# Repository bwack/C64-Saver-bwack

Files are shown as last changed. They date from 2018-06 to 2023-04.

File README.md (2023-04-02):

C64 Saver v1 and v2
- Overvoltage protection for the C64 and its power brick.

Designed by BWACK 2018
CERN OPEN HARDWARE LICENSE v1.2
http://www.ohwr.org/

The KiCad and other design files are available on GitHub:
https://github.com/bwack/

All text above must be included in any redistribution

# Warning: latest version of the savers are not tested.

# Bwack's C64 saver designs.

The C64 Saver 2 is an open-source project intended to make overvoltage protection available and easy to make for anyone interested in using the old Commodore power brick together with the C64. The power brick is 30-40 years old, and it is known for failure with overvoltage. This is caused sometimes because of broken solder joints on the regulator or the regulator itself failing.

## What has changed in v2 ?
- The design is modular.
- Spike protection. Handles hotswapping and switch bouncing better.
- It is much much easier and faster to make. Most people can make it!

## The base board (C64 Saver 2 SMD or Throughhole)
The base board is all you need for overvoltage protection. Through hole parts except for the mosfet, but it is large and easy to solder, no special tools needed other than your solder iron. The board shape fits the Hammond 1551g project case.
* Note: You need to bridge pin 4 and 5 in J2 and pin 4 and 5 in J4 if you are not using the base board in combination with the addon board or the relay board. The reason for this is that, with the addon board, we need to route the current through a sensing circuit. When the addon board is not used, we need to route it directly to the mosfet and terminals.

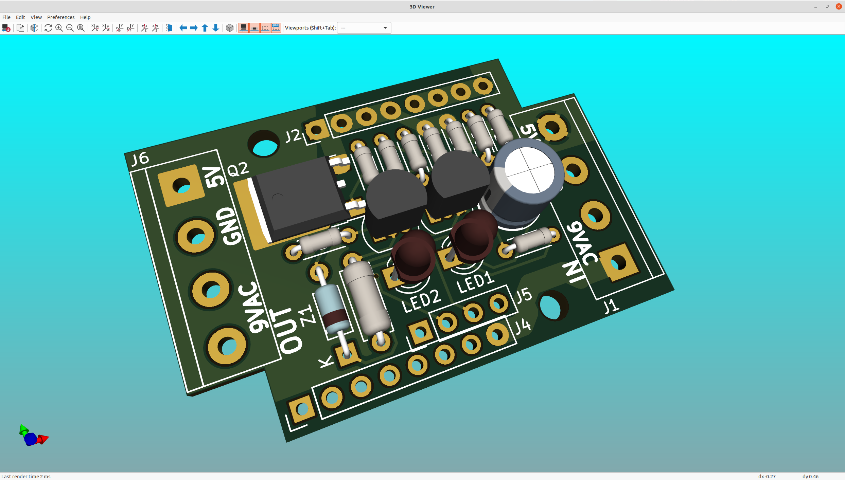
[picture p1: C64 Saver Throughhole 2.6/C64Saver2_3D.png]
C64 Saver 2 3D
 
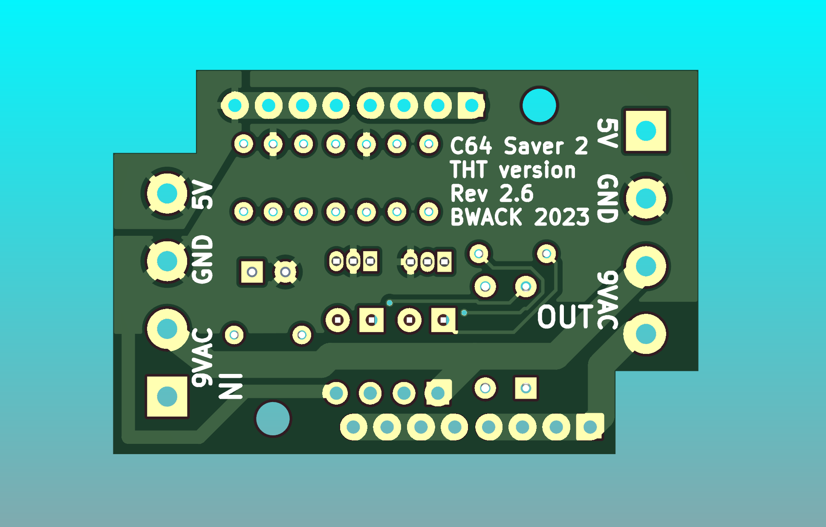
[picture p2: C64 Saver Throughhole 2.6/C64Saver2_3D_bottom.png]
C64 Saver 2 3D_bottom
 
 
There is also a SMD version for those who like to reflow soldering.

## The addon board
The C64 saver addon board is a hat for the base board, and adds software control, instrumentation on both ac and dc side, and an optional 128x32 OLED display. The aim for this project is to make a tool for C64 repairers. The 9VAC and 5VDC are fully isolated. Software control and instrumentation is useful if you are repairing C64s. You can set the output to shut down in case of an overcurrent condition. If an overvoltage happens you can configure the saver to auto reset or keep the power from comming back on again. There are several reasons why you might want this. C64 PSUs that need service, the capacitors are dry and the 5VDC has an AC component on it. The saver would normally just go on and off at 100Hz. The software control can detect this. The other problem is if the computer has a faulty chip that cause massive current draw on the 5V. The fuse might not blow because it is not enough, then you can configure the saver cut if you desire. I'm not gonna lie. This is my pet project, and the cost has not been a topic on my mind.

The C64 Saver Addon Board 1.4:

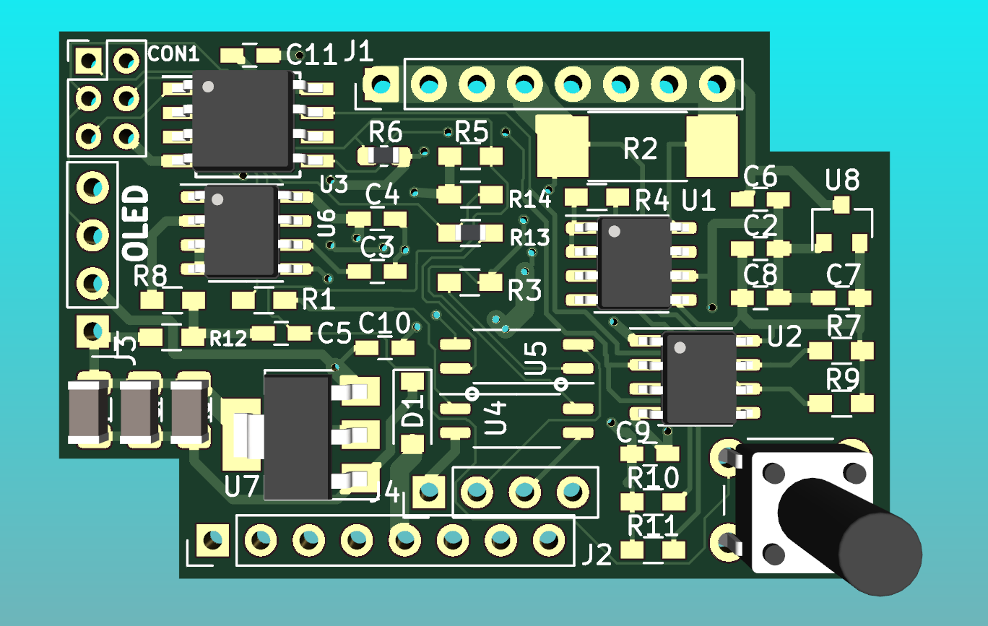
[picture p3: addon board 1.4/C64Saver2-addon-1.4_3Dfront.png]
C64 saver addon_board


Youtube video of me testing the addon board installed on the C64 Saver 2.

YouTube: Testing_the_addon_board (http://www.youtube.com/watch?v=oYrapS5jUx8)

The relay and hold board is archived in the oldfiles folder.

## C64 Saver OCP

OCP, not robocop, but overcurrent protection. Is a new circuit that I'm working on. It has three LEDs and a button. The overvoltage protection circuit is the same as before. The overcurrent will light the yellow led and keep it lit and keep the output OFF after an overcurrent event.

## The old design
I have decided to release my older C64 Saver v1. The board that fits inside a connector. Time and skill is super high on this product so be warned ! (SMD 0603, solder blob connections, tight spaces and short circuit hazards).

## Gerbers
If you are looking for gerbers, click the releases tab. There you will find a zip file of gerber for each release.

# BOM
All bill of materials (BOM) are moved into the respective project folders. I have added digikey etc order no. in the parts in the schematics such that they will show up in the interactive boms.

Here are the interactive BOMs:

[ibom for C64 Saver Throughole 2.6](https://htmlpreview.github.io/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)

[ibom for C64 Saver SMD 2.6](https://htmlpreview.github.io/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)

[ibom for C64 Addon Board 1.4](https://htmlpreview.github.io/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)

[ibom for C64 Saver OCP 0.1](https://htmlpreview.github.io/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)

# Changelog:

- C64 Saver 2.6 (THT+SMD) and Addon Board 1.4 (2023-04-02)
  - Replaced 7n2002 with BC547/BC847 to fix the tolerance issues.
  - Throughhole and SMD: same version numbers, same circuits, same reference numbers.
  - Red LED is switched by TL431 and Green by BC547/BC847.
  - Added LEDs to the Throughhole version. It was a challenge.
  - Fix: The Addon Board 1.3 had incorrect pinout for the 5V reg.
  - I never tested the Addon Board 1.3, but thanks to Retroisten who sent.
  me images and advicing me about he pinout, I'm very happy about it. He also
  showed me that it does work, with the regulator hacked in.  In this version 1.4
  it is working.

- C64 Saver 2.5 (SMD) (2020-09-13)
  - Added fault LED and power LED
  - 0805 SMD resistors
  - SOT23-5 TL431 and NMOS

- RelayHold 0.2 (2019-08-25)
  - Initial release
  - All through-hole parts.

- Addon Board 1.3 (2019-05-24)
  - Changed optocoupler footprint to more common SOIC-4_4.55x2.6mm_P1.27mm
  - Larger 5V regulator on 9vac side for less heat
  - replaced 100uF tantalum with 3x 47uF 1206 MLCC
  - kicad 5.1.0 project

- Addon Board 1.2 (2018-11-11)
  - Swapped HOLD_ with SENSE_VAC on the MCU. SENSE_VAC needs ADC.
  - Correct the mixed up SDA and SCL.
  - 5V supply to the 5V section is moved to VIN+ (before the shunt).
    To not pull power through the sensing resistor.
  - 4k7 I2C pullups.https://htmlpreview.github.io/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

- C64 Saver 2.4 (2018-09-23)
  - Support lower Vth on Q1. Resistor divider R7 and R8.
  - Remove C2 to make room for resistor divider.
  - Changed R5 to 3k3 to reduce BOM size.
  - New layout and routing.

- Addon Board 1.1 (2018-09-23)
  - ATtiny85 is a 8S2 package and two mm wider than SOIC8.
  - Read overvoltage signal on reset pin using ADC. Added voltage divider.
  - Replace MCP1700 with MCP1703. Supporting higher Vin_max

- C64 Saver 2.3 (2018-08-18)
  - Q1 2N7002 pin 1 and 2 rotated
  - Q2 Reversed drain and source
  - Increased pullup on Q1 drain.
  - Repurposed R5 as pullup for Q1 drain.
  - tested bodged v2.2 prototype, wohttps://htmlpreview.github.io/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!

- C64 Saver 2.2 (2018-08-16)
  - R1 was rotated.

- C64 Saver 2.1 & Addon 1.0 (2018-07-23)
  - 5x 9VAC pins. 9VAC1 current (4x) + 9VAC2.
  - Moved GND pin.
  - Changed board size to fit Hammond1551g
  - C64 Saver board:
    - Smaller throughole resistors
    - Moved C1 closer to input circuits.
  - Addon board:
    - VAC sense circuit with voltage divider.
    - 5V regulator on VCC pin. RAW pin disconnected.
    - Pullups on I2C busses.
    - SSOP-4 optocoupler packages
    - Another regulator on the 5V side to protect the iso1541 and ina219.

- C64 Saver 2.0beta & Addon 1.0beta (2018-07-02)
  - New design.
  - Protected sensitive parts.
  - baseboard: throughhole parts.
  - C64 saver 2 addon board.
  - problem: has conflicting pinouts.

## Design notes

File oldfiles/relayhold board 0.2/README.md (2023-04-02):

# The C64 Saver 2 relay hold board

The addon board is for many hard to make. I was thinking, what about making a board that doesn't need to be programmed, that can cut 9VAC, and optionally keep the outputs disabled even if the fault goes away. This circuit is it. It was more of an experimental circuit. I've therefor archived it here.

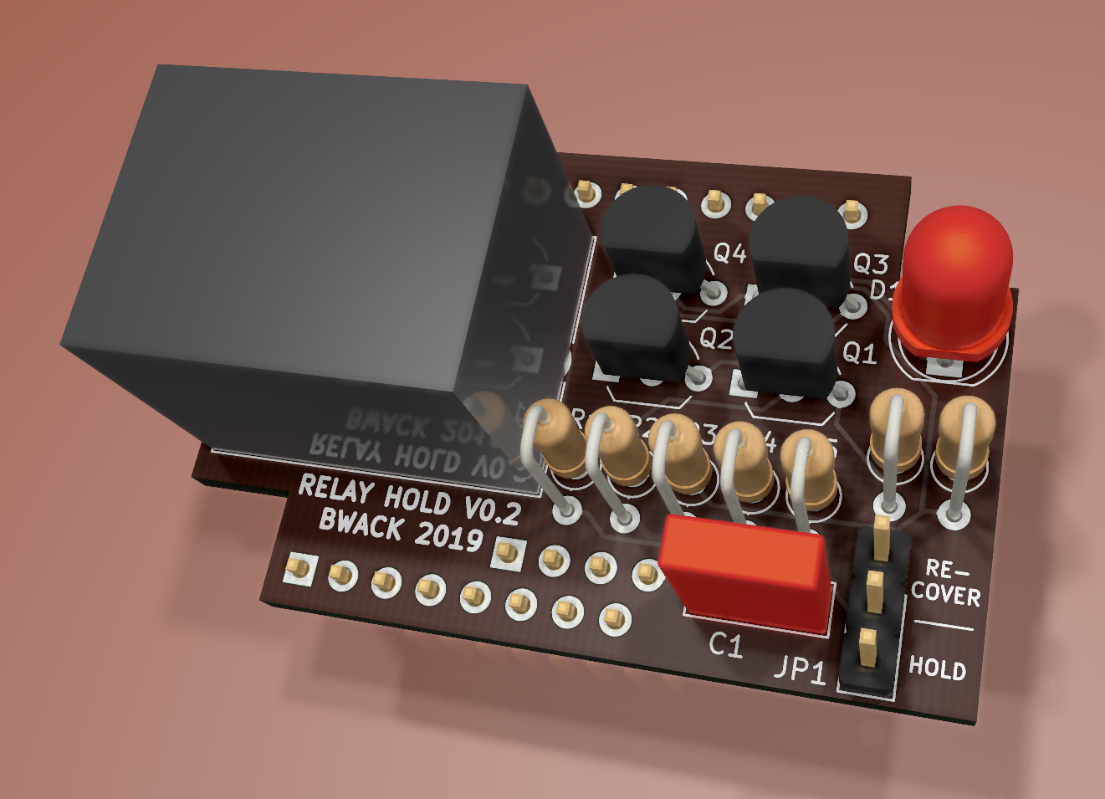
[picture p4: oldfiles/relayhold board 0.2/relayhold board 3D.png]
C64 saver relay hold 0.2


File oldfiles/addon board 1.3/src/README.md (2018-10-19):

# Firmware for the addon board

Build source code with avr-gcc.
This section is under construction.

## Programming
Program the addon board using USBasp or other AVR programming ISP device.
Arduino as ISP does also work. The ISP header has 2mm pitch, and the pinout is standard 2x3 way ISP pinout. You program the board with the main.hex file. It is found under the releases tab.

## Developing
To build the project you need to download the C64-saver-bwack repository from github.
From there you will get the sources for the addon board.
Download the WinAVR (windows), or avr-gcc (linux, mac). The avrdude version might not be
compatible with your USBasp. Download arduino also, and copy avrdude from it and into your WinAVR bin folder.

In the src folder you can clean, build and program.
- make clean
- make
- make install

## contributing to the Github repository
Fork the project and make your changes. Make sure you "make clean" before push to the repo. We only want source code in the repo. Have fun!

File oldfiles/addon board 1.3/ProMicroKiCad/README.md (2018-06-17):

Pro Micro library for KiCAD
=======================================

This repo includes Pro Micro library.

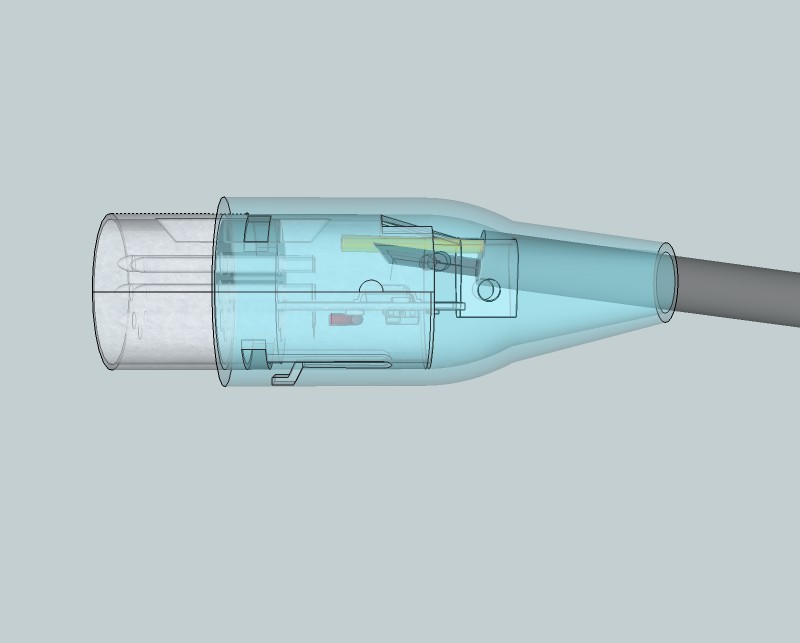
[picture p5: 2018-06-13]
oldfiles/C64 Saver 1/1.1-1.3/sketchup/c64saver_v1.2_Xray3D.jpg

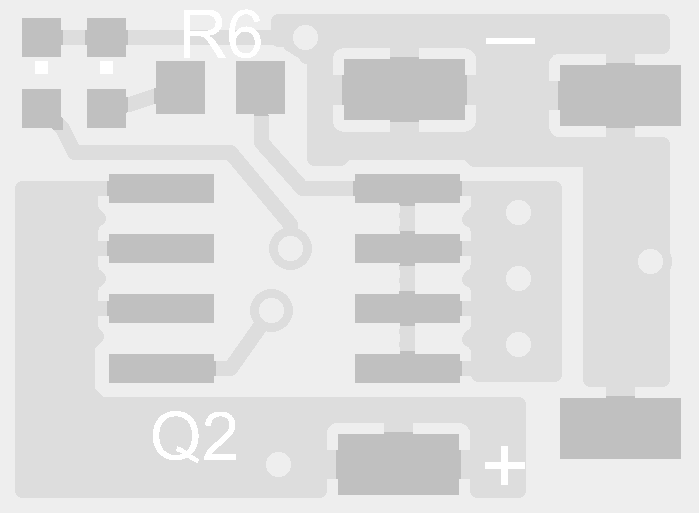
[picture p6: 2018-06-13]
oldfiles/C64 Saver 1/1.1-1.3/eagleUp-export/eagleUp_c64saver_1.3_board_bottom.png

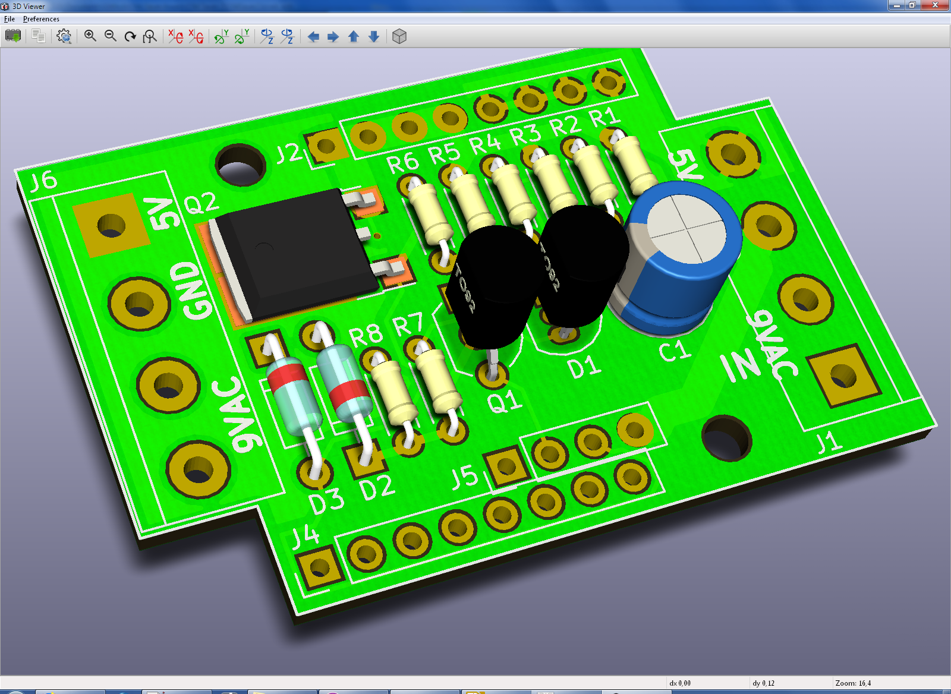
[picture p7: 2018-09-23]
oldfiles/C64 Saver Throughhole 2.4/C64Saver2_3D.png

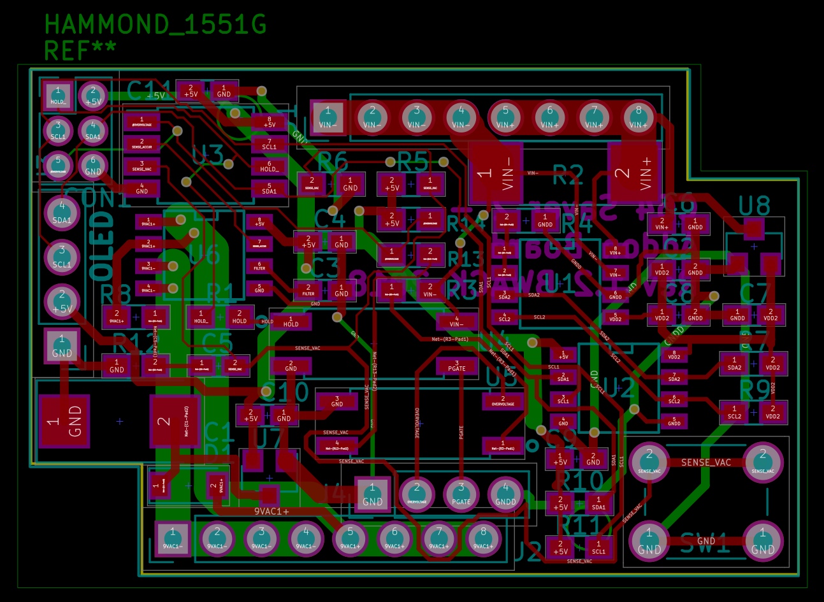
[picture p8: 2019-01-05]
oldfiles/addon board 1.3/C64Saver2-addon.kicad_pcb_1_2.jpg

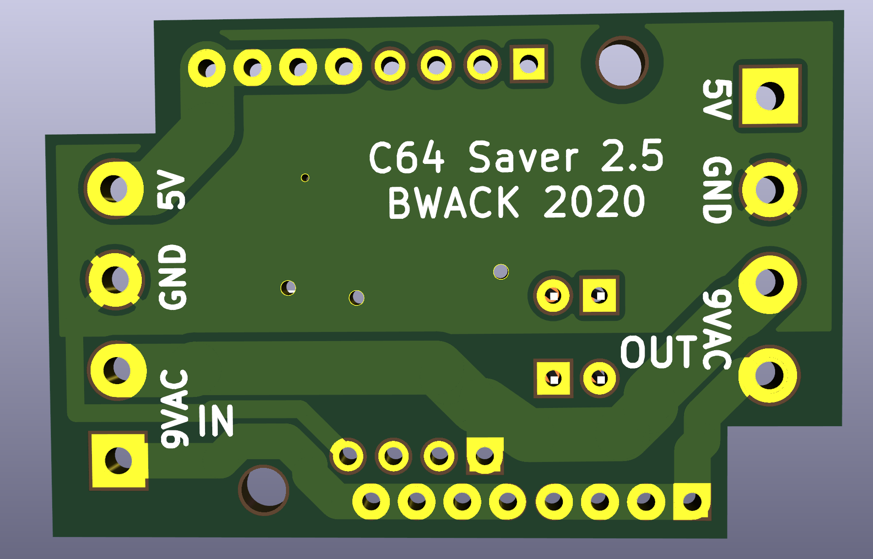
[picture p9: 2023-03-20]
oldfiles/C64 Saver SMD 2.5/C64Saver2_3D_bottom.png

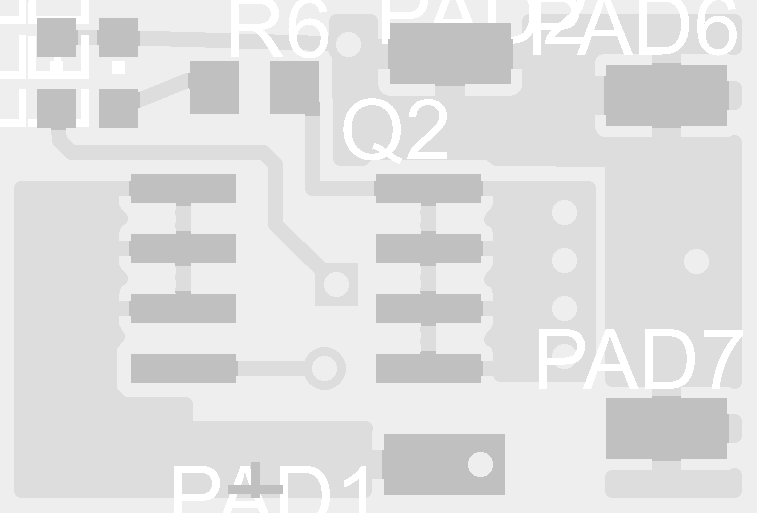
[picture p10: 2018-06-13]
oldfiles/C64 Saver 1/1.1-1.3/eagleUp-export/eagleUp_c64saver_1.2_board_bottom.png

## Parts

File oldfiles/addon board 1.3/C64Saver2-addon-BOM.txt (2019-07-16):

BOM for the C64 Saver 2 addon board v1.3
======================================== 

To be updated !

pcs  ref                 value     description                  elfa#       RS#
---------------------------------------------------------------------------------
1    C1
6    C2,C4,C5,   100nF     SMD Capacitor 0603                   301-11-165
     C8,C9,C11
4    C3,C6,C7,   1u        SMD Capacitor 0603                   300-87-136
     C10
1    D1          SL1G      SMD SOD-123 - Diotec SL1G            170-02-190
2    J1,J2       1x8       Conn Male Straight P2.54mm           300-93-649
1    J3          1x4       Conn Female Straight P2.54mm + OLED  300-93-664
1    J4          1x4       Conn Male Straight P2.54mm           300-93-645
4    R7,R8,R9,   4k7
     R10,R11
6    R1,R3       560R      Resistor SMD 0603                    300-37-977
1    R2          0R1       Shunt Resistor SMD 2512              160-30-965
2    R4,R13      10K       Resistor SMD 0603                    300-47-287
2    R5,R6       470k      Resistor SMD 0603                    300-37-953
1    R12         470R      Resistor SMD 0603                    300-37-950
1    R14         1K        Resistor SMD 0603                    160-15-663
1    SW1         SW_Push   SW_PUSH 6mm h13mm                    300-90-650
1    U1          INA219    SMD SOIC-8                                       817-6580
1    U2          ISO1541D  Optoisolated I2C tranciever SOIC-8   300-22-572  825-3075
1    U3          ATTINY85  MCU Atmel ATTINY85-SU,               173-21-927
                           SOIJ-8_5.3x5.3mm_Pitch1.27mm
2    U4,U5       ACPL-217-50DE
1    U6          ACS712    Hal-effect ADC I2C SMD SOIC-8                    680-7131
1    U8          MCP1703T  LDO 5V reg 16Vin_max                             775-7450
                           MCP1703T-5002E/CB SOT-23A-3

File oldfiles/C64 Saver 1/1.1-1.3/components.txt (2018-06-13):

The fet: IRF9333PBF (on sale)

Kontrollkabel uskjermet 4 x0.56 mm² uskjermet, UL-LIYY 4XAWG20, 2464/1061
10-416-96 19.90 pr meter

1   1k           R-EU_R0603         R7                                      
2   3k3          R-EU_R0603         R2, R3                                  
2   3k9          R-EU_R0603         R1, R4                                  
1   100k         R-EU_R0603         R5                                      
1   BSS84        BSS84              Q1                                      
1   IRF9332PBF   P-MOSFET-SO8       Q2                                      
1   RED_SIDEView LEDCHIPLED_1206    LED1                                    
1   TL431        TL431CLPSOT23      VR1

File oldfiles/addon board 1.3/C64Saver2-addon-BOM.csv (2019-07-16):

Item | Qty | Reference(s) | Value | LibPart | Footprint | Datasheet
1 | 3 | C1, C12, C13 | 47uF | Device:C_Small | Capacitor_SMD:C_1206_3216Metric | ~
2 | 5 | C2, C5, C8, C9, C11 | 100n | Device:C | Capacitors_SMD:C_0603_HandSoldering
3 | 4 | C3, C6, C7, C10 | 1u | Device:C | Capacitors_SMD:C_0603_HandSoldering
4 | 1 | C4 | 100nF | Device:C | Capacitors_SMD:C_0603_HandSoldering
5 | 1 | CON1 | AVR-ISP-6 | C64Saver2-addon-rescue:AVR-ISP-6 | Pin_Headers:Pin_Header_Straight_2x03_Pitch2.00mm
6 | 1 | D1 | Dotec SL1G | Device:D | Diodes_SMD:D_SOD-123
7 | 2 | J1, J2 | Conn_01x08_Female | C64Saver2-addon-rescue:Conn_01x08_Female | Pin_Headers:Pin_Header_Straight_1x08_Pitch2.54mm
8 | 1 | J3 | OLED_128x32_Conn_01x04_Male | C64Saver2-addon-rescue:Conn_01x04_Male | Pin_Headers:Pin_Header_Straight_1x04_Pitch2.54mm
9 | 1 | J4 | Conn_01x04_Female | C64Saver2-addon-rescue:Conn_01x04_Female | Pin_Headers:Pin_Header_Straight_1x04_Pitch2.54mm
10 | 2 | R1, R3 | 560 | Device:R_Small | Resistors_SMD:R_0603_HandSoldering
11 | 1 | R2 | 0R1 | Device:R | Resistors_SMD:R_2512_HandSoldering
12 | 1 | R4 | 10K | Device:R_Small | Resistors_SMD:R_0603_HandSoldering
13 | 2 | R5, R6 | 470k | Device:R_Small | Resistors_SMD:R_0603_HandSoldering
14 | 5 | R7, R8, R9, R10, R11 | 4k7 | Device:R_Small | Resistors_SMD:R_0603_HandSoldering
15 | 1 | R12 | 470 | Device:R_Small | Resistors_SMD:R_0603_HandSoldering
16 | 1 | R13 | 10k | Device:R_Small | Resistors_SMD:R_0603_HandSoldering
17 | 1 | R14 | 1k | Device:R_Small | Resistors_SMD:R_0603_HandSoldering
18 | 1 | SW1 | SW_Push | C64Saver2-addon-rescue:SW_Push | Buttons_Switches_THT:SW_PUSH_6mm_h13mm
19 | 1 | U1 | INA219xIDR-SOIC | ina219:INA219xIDR-SOIC | SMD_Packages:SOIC-8-N
20 | 1 | U2 | ISO1541D | iso1541d:ISO1541D | SMD_Packages:SOIC-8-N
21 | 1 | U3 | ATTINY85-20SU | C64Saver2-addon-rescue:ATTINY85-20SU | Housings_SOIC:SOIJ-8_5.3x5.3mm_Pitch1.27mm
22 | 2 | U4, U5 | ACPL-217-50DE | C64Saver2-addon-rescue:TLP291 | Package_SO:SOIC-4_4.55x2.6mm_P1.27mm
23 | 1 | U6 | ACS712 | acs712:ACS712 | SMD_Packages:SOIC-8-N
24 | 1 | U7 | MCP1703 | C64Saver2-addon-rescue:MCP1700-5002E_SOT23 | Package_TO_SOT_SMD:SOT-223-3_TabPin2
25 | 1 | U8 | MCP1703 | C64Saver2-addon-rescue:MCP1700-5002E_SOT23 | TO_SOT_Packages_SMD:SOT-23

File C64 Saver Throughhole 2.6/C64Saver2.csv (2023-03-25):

Source: | /home/hans/bwack-git/C64-Saver-bwack/C64 Saver Throughhole 2.6/C64Saver2.kicad_sch
Date: | Sun 26 Mar 2023 00:36:21 CET
Tool: | Eeschema 7.0.1-3b83917a11~172~ubuntu20.04.1
Generator: | /usr/share/kicad-nightly/plugins/bom_csv_grouped_by_value.py
Component Count: | 22
Collated Components:
Item | Qty | Reference(s) | Value | LibPart | Footprint | Mouser | kessler
1 | 1 | C1 | 47uF | C64Saver2-rescue:CP | Capacitors_THT:CP_Radial_D6.3mm_P2.50mm |  | 572309;0
2 | 2 | J1, J6 | Conn_01x04 | C64Saver2-rescue:Conn_01x04 | Connectors_Terminal_Blocks:TerminalBlock_bornier-4_P5.08mm | not used
3 | 2 | J2, J4 | Conn_01x08 | C64Saver2-rescue:Conn_01x08 | Pin_Headers:Pin_Header_Straight_1x08_Pitch2.54mm
4 | 1 | J5 | Conn_01x04 | C64Saver2-rescue:Conn_01x04 | Pin_Headers:Pin_Header_Straight_1x04_Pitch2.54mm
5 | 1 | LED1 | 3mm RED | Device:LED_Small | LED_THT:LED_D3.0mm | WP710A10LSECK/J3 | 513513;0
6 | 1 | LED2 | 3mm GREEN | Device:LED_Small | LED_THT:LED_D3.0mm | WP710A10LZGCK | 513512;0
7 | 1 | Q1 | BC547 | Transistor_BJT:BC547 | Package_TO_SOT_THT:TO-92_Inline |  | 500326;0
8 | 1 | Q2 | IRFR5305 | C64Saver2-rescue:Q_PMOS_GDS | TO_SOT_Packages_SMD:ATPAK-2 |  | 503060;0
9 | 1 | R1 | 3k9 1% | C64Saver2-rescue:R | Resistor_THT:R_Axial_DIN0204_L3.6mm_D1.6mm_P5.08mm_Horizontal |  | 550563;0
10 | 1 | R2 | 3k3 1% | C64Saver2-rescue:R | Resistor_THT:R_Axial_DIN0204_L3.6mm_D1.6mm_P5.08mm_Horizontal | RN55D3301FB14 | 550561;0
11 | 2 | R3, R5 | 3k3 | C64Saver2-rescue:R | Resistor_THT:R_Axial_DIN0204_L3.6mm_D1.6mm_P5.08mm_Horizontal | RN55D3301FB14 | 550561;0
12 | 1 | R4 | 330k | C64Saver2-rescue:R | Resistor_THT:R_Axial_DIN0204_L3.6mm_D1.6mm_P5.08mm_Horizontal |  | 550609;0
13 | 1 | R6 | 3k9 | C64Saver2-rescue:R | Resistor_THT:R_Axial_DIN0204_L3.6mm_D1.6mm_P5.08mm_Horizontal |  | 550563;0
14 | 1 | R7 | 33k | C64Saver2-rescue:R | Resistor_THT:R_Axial_DIN0207_L6.3mm_D2.5mm_P7.62mm_Horizontal |  | 550585;0
15 | 1 | R8 | 10k | C64Saver2-rescue:R | Resistor_THT:R_Axial_DIN0204_L3.6mm_D1.6mm_P5.08mm_Horizontal |  | 550573;0
16 | 2 | R9, R10 | 1k | C64Saver2-rescue:R | Resistor_THT:R_Axial_DIN0204_L3.6mm_D1.6mm_P5.08mm_Horizontal |  | 550549;0
17 | 1 | U1 | TL431LP | Reference_Voltage:TL431LP | Package_TO_SOT_THT:TO-92_Inline |  | 528636;0
18 | 1 | Z1 | 6V8 | C64Saver2-rescue:D_Zener_Small | Diode_THT:D_DO-35_SOD27_P7.62mm_Horizontal |  | 511511;0

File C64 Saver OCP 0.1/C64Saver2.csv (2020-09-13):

Source: | /home/hans/bwack-git/C64-Saver-bwack/C64 Saver 2.5 SMD/C64Saver2.sch
Date: | sø. 13. sep. 2020 kl. 18.38 +0200
Tool: | Eeschema 5.1.4+dfsg1-1
Generator: | /usr/share/kicad/plugins/bom_csv_grouped_by_value.py
Component Count: | 26
Individual Components:
Item | Qty | Reference(s) | Value | LibPart | Footprint | Datasheet
 |  | C1 | 47uF | C64Saver2-rescue:CP | Capacitor_SMD:CP_Elec_6.3x5.4
 |  | D1 | BZY55B6V8 | Device:D_Zener_ALT | Diode_SMD:D_0805_2012Metric_Pad1.15x1.40mm_HandSolder | ~
 |  | D2 | BZY55B6V8 | Device:D_Zener_ALT | Diode_SMD:D_0805_2012Metric_Pad1.15x1.40mm_HandSolder | ~
 |  | J1 | Conn_01x04 | C64Saver2-rescue:Conn_01x04 | Connectors_Terminal_Blocks:TerminalBlock_bornier-4_P5.08mm
 |  | J2 | Conn_01x08 | C64Saver2-rescue:Conn_01x08 | Pin_Headers:Pin_Header_Straight_1x08_Pitch2.54mm
 |  | J4 | Conn_01x08 | C64Saver2-rescue:Conn_01x08 | Pin_Headers:Pin_Header_Straight_1x08_Pitch2.54mm
 |  | J5 | Conn_01x04 | C64Saver2-rescue:Conn_01x04 | Pin_Headers:Pin_Header_Straight_1x04_Pitch2.54mm
 |  | J6 | Conn_01x04 | C64Saver2-rescue:Conn_01x04 | Connectors_Terminal_Blocks:TerminalBlock_bornier-4_P5.08mm
 |  | LED1 | LED_RED_3mm | Device:LED_ALT | LED_THT:LED_D3.0mm | ~
 |  | LED2 | LED_GREEN_3mm | Device:LED_ALT | LED_THT:LED_D3.0mm | ~
 |  | MK1 | Mounting_Hole | C64Saver2-rescue:Mounting_Hole | Mounting_Holes:MountingHole_2.5mm
 |  | MK2 | Mounting_Hole | C64Saver2-rescue:Mounting_Hole | Mounting_Holes:MountingHole_2.5mm
 |  | Q1 | 2N7002 | Transistor_FET:2N7002 | Package_TO_SOT_SMD:SOT-23 | https://www.fairchildsemi.com/datasheets/2N/2N7002.pdf
 |  | Q2 | IRFR5305 | C64Saver2-rescue:Q_PMOS_GDS | TO_SOT_Packages_SMD:ATPAK-2
 |  | R1 | 3k9 | C64Saver2-rescue:R | Resistor_SMD:R_0805_2012Metric_Pad1.15x1.40mm_HandSolder
 |  | R2 | 3k3 | C64Saver2-rescue:R | Resistor_SMD:R_0805_2012Metric_Pad1.15x1.40mm_HandSolder
 |  | R3 | 3k3 | C64Saver2-rescue:R | Resistor_SMD:R_0805_2012Metric_Pad1.15x1.40mm_HandSolder
 |  | R4 | 330k | C64Saver2-rescue:R | Resistor_SMD:R_0805_2012Metric_Pad1.15x1.40mm_HandSolder
 |  | R5 | 3k3 | C64Saver2-rescue:R | Resistor_SMD:R_0805_2012Metric_Pad1.15x1.40mm_HandSolder
 |  | R6 | 3k9 | C64Saver2-rescue:R | Resistor_SMD:R_0805_2012Metric_Pad1.15x1.40mm_HandSolder
 |  | R7 | 33k | C64Saver2-rescue:R | Resistor_SMD:R_0805_2012Metric_Pad1.15x1.40mm_HandSolder
 |  | R8 | 82k | C64Saver2-rescue:R | Resistor_SMD:R_0805_2012Metric_Pad1.15x1.40mm_HandSolder
 |  | R9 | 3k3 | C64Saver2-rescue:R | Resistor_SMD:R_0805_2012Metric_Pad1.15x1.40mm_HandSolder
 |  | R10 | 3k3 | C64Saver2-rescue:R | Resistor_SMD:R_0805_2012Metric_Pad1.15x1.40mm_HandSolder
 |  | R11 | 3k3 | C64Saver2-rescue:R | Resistor_SMD:R_0805_2012Metric_Pad1.15x1.40mm_HandSolder
 |  | U1 | TL431DBZ | Reference_Voltage:TL431DBZ | Package_TO_SOT_SMD:SOT-23 | http://www.ti.com/lit/ds/symlink/tl431.pdf
Collated Components:
Item | Qty | Reference(s) | Value | LibPart | Footprint | Datasheet
1 | 1 | C1 | 47uF | C64Saver2-rescue:CP | Capacitor_SMD:CP_Elec_6.3x5.4
2 | 2 | D1, D2 | BZY55B6V8 | Device:D_Zener_ALT | Diode_SMD:D_0805_2012Metric_Pad1.15x1.40mm_HandSolder | ~
3 | 2 | J1, J6 | Conn_01x04 | C64Saver2-rescue:Conn_01x04 | Connectors_Terminal_Blocks:TerminalBlock_bornier-4_P5.08mm
4 | 2 | J2, J4 | Conn_01x08 | C64Saver2-rescue:Conn_01x08 | Pin_Headers:Pin_Header_Straight_1x08_Pitch2.54mm
5 | 1 | J5 | Conn_01x04 | C64Saver2-rescue:Conn_01x04 | Pin_Headers:Pin_Header_Straight_1x04_Pitch2.54mm
6 | 1 | LED1 | LED_RED_3mm | Device:LED_ALT | LED_THT:LED_D3.0mm | ~
7 | 1 | LED2 | LED_GREEN_3mm | Device:LED_ALT | LED_THT:LED_D3.0mm | ~
8 | 2 | MK1, MK2 | Mounting_Hole | C64Saver2-rescue:Mounting_Hole | Mounting_Holes:MountingHole_2.5mm
9 | 1 | Q1 | 2N7002 | Transistor_FET:2N7002 | Package_TO_SOT_SMD:SOT-23 | https://www.fairchildsemi.com/datasheets/2N/2N7002.pdf
10 | 1 | Q2 | IRFR5305 | C64Saver2-rescue:Q_PMOS_GDS | TO_SOT_Packages_SMD:ATPAK-2
11 | 2 | R1, R6 | 3k9 | C64Saver2-rescue:R | Resistor_SMD:R_0805_2012Metric_Pad1.15x1.40mm_HandSolder
12 | 6 | R2, R3, R5, R9, R10, R11 | 3k3 | C64Saver2-rescue:R | Resistor_SMD:R_0805_2012Metric_Pad1.15x1.40mm_HandSolder
13 | 1 | R4 | 330k | C64Saver2-rescue:R | Resistor_SMD:R_0805_2012Metric_Pad1.15x1.40mm_HandSolder
14 | 1 | R7 | 33k | C64Saver2-rescue:R | Resistor_SMD:R_0805_2012Metric_Pad1.15x1.40mm_HandSolder
15 | 1 | R8 | 82k | C64Saver2-rescue:R | Resistor_SMD:R_0805_2012Metric_Pad1.15x1.40mm_HandSolder
16 | 1 | U1 | TL431DBZ | Reference_Voltage:TL431DBZ | Package_TO_SOT_SMD:SOT-23 | http://www.ti.com/lit/ds/symlink/tl431.pdf

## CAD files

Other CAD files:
oldfiles/C64 Saver 1/1.1-1.3/sketchup/pcbUp12.skp

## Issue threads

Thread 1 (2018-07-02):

voltage from 9VAC too high for the arduino pro micro's regulator (C64 Saver 2 addon)

bwack, 2018-07-02:
Unfortunately the board needs a regulator after the rectification of 9VAC. After rectification, and no load, the DC voltage is around 15V. The RAW pin of the pro micro is 12V max.

With a 9 or 10V regulator, the power dissipation of the regulators are split equally.

bwack, 2018-07-22:
using 5V regulators

Closed 2018-07-22.

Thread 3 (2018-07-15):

C64 Saver parts

juntek, 2018-07-15:
Since the IRF9332PBF transistor seems not to be manufactured anymore and is difficult to buy, which transistor would you recommend as a replacement for the IRF9332PBF?

bwack, 2018-07-18:
PMOS SOIC8
VGS max 20V or more
Vds max -30V less is also ok. Hsa to withstand -12V, but also spikes. so -30V is good.
Rds(on)@10V <50mOhm. Could be higher but then more voltage drop.

There is a lot of pincompatible ones.

bwack, 2018-07-18:
Try SI4497DY-T1-GE3. Seems awesome. 4mOhm Rds(on) @ 4.5V Vgs. The other specs are similar to the IRF9332.

VintageProject, 2018-07-27:
I wanted to add to the parts discussion.
I found that the original parts aren't easily to be found in Germany, or not at all.

So I tried to find suitable replacements.

**TL431:**
Not too critical.
Available replacement in the same case: TI TL431AILP

Mouser: https://www.mouser.de/ProductDetail/Texas-Instruments/TL431AILP?qs=sGAEpiMZZMtYFXwiBRPs0%2f7Wjg7mAO1C

**2N7002:**
Part number not found.
Available alternative: ON 2N7000

Mouser: https://www.mouser.de/ProductDetail/ON-Semiconductor/2N7000?qs=sGAEpiMZZMvAvBNgSS9LqnnYLgu9ZZAG

**IRF9332PBF:**
Phased out.
As bwack already stated, the alternative is the Vishay SI4497DY-T1-GE3.
Potential issue: The case is SO8, and only one of three source pins will be connected. Given that the original part only had one source pin, I don't expect an issue on this side.

Mouser: https://www.mouser.de/ProductDetail/Vishay-Siliconix/SI4497DY-T1-GE3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

Those are the parts that I found.

FYI: I think Mouser, despite having a German branch, always ships from the US. Expect lead times around a week if you cough up the FedEx delivery fees. Not too bad, but something to consider.

Reichelt.de was a nope, as I did only find the TL431 in an SMT package.

Cheers,
Thilo

discoHR, 2018-07-27:
Mouser has free FedEx shipping for orders over €50 (at least for Croatia). I buy all my stuff there and always spend €50+ per order. FedEx is super fast too, once Mouser sends the package it's on my door within the next 24 hours. It's 3 days waiting time on average. They're using "USA -> France (customs) -> EU country" route. Just pick the option for Mouser to pay the VAT at checkout, they'll automatically bill you the French VAT rate (20%) and that's all, no more hidden costs.

bwack, 2018-07-27:
Note that juntek asked for a part used in saver 1.x.

bwack, 2018-07-27:
I'll have a go at the saver 2.0 tonight to find the resistor values. R1, R2 and R4 are the ones that sets the threshold and hysteresis. I'll use the same values from C64 Saver 1.3. The circuits are very similar, Allthough R6 might have an effect on the hysteresis too. v1.x did not have this resistor. It's there for protection.

PDF: https://github.com/bwack/C64-Saver-bwack/blob/master/C64%20Saver%202.1/C64Saver2.pdf

bwack, 2018-08-09:
Mosfet C64 Saver 2: IRFR5305PBF

Closed 2018-11-30.

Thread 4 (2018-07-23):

Firmware for the addon board

bwack, 2018-07-23:
Programming the ATTiny85

We will use the Ardino IDE or avr-gcc toolchain.
For OLED display and ATTiny we will base our code on this project:
1. http://cyaninfinite.com/tutorials/interfacing-a-i2c-0-96-oled-display-with-attiny85/ or
2. https://www.instructables.com/id/ATTiny85-connects-to-I2C-OLED-display-Great-Things/

Number 2. seems the most interesting.

The MCU will be connecting with these devices over I2C
- INA219 current and voltage measurement (5V)
- ACS712 current sensor (halleffect, AC current)
- OLED 128x32 SSD1306

The 9VAC is fed in on a ADC pin, and is shared with the button. If the ADC reads around 0, then the button is pressed.

discoHR, 2018-09-03:
In your latest YouTube video you mentioned menu navigation. A single button is not enough for that. Can we have a pushable rotary encoder instead of the button? Are there any pins left on AtTiny?

discoHR, 2018-09-03:
Actually we could use a single button (long press to enter selection mode, single press in selection mode to change option and long press again to select it) but that would be awkward, especially for selecting cutoff voltage.

bwack, 2018-09-03:
I am very happy that you like to help on this. Very much appreciated !

discoHR, 2018-09-03:
No problem. Please send me the boards so I can start. Let me know (on Facebook or in mail) if there are any additional components I'll need. I'm going to order some unrelated stuff from Mouser in the next couple of days so I could order these components as well.

bwack, 2018-09-03:
Sounds great. Can you start with a breadboard setup ? I can send you display, ina219 breakout board and an attiny85 soldered on dip8 adapter. Do you have a usbasp or similar ?

discoHR, 2018-09-03:
I have only TL866A. I guess I could do it on a breadboard but I'd rather do it on a proper board, even if it means waiting longer.

bwack, 2018-09-03:
OK.

I noticed yesterday that I could not progam the attiny with ICSP. The setting for using ICSP was disabled/grayed out. Was able to do it with atmega328p, but not attiny85.

discoHR, 2018-09-03:
U2 seems to be interfering with ICSP. See linked thread for details.
https://www.eevblog.com/forum/projects/issue-programming-attiny-using-icsp/

hansdals, 2018-09-05:
That issue is different. The guy on the eevblog forum had a driver on the sck line, while we have a I2C isolator which is both high impedance and driving. The line should be high impedance normally. Lets see if it works.

hansdals, 2018-09-06:
If you like can you see if you can add the TinyWireW library to the project? I't is a C++ wrapper for another TWI library (coded in C) I think comes with the avr-gcc installation. Or we could use that library directly. Or go C++..

bwack, 2018-09-06:
Another USI-I2C code and interesting read about I2C
https://www.instructables.com/id/ATTiny-USI-I2C-The-detailed-in-depth-and-infor/
https://github.com/CalcProgrammer1/Stepper-Motor-Controller/tree/master/UnipolarStepperDriver

discoHR, 2018-09-07:
Thanks. This is a great I2C guide. Which slave I2C addresses are we using and which values can I expect from them?

Regarding libraries and mixing C with C++, I'm not a fan of either. I2C seems to be simple enough, it's just another way of bitbanging. I'm sure I can write my own code for that. Same for driving the OLED, I've done it in VHDL so doing it again in C should be straightforward. Using libraries is ok for complex stuff.

bwack, 2018-09-07:
if you use the usi hardware module, I think you only need to bit bang the serial clock. a bit weird how that works and that it is not fully hardware controlled.

Closed 2018-11-30.

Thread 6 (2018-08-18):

Needs more pullup on Q1 drain

bwack, 2018-08-18:
Add a resistor between 5V and Q1 drain. 4k7 worked fine.
Remove R5 (redundant).

bwack, 2018-09-22:
Changed to 3k3.

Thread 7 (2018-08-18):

Q2 reversed

bwack, 2018-08-18:
C64 Saver v2.2

Body diode pointing the wrong way. Pinout is correct though between schematic and datasheet for irfr5305.

bwack, 2018-08-18:
Tested with irf4905 with the other changes. Worked. IRF4905 is a D2PAK, and it is way too big though. I'm just using it for testing.

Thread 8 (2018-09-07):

Errors on the addon board

bwack, 2018-09-07:
Debugging the addon board 1.0 pcba

bwack, 2018-09-07:
U7 MCP1700 not handling over-voltage condition. Get MCP1754ST-5002E/CB
https://www.elfadistrelec.no/no/ldo-spenningsregulator-sot-23a-microchip-mcp1754st-5002e-cb/p/17386686

bwack, 2018-09-08:
When voltage is brought down below the threshold, the display stops updating. Not sure why.

Closed 2018-09-08.

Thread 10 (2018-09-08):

A signal is interfering with the RESET pin

bwack, 2018-09-08:
When voltage is brought down below the threshold, the display stops updating.
#OVERVOLTAGE is connected to the #RESET input of the MCU. **We need the reset for the ISP to work**. Here is a workaround: voltagedivider + adc !
https://electronics.stackexchange.com/questions/195146/use-the-reset-pin-on-attiny85-as-input-with-voltage-divider

addon board 1.0

bwack, 2018-09-08:
I have inserted the voltage divider and the display is running in both overvoltage and normal conditions.
I can't test the adc value at this point because I have joined 5V and 9VAC together, making the MCP1700 hit the dropout voltage if I try going under the threshold voltage. It shows that the voltage drops further when the state changes though.. So I'm happy with that for now.

bwack, 2018-09-08:
I hooked SDA back up, and programming works, but the display shows garbage if the programming header and power supply is on at the same time.

bwack, 2018-09-08:
connected SCL back, works fine.

bwack, 2018-09-08:
connected SENSE_VAC back onto MISO. Still working fine. I conclude that the OVERVOLTAGE signal connected to the RESET input was the one that interefered with programming.

bwack, 2018-10-06:
issue is closed becuase it has been fixes in addon board 1.1, but for debugging 1.0 here is what I have done to the board:
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

Closed 2018-10-06.

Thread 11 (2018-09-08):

ATtiny wrong footprint

bwack, 2018-09-08:
It's not SO-8, but two mm wider or so.

bwack, 2018-09-08:
KiCad had several SOIC-8 variants, including the correct one. Replaced it.

Ripped up many nets and will have to do some major layout again.

Closed 2018-10-06.

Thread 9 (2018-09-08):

Replace MCP1700 with higher max input voltage

bwack, 2018-09-08:
U7 MCP1700 not handling over-voltage condition. Get MCP1754ST-5002E/CB
https://www.elfadistrelec.no/no/ldo-spenningsregulator-sot-23a-microchip-mcp1754st-5002e-cb/p/17386686

addon board 1.0

Closed 2018-10-06.

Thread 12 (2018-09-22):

Resistor sizes

bwack, 2018-09-22:
C64 Saver v2.1 and 2.2:
The pcb has footprints for resistors DIN0207 3.6x1.6mm (main part x dia).
I have the 3.7x1.6 mm throughole resistors, and smaller than that are hard to get. They fit if you bend the legs as close as you can to the resistor.
The Kicad library does not have any sizer larger. if you're bored you can change the footprint by widening the distance between the holes by say 0.3mm.

Closed 2020-04-09.

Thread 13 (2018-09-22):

Vth of Q1 2N7000 too low

bwack, 2018-09-22:
I noticed this while ordering new 2N7002 nmos transistors. They measure Vgs threshold 1.9V. The other batch I have are 2N7000 and measure 2.5V. The minimum value shown in the datasheets are below 1V (!).

The problem is the TL431. Its output is also its power supply. The output will therefor not go below 1.8-2V.

bwack, 2018-09-23:
Resistor divider 33k over 82k on the N-gate seems to work fine.

Closed 2018-09-23.

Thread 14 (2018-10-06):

3D model of C1 shown the wrong way

bwack, 2018-10-06:
addon board 1.1 in the readme

Closed 2018-10-09.

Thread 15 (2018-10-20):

Code locks up when using the ssd1306 and ina216 libraries together

bwack, 2018-10-20:
@discoHR From what I remember when debugging this I saw that after the sd1306 library had the i2c and the ina216 was taking over, the code got stuck in a wait for high or wait for low call.. The libraries works fine on their own. Find out why one module screws up for the other.

Btw this is why I have included the usi_i2c_master library. This library is from the nunchuk64 project. From what I saw, the sd1306 library is a bitbanging library while the other two use the TWI module.

bwack, 2018-10-20:
I think it got stuck here. sorry too long ago I don't remember.. I suspect the ssd1306 libray, or the way we use it. maybe it needs to be freed or something. At least the i2c_master expects a state that it never gets. Could be a state set in the TWI register. Not sure.

i2c_master infinite loop problem:
```
	while (!(PIN_USI & (1<<PIN_USI_SCL)));		//Wait for SCL to go high

	#ifdef I2C_FAST_MODE
		USI_I2C_WAIT_HIGH();
	#else
USI_I2C_WAIT_LOW();
```

discoHR, 2018-10-21:
It's not the code, it's INA. I removed both usi_i2c_master and tinusaur-ssd1306xle code, disabled all interrupts and wrote my own I2C bitbanging code including autodetecting INA's slave address. There is aboslutely no response from INA at any slave address, it's not sending ACK at all. Thought it was working earlier but I was mistaking SDA going up for an ACK (technically, it's a NAK and it was going up because of the pullup, INA had nothing to do with it).

There is a lot of garbage on I2C bus immediately after power-up. Could be it's messing up INA's I2C but I added procedure for resetting INA's I2C bus before trying to talk to INA, same problem. INA's bus is reset when SDA or SCL are pulled low for at least 28ms.

Replaced R4 with 0 ohm resistor, same problem.

Checked optoisolator, signals seem to pass to both ends. There is about 4.2V on one end and 5V on the other but that shouldn't matter.

Removed optoisolator and tried accessing INA directly, same problem.

Either INA you sent me is dead or it's I2C doesn't work without a load. There is only 2.45 mV on the shunt resistor while the red LED is on, if it matters.

Ordered 2x INA219 from an EU seller, it will be faster than ordering from China.

Some screenshots...

I2C bus garbage on boot:
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

Autodetection of INA's slave address, no ACK was ever received:
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

Same as above but zoomed in. ACK missing. Pullup resistor is doing NAK, INA must pull it low for ACK.
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

bwack, 2018-10-22:
It could be both the ina and the issue I descibed above. Just beware of that.

bwack, 2018-10-22:
maybe the voltage on the ina's VDD is too low because of the drop-out voltage in the 5V regulator driven at V_IN=5V.

bwack, 2018-10-22:
Great work btw. Tell you what. I will hook up the addon-board to my c64 DIY PSU with ina219 voltage meter. I can easily unscrew the cables going to the ina and connect the addonboard and see if I get read-out on the PSU display (if you know, I have a C64 DIY PSU with ina219 and arduino pro micro)

bwack, 2018-11-02:
Taken from my C64 DIY PSU with only INA219 on the I2C bus. Data rate is 100kHz. Using adafruits ina219 library. You can see how it at very first writes calibration bits, and it does that several times too. Second transfer is the configuration h00. No reset command (that would be most significant bit set to h00.

Start, h80 [ h40 | WR ], h05, h10, h00, Stop
Start, h80 [ h40 | WR ], h00, h3C, h1F, Stop
Start, h80 [ h40 | WR ], h02, Stop
Start, h81 [ h40 | RD ], h27, hD2 NAK, Stop
Start, h80 [ h40 | WR ], h05, h10, h00, Stop
Start, h80 [ h40 | WR ], h04, Stop
Start, h81 [ h40 | RD ], h02, h9C NAK, Stop
Start, h80 [ h40 | WR ], h02, Stop
Start, h81 [ h40 | RD ], h27, hCA NAK, Stop
Start, h80 [ h40 | WR ], h05, h10, h00, Stop
Start, h80 [ h40 | WR ], h04, Stop
Start, h81 [ h40 | RD ], h02, h5D NAK, Stop
Start, h80 [ h40 | WR ], h02, Stop

bwack, 2018-11-03:
This is from with your code. I have replaced the pullups on my board now. oled disconnected.
```

Start, h80 [ h40 | WR ] NAK, h05 NAK, h10 NAK, h00 NAK, Stop
Error
Error
Start, h80 [ h40 | WR ] NAK, h00 NAK, h3C NAK, h1F NAK, Stop
Error
Error
Start, h80 [ h40 | WR ] NAK, h01 NAK, Stop
Error
Error
Start, h81 [ h40 | RD ] NAK, hFF, hFF NAK, Stop
Error
Error
Start, h80 [ h40 | WR ] NAK, h02 NAK, Stop
Error
Error
Start, h81 [ h40 | RD ] NAK, hFF, hFF NAK, Stop
Error
```

discoHR, 2018-11-03:
I tried with TinyWireM for Arduino, same problem. It's highly unlikely that both codes are faulty. The problem is most likely on the addon board itself. I've replaced 3 INAs so far and none of them sent any ACKs ever no matter what code I use. Please fix the board.

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

bwack, 2018-11-03:
let me try this first.

bwack, 2018-11-03:
SDA and SCL are mixed up.

bwack, 2018-11-03:
Regarding the title. The two libraries go well together. Example shown in the hans-doodle branch.
https://github.com/bwack/C64-Saver-bwack/tree/hans-doodle/addon%20board/src

bwack, 2018-11-03:
I'm closing this issue. Open a new one if you encounter a new problem.

Closed 2018-11-03.

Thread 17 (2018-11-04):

The 5V section draws power through the shunt resistor

bwack, 2018-11-04:
Current draw from the addon board shows up in the shuntvoltage readings.
To fix this the voltage regulator input must be moved from VIN- to VIN+.

Closed 2018-12-29.

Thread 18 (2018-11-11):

SENSE_VAC feeds in on non ADC input

bwack, 2018-11-11:
Suggest swapping it with SENSE_VAC PB1 with HOLD_ PB4. After swapping, check that MISO still works by programming the device. MISO is used for programming. HOLD_ is pulled thowards ground through the optocoupler diode. Suggest moveing HOLD to cathod and attach anode to 5V. Then HOLD_ is pulled thowards 5V which is probably better for SPI.

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

Closed 2018-12-29.

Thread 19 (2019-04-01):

No cut-off for 9VAC power line

juntek, 2019-04-01:
Since C64 uses 9VAC to power the SID chip, it is advisable for the 9V AC power line to be cut-off in case of 5V overvoltage as well. Otherwise the SID chip remains powered, while the rest of the computer is not.

bwack, 2019-04-01:
This will require a lot more components to fix something that will only happen in a 5V rail overvoltage condition. The sid will survive having only 9VAC supply running.

Closed 2019-07-06.

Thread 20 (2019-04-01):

BOM does not match current version

juntek, 2019-04-01:
As in topic - BOM file is version 2.3 while current version of the saver is 2.4

bwack, 2019-04-01:
Thanks. I will have a look. First I need to reinstall Open Office.

Closed 2020-08-29.

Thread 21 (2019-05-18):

U4,U5 EL1012 Discontinued

wishus3, 2019-05-18:
As the title states, the part as referred to in the BoM for U4, U5 as  https://www.distrelec.biz/en/optocoupler-sop-4l-80-everlight-electronics-el1012-ta-vg/p/11049956 is discontinued, and not available in North America any longer.
The schematic has parts U4, U5 referred to as TLP291.  Any TLP291 available at Digikey is a 4-SOIC (0.179", 4.55mm Width) that is NOT the same footprint as that on the PCB for the addon board.
Can you suggest any alternatives that fit the parameters of the EL1012 that is readily available and are the same package and size?

bwack, 2019-05-18:
The package is SO-4_7.6x3.6mm_P2.54mm. The online part selectors aren't very helpful to distinguish between 2.54mm and 1.27mm pitch and 7.6 long body. It makes it hard to find.  I see what you mean regarding TLP291. I found a LTV-817S on digikey. Same pitch, same length, might be a bit fatter. I'll try some measurements in kicad..........

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

ouff, it might be abit too fat. Let me know if you find a better fit. Electrically all of these optoisolated phototransistors will work. Timing and absolute max voltage is not a problem (slow and 5v).

bwack, 2019-05-20:
I'm changing the package to Package_SO:SOIC-4_4.55x2.6mm_P1.27mm in the next version.

wishus3, 2019-05-23:
I scoured Digikey and found the following:
https://www.digikey.ca/product-detail/en/vishay-semiconductor-opto-division/TCLT1012/TCLT1012CT-ND/8556846

I used the parameters to arrive at the substitute:

    Part Status:   Active
    Supplier Device Package:   4-LSOP (2.54mm)
    Number of Channels:   1
    Current Transfer Ratio (Min):   63% @ 10mA
    Current Transfer Ratio (Max):   125% @ 10mA

I am thinking this might be an acceptable replacement.  Would this work?

bwack, 2019-05-23:
They are very close in specs. Yes use those! Thanks for searching for it.

Closed 2019-05-20.

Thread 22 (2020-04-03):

Removed capacistor

SFK64, 2020-04-03:
Hi bwack
The capacitor you removed to make room for resistors, what was the function of that capacitor?
Regards
sfk

bwack, 2020-04-04:
This one ?
```
C64 Saver 2.4 (2018-09-23)

*   Support lower Vth on Q1. Resistor divider R7 and R8.
*    Remove C1 to make room for resistor divider.
```

bwack, 2020-04-04:
This is the PDF of v2.3
https://github.com/bwack/C64-Saver-bwack/blob/f3cd1549b32b5a40bd19ed1b33fe1eb53d38a0f0/C64%20Saver%202/C64Saver2.pdf

I think I ment to say removed C2 not C1.
I think it was there to stabilize the gate of the NMOS transistor, but a transistor there together with a resistor divider would slow down the reaction time.

SFK64, 2020-04-27:
Yep must be C2 :)
Ok thank you very much for the answer.

bwack, 2020-04-27:
Thanks for letting me know :)

Closed 2020-04-27.

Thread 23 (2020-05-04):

Gerber for addon board not latest version

wishus3, 2020-05-04:
"If you are looking for Gerbers, click the releases tab. There you will find a zip file of Gerber for each release."
Clicking on Releases only nets AddonBoard1_2_gerber.zip.
Has v1.3 not been released as Gerber yet?

bwack, 2020-05-04:
Thanks for feedback. V1.3 where only locally here on my file and never sent to github. Here they are now:
https://github.com/bwack/C64-Saver-bwack/releases/tag/addon1.3

bwack, 2023-03-19:
Hi wishus3. Did you try building this ?

Closed 2020-05-09.

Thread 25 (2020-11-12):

Optimizing gate voltage for Q1

franky1969, 2020-11-12:
I have built the Saver 2.4 Throughole but the output voltage was  not disconnected at overvoltage.
I meassured the output voltage of U1 (TL431) at overvoltage with 1,8V. The gate voltage of Q1 (2N7000) was after the divider 33k/82k at about 1.3V.
According to the Datasheet of the 2N7000 the Gate-Threshold Voltage of  is between 0.8 an 3V
I did not find the the max output voltage of U1 (TL431) in the datasheet. I think this is about 2V.
I think the values of the divider resistors should be changed. I changed the 82k to a 33k resistor this works with my parts.
Maybe further investigation is necessary.

bwack, 2020-11-14:
Thanks a lot for letting me know! I think I'll change the 2n7000 to 2n7002 due to the wide spread Vgs threshold.

franky1969, 2020-11-14:
According from the Datasheet from National Semi the 2N7000 is a pin version and the 2N7002 the SMD version.
The threshold Voltages are nearly the same:
2N7000 : 0.8V - 3V
207002 : 1V - 2.5V
The min. Voltage maybe the reason why there are less problems witch the SMD Version.

bwack, 2020-11-14:
You are right. The problem is also with the smd version.
I think if I can't find another nmos, I can go with an npn bipolar transistor. The resistors are there anyway, so it would be a job to ensure Vth, I_b, hFE and I_KA of the tl431 (which is plenty anyway).

bwack, 2020-11-14:
V2.5 for reference:
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

franky1969, 2020-11-14:
The Voltage divider i have chosen has an factor of 0.5 with R7/R8. So we can get 1V this is at least on the min. threshold of the MOSFET but in worst case we need 6V (threshold max. 3V) to switch the MOSFET.
So the divider is no save solution for the MOSFET but witch an bipolar transistor it should work.

I think, i have another possible solution for the SMD Version. In the Wikipedia artikel about the TL431 i found this:

"On-state VCA drops to around 2 V, which is compatible with Transistor–transistor logic {TTL) and CMOS logic gates with 5 V power supply.[40] Low-voltage CMOS (e.g. 3.3 V or 1.8 V logic) requires level conversion with a resistive voltage divider,[40] or replacing the TL431 with a low-voltage alternative like the **TLV431**.[41]"

bwack, 2020-11-24:
Very interesting. I looked it up. One reason for choosing TL431 is the high V_KA absolute max ~40V ish, while tlv is 10V. It would need some clamping i guess. I think maybe a bipolar is fine.

macacob, 2022-05-02:
I recognize this is an old post but I am experiencing the same issue. I tested up to 7V and output voltage was not disconnected.  I'm going to try replacing the 82k resistor with a 33k as suggested by frankly1969.  I have rechecked my work and everything seems correct (correct components, good solder joints etc).  Any other suggestions?

Thanks very much for your work on this by the way. Really a great project that should help keep more C64s alive for years to come.

bwack, 2023-03-19:
Has anyone looked at this problem? In short, the challenge is that the "output" of U1 does not go to 0 V, it goes to around 2V and varies with device to device. Then there is the threshold level of 2n7002, which have worked for me, but because of tolerances it may not work for another board. Suggestions welcome. I might have a closer look myself.
The pandemics and chip shortages amongst other events killed this project for me. I see some people building it over at forum64, and this might kickstart some interest to continue (or not).

bwack, 2023-03-19:
I've been simulating a tl431 with cathode voltages from 1V to 2V. With a bipolar npn transistor, the threshold is a lot more stable in the bipolar transistor than the nmos transistors. Also, not much change is needed to the layout (if any? I presume some pin re-arrangement). The R7 and R8 can be set to 330k and 100k.

franky1969, 2023-03-19:
Hi bwack,
do you still have the 2V problem with die bipolar solution? Maybe this is the red LED in the V2.5 Version. If there is no load connected to output, you get about 2V from the LED current trough R9/R10.

bwack, 2023-03-19:
Hi again. This problem is with the threshold of 2n222 and variation in tl431. Regarding the led problem we can have a look at that in another issue :)

bwack, 2023-03-19:
maybe i misunderstood. im playing with lt spice now. I'd like to take out the leds until i figure out the problem with tl431 and 2n2222.

franky1969, 2023-03-19:
Sorry, i miss understood your post about the output of 2V from U1. Forget my posting about the LED it has nothing to do with this topic.

bwack, 2023-03-19:
No problem. I'm simulating with a npn transistor now and it can work. A bc547 seemed to work fine..

bwack, 2023-03-20:
This is what I've come up for the new throughhole version.

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

Two leds, powered by the active components (D1, Q1). Removed zener at Q1. Rotated the two TO92 packages to block less of the ground fill. Believe it or not I managed to get all components on the pcb and route them. not pretty but functional i hope.

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

franky1969, 2023-03-20:
Looks very nice. I have put this in my ltspice, which i found from two years ago. The BC547 is switching at about 2.5V. So this should work fine.

bwack, 2023-05-20:
I'm testing now and it seems to work, however I cannot test for parameter spread thouhg. I noticed that the V_DS was high. I'll make another issue about it.

Closed 2023-07-18.

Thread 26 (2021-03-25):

2.4 Throughhole C2

mikedarzen, 2021-03-25:
Thank you for creating this project.  I'm in the middle of the build of V2.4 Throughhole, and I think C2 in the BOM might be an error.   I don't see where this fits into the actual circuit/circuit board.  Is C2 needed/preferred somewhere?

mikedarzen, 2021-03-25:
Also THANK YOU for making this.   I tested my power supply a week ago and it was right around 5V.  I haven't used it since.  I tested this with a regulated power supply and it performed just as expected.  I plugged in my c64 power supply and it showed no pass through voltage on the 5V rail.
I tested my c64 power supply directly and it is now showing 12V on the 5V pins!  I'm so glad I decided to build this before I did any further testing.

MindFlareRetro, 2021-03-25:
> Thank you for creating this project. I'm in the middle of the build of V2.4 Throughhole, and I think C2 in the BOM might be an error. I don't see where this fits into the actual circuit/circuit board. Is C2 needed/preferred somewhere?

Hi Mike. If it helps, I have been using this BOM with great success, http://bit.ly/mfr-c64saver-24-bom. I also did a video series of my experience if you are intersted, https://bit.ly/mfr-series-c64saver.

Regards,
Mark / MindFlareRetro

mikedarzen, 2021-03-25:
That's awesome, thanks Mark!  I'm looking forward to watching your series.  I always enjoy watching what people are doing with their c64s.

bwack, 2021-03-25:
Glad you like it. The C2 was removed in V2.4. I have forgotten to edit it out of the BOM.

mikedarzen, 2021-03-25:
Thank you!

Closed 2021-03-25.

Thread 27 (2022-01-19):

Images not showing

magazaki, 2022-01-19:
Hi,great project!

Just wanted to let you know that the images for "The C64 Saver 2 (base board)" in the Wiki are not showing, -the links are broken.
brg
Magnus

bwack, 2022-02-08:
Thanks x2 ! :)

Closed 2022-02-08.

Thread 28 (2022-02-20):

PCB dimensions

tony359, 2022-02-20:
Hello there,
Apologies if this is a silly question or not the right place where to ask but I am a bit lost.

I wanted to have some C64saver v2.4 through hole PCBs manufactured but the various manufacturers are asking me the PCB size.  Could you please point me to the right direction where to find that information?

Thanks a lot!

tony359, 2022-02-21:
Apologies, my mistake in downloading the gerber files. No issues here.

Closed 2022-02-21.

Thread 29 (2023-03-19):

U7 wrong pin configuration addon board 1.3

bwack, 2023-03-19:
U7 5V regulator got very hot and was therefor changed (see changelog) four years ago. Someone requested and got gerbers from me a year later. I had stopped working on it. I never got feedback about this until last thursday.
Pull requests welcome (just kidding). I will update when this 1.3 has been tested and all bugs have been ruled out.

Closed 2023-04-02.

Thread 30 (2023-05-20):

High voltage drop over the power MOSFET

bwack, 2023-05-20:
I measure V_DS=200mV at V_GS= -5V and I=1.2A.
We would like the voltage drop over the C64 Saver to be as low as possible, in case someone is using PSU with voltage on the low side of the VDD tolerance (which is 5V +-0.25 V ?)..

In Saver 1.3 I did a lot of testing for voltage drop over the whole circuit and was quite happy with it with using IRF9332. It promised Rds(on)=28.1 mOhms at V_GS=-4.5V. The C64 draws about 0.8A. For 1A draw, we would hve 30mV drop or less. Unfortunately this has a different package than what I'm using now.

Then when I made the Saver 2 I selected a part that would give similar results. So why this high voltage drop now ?
Has the part changed ? Are there variations to the IRF5305 ?
Nobody has complained about this. I guess it works well for those who use it, but the thing is, I built myself a PSU after starting this project, and haven't been using it much myself, but when I have used it, It has been working fine. Also I haven't touch this project for three years.

This needs more investigation, and lets continue to figure out what happened, and find a replacement part for this mosfet.
I would like to see a P-Channel mosfet, V_DS max 30V, R_DS(on)<=30mOhm @ V_GS=-4.5V. Imax is not so important because it is usually very high for these low resistance devices.

EverlastEngineering, 2023-06-17:
Hey Bwack!

I just ordered a short run of the new 2.6 TH board with enough components to build 5 to test out the new design. Is there anything in particular I should look for?

I've made a batch of these from an order on the back in 2020 (so, version 2.4? I forget tbh) and I test each one with a small and large load. I consistently find  a sharp cut off from between 5.39 to 5.44, which drops to 100mV then 0 after a moment.

I've never seen a voltage drop from in to out less than 10mV with my builds.

I'm unsure if this applies, but I toyed around with adding LEDs myself, and found issues no matter how I routed the "red" led. I would have voltage bleeding, or affect the V drop. I don't clearly remember anymore but when these boards come in I'll be able to compare 2.4 to 2.6 and see what I see!

I might even be able to swap some components that are the same to ensure it's not a variation of the components themselves if I find anything.

EverlastEngineering, 2023-06-17:
I'll have to confirm this, but it appears I used NCE55P15K from http://www.ncepower.com/.

bwack, 2023-06-21:
Not sure of anything obvious to look out for. Hopefully the latest version 2.6 is stable now.
The only issue I've found now is what this github issue is about, the voltage drop over the saver when the C64 is on and running.
One thing is that the voltage drop produces heat. If the PSU normally just supplies 5.00V or less, the voltage seen by the C64 can be too low.

You can use the IRFR5305 if you have a psu that produces more than 5.00 V under load. I'm using a custom PSU that produces 5.01V under load. The voltage is 4.76V when I measure over bypass caps near the chips. it works, it's not great.

I will order and try these mosfets:
https://no.mouser.com/datasheet/2/196/Infineon_IPD042P03L3_G_DS_v02_02_en-3164400.pdf
https://www.vishay.com/docs/67014/sqd50p03.pdf
https://no.mouser.com/datasheet/2/408/TJ40S04M3L_datasheet_en_20200624-1858407.pdf

LEDs:
I have also seen this issue with the bleeding in V2.5.  In V2.5 I was trying to save a bipolar transistor, but as you saw, it is impossible to turn the led fully off, the load (c64) can provide a path to gnd. That is something I've fixed in V2.6. I haven't tested the V2.6. I have tested the OCP V0.1 board, which has the same saver and LED circuits, and the leds worked fine there. No bleading there.

EverlastEngineering, 2023-06-30:
Boards are in and one was built tonight, it came together nicely.

I don't know what I was thinking earlier, because on the V2.4 boards I've been making there is about 80mV at 1A: 5.14V goes to 5.06V.

Unfortunately with the 2.6 design I'm seeing 160mV at 1A: 5.14V dropped to 4.98V 😬 The drop increases as the source V falls too:

`Volts       Drop`
`5.43V       0.13V`
`5.14V       0.16V`
`5.00V       0.24V`

Tomorrow night I'll drop on one of the mosfets from the 2.4V builds and see if that is any different.

EverlastEngineering, 2023-06-30:
Scratch pad maths says that V drop is about 160mW. Am I reading the datasheet for the IRFR5305 correctly, that the power disippation is 110...Watts?

EverlastEngineering, 2023-06-30:
Alright, enough spamming from me but after reviewing the datasheets, the 5305 specs the RDS(on) at VGS = -10V, ID = -16A.. and that's it. So I guess it shouldn't be a surprise. I think I got lucky with the NCE55P15K. I hope I see the same result from it on the 2.6 as the 2.4, then we'll wait to see what those three you order are like. I'll likely poke around LSCS and see what else is available. Maybe I'll look for something with a much lower current capability. It may yield something with a more favorable RDS(on) in the lower current and voltage range we're working in.

EverlastEngineering, 2023-07-01:
Looking through datasheets, not a bad way to spent a friday night. :)

Question: forgive my lack of knowledge around this, but why the specification for VDS max of 30V? If 20V was tolerable I see a number of SOT-23 that have specs at 4.5V and low current. SOT-23 is a mild PITA to solder for newcomers but no worse than their bigger cousins. For me the tend to disappear when tweezers slip. 🤣

I've noticed that with a lot of the big package MOSFETs do not have data plotted below 2A or even 5A, should they even _have_ a RDS(on) graph.

Those that do, often spec their RDS(on) resistance at least 10A, so could we expect the others without a graph to have similar specs at lower current? In other words, I draw the conclusion that many that have the high current capability to be unsuitable for lower current applications.

I'm off to build another 2.6 board, and I'll use a NCE55P15K from my last batch and then do a proper test tonight on the scope with time to voltage cut and look for any other anomolies.

EverlastEngineering, 2023-07-18:
I used the old mosfet from my last batch in a V2.6 board tonight, and I see the same 0.08V drop I did as in the v2.4 design.  I do notice a higher cutoff at 5.45V. That is the highest I've ever seen, the previous maximum was 5.44V and they're nominally 5.42V.

This test was conducted at a 1A load, btw. I think I'll just order another batch of NCE55P15K.

Did any of the fets you order come in?

bwack, 2023-07-18:
Hi. I've been on vacation. I will order components tonight. Also I will order a new revision of the OCP version.

Regarding the 30V spec, is because of high voltage spikes when power is switched on and off.
Thanks for checking.

Wait with ordering components. The NCE55P15K is not great, because I think you mention above as well, the <75 ohm resistance is at Vgs = -10V, meaning it will get even worse at less Vgs=-5V.

EverlastEngineering, 2023-07-18:
Hope you had a great vacation!

No, the NCE55P15K is the one that I'd been using in the past, 0.065ohm at -10V/16A. It doesn't have a spec on it's datasheet at 5V / 1A but reveals ~ 0.08ohm.

The reason I asked about the 50v / 30v maxiumum is due to the greater number of mosfets with  specs in the lower V/I range that have a 30V maximum. Have you seen spikes higher than this? If so, wouldn't the C64 have seen those spikes and died? :o
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
jhiggason, 2023-10-18:
@EverlastEngineering It's totally OK, I could have waited too. =)  I've got enough parts to at least try the hack job with the right mosfet.  Would you be willing to write out/sketch what changes need to be made please?  Excited to give this all a go =)

EverlastEngineering, 2023-10-18:
@jhiggason I'll snap a picture of the LED bodge tonight for ya, it's easy!

EverlastEngineering, 2023-10-24:
@jhiggason Sorry for the delay my dude, life finds a way to get in the way. :)

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

There’s two cuts, one below R10 and another to the left of the big resistor. This strands the zener so I connect it to the 5v in the headers.

I put the mosfet a little crooked so I’d have room to attach a wire to the safe 5v and ran it to the led.

Works well and is stable no matter the value of r10.

EverlastEngineering, 2023-10-24:
Here’s a close up with the traces you need to cut circled.

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

jhiggason, 2023-10-24:
@EverlastEngineering thank you so much! This really means a lot to me.  Hopefully I'll be able to post about success shortly!

Jeff

PS do you feel like we can order the 2.7 board yet?  I'd be willing to give it a go if you think it's good.

EverlastEngineering, 2023-10-24:
Wait a couple days and my prototype boards will arrive and then we'll know for sure! :)

jdecupere, 2023-10-27:
HI there
I am waiting for the boards to test the IRF9310, but meanwhile breadboarded the rest (so, all is included except the IRF9310) just to do some checks.
Just thought I'd share the quick check on startup behaviour here with some screenshots.
I used @EverlastEngineering suggested resistor split and 330 ohm +3.3k. This seems to give a trigger point around 5.28V in my breadboard.
Seems to work nicely and quickly :). In the final config, there will be a big cap from the C64 on the safe 5V as well as all kinds of load....so there would be no risk at all of getting even transient overvoltages it seems.

Blue CH2= 5V "unsafe"
Yellow CH1 = gate of the MOS power FET

V_in to 5.2V:
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

V_in to 5.35V:
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

EverlastEngineering, 2023-10-27:
^^ Awesome!

My boards arrived just now, I'll be building one tonight with a leftover mosfet that has the higher V drop to test out the rest of the changes.

In regards to scoping the results, I found something really interesting likely due to the cap on board buffering the voltage. When I first tested the 2.4 design I saw a spike, sometimes _considerable_ in the `5V_Safe` but I had no load at all while testing; that seems to be critical. With any appreciable load, right up to 1.2A, there was no spike at all. I'll see if I can get get a quick video of it.

@bwack why don't you open `Discussions` on this repo so we can carry on the convo's that aren't strictly related over there?

bwack, 2023-10-27:
Done, added discussions.

bwack, 2023-10-28:
No worries. You can discuss here if you like.
I have populated my c64 saver OCP v0.2 board. If I can get it up and running I will post some results.

bwack, 2023-10-28:
Having fun testing now. Just compared the IRF5305 to TJ40S04M3L. Pulling about an amp (0.99A). Seeing V_DS go from 218mV to 11mV !! Respectively! Wow!

EverlastEngineering, 2023-10-28:
We should make a wiki about mosfets that are known good and what spec to
look for when searching for alternatives. It’s a great way to learn about
data sheets.
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

bwack, 2023-10-28:
I invited you as collaborator. If you like to edit the wiki.
I'll put the alternatives i find into the boms.

Another measurement, same conditions as above (0.99A, VIN=5.01, V_GS=4.93):
SQD50P03: V_DS = 8 mV

bwack, 2023-10-29:
IPD042P03L3GATMA1: V_DS=4mV !

EverlastEngineering, 2023-11-05:
I've added a wiki with these values, so I'll close this issue now!

https://github.com/bwack/C64-Saver-bwack/wiki

Closed 2023-11-05.

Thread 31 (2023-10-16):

BOM?

jhiggason, 2023-10-16:
Hello!  First of all thank you for providing this.  It's a really great piece of equipment and I'm excited to try it out on my "new to me" c64 =)

I'm a very experienced electronic hobbyist- but building a board with Gerber files and parts is really new to me.  Do you have an actual part list somewhere?  Because I see something called a kessler number which doesn't seem to match up with any of my vendors for parts.  Let's say for C1.  It shows it is a 47UF cap that is CP_Radial_D6.3mm_P2.50mm....am I just going to mouser and trying to find caps that are round and the right size for the uF?   There are so many millions of parts that the options are a bit confusing for me.

Any help would be great appreciated. Thank you =)

jhiggason, 2023-10-16:
Ok folks- for others that might be someday joining in- I'm learning some specific things about components with gpt4's help.  For instance:  C1 would be:

47uF: This is the capacitance value of the capacitor.

CP_Radial_D6.3mm_P2.50mm: This suggests a few things:

Radial: This is a type of capacitor where the leads come out from the same side (as opposed to axial capacitors where the leads come out from opposite ends). Radial capacitors are commonly used in printed circuit board applications.

D6.3mm: This indicates the diameter of the capacitor is 6.3mm.

P2.50mm: This indicates the lead (pin) spacing is 2.50mm apart.

Then I could into mouser with this new information and start setting filters.  It doesn't say this explicitly but a decent cap would probably be at least 1.5 to 2 times the voltage requirements. Since we are at 5v, a 10v cap or 16v cap would work great.  25v is still fine and might be cheaper than some others.  (You can shift click mouser filters and select all 10v, 16v, and 25v caps)

The only other important filters are hours between failure (typically 1000 to 5000, the later being more expensive)  ESR and Ripple current measurements.  I'm not sure how important these are for this exact application but gpt4 thought a lower ESR and high ripple current is safer and would typically cost more.  Also temperature ratings as well.  Pick whatever.

jhiggason, 2023-10-16:
Here is a cap for C1 I found at mouser: https://www.mouser.com/ProductDetail/710-860240473003

jhiggason, 2023-10-17:
Ok I found on the SMA BOM it has an alt for the ATPAK-2 - so it must not be required.  Attached here is my BOM- I didn't include the 4pin and 8pin headers as I already have those.  If someone would be kind enough to cross reference my parts I would be eternally grateful.  Otherwise I'll probably just order and give it a go.

This is for Mouser.com

[Mouser_Cart_2023.xls](https://github.com/bwack/C64-Saver-bwack/files/12938158/Mouser_Cart_2023.xls)

jdecupere, 2023-10-17:
You should be fine. Atpak2 is the same footprint, just lower in height, I think.

EverlastEngineering, 2023-10-18:
Heyo!! Hopefully this catches you before you order. We've found the IRFR5305 isn't suitable, if you want the details you should check out the other open issue here.

Also, I found the cap to be a big too tall to fit in the case which is the standard hammond case size so I'll be looking for a slightly shortly one on my next order.

Finally, I found a couple small issues with the 2.6 design and have spent the night redesigning it a bit. So, perhaps hang on just a bit until this gets sorted? I'm about to place an order in the next day or two for pcbs and parts and then I'll know more.

Here's the redesign from tonight's marathon lol:

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

jhiggason, 2023-10-18:
@EverlastEngineering Oh noo!  I just ordered all the parts and the board, figured I'd give it a try.  I ordered enough for 5 boards...   Do you think I can use these parts on the new version or somehow make the version I have work?  I can also just order the new part and put in another order for the new version of the board if you think that would be better?

You are a rockstar btw!  Thanks again for all this.  I plan on writing some documentation for the through hole build I'm doing.  Are you guys in the US?

jdecupere, 2023-10-18:
I am no GitHub expert, but maybe it is better to continue discussing in the other issue (30) as what we discuss relates to the findings there.
meanwhile answering your last questions: it will work, but has some shortcomings (see issue 30): due to the ON resistance of the transistor you may have issues with power supplies that are on the lower side of the 5V spec…and the C64 Saver will get hot. @EverlastEngineering is also doing some other improvements.
(I am in Belgium btw)

jhiggason, 2023-10-18:
Yeah I think we can can close this issue and if I have any questions relating to issue 30 i'll ask there.  I'm new here- don't mind me ;)

Closed 2023-10-18.

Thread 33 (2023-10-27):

R10 in C64 Saver SMD 2.5

jueank, 2023-10-27:
Hi,
I'm referring to the 2.5 SMD version of the saver. Why is R10 (3k3) directly connected to 5V_SAFE, while on the PCB it's routed to positive pin of LED2 but merged with the 5V_SAVE plane? Negative pin of LED2 is connected through R11 (3k3) to GND. Is this an issue? If not, can you please explain?

jdecupere, 2023-10-27:
Hi,
As I was looking at the design anyway, I did a quick check - for the reasoning behind the design choice @bwack will need to answer.
I am not sure I understand the first part of your question. There certainly is no issue. The PCB connections are the same as the schematic. R10 connects to 5V_safe, as well as the LED2 anode...on the PCB one is drawn as a wire, the other through the fill plane...but in the end those are merged as 1 Cu layer (you can check the gerber file if you want to see how it looks), so it does not matter how the PCB trace is drawn.
Schematic-wise, having a resistor between 5v_safe and GND seems to be done to provide a path for the current to go to in case the input voltage is above the safe trigger point:
- If V_in > trigger, Q2 will be OFF, and the current will flow through LED1, R9 and R10 to GND -> LED1 should light up to indicate the "fault" situation. 5V_safe will be at some intermediate voltage - a little lower than V_in/2 (without additional load) but with high impedance so in case you have the C64 connected, any current draw will lower the voltage even more --> hence all is safe
- if V_in <trigger, Q2 will be ON and hence LED1 and R9 will not see a voltage across them and the LED is OFF; V_in is passed to 5V_safe and there will be a small 3mA current through R10 as "waste" and another path through LED2 and R11 to show that the 5V_safe is "live"

I think the later designs are more elegant, but this should not have an issue per se

BR,
Joost

jueank, 2023-10-27:
Thanks for the explanation. I know, the trace frm R10 to LED2 is merged with the 5V plane. I was just confused by the way it was done. Not sure if bwack has to add something to what you wrote!

BR :)

hansdals, 2023-10-27:
Not sure without digging up 2.5 from 2020. It could have been I had limited routing space. Also the led circuit was a late fix, snd wasn't done very well in 2.5 unlike 2.6.

bwack, 2023-10-27:
Not sure without digging up 2.5 from 2020. It could have been I had limited routing space. Also the led circuit was a late fix, and wasn't done very well in 2.5 unlike 2.6.

bwack, 2023-10-27:
Just to be clear, are you saying that the schematics and layout are different?

jueank, 2023-10-27:
No, there is no difference. It is just that the direct trace from R10 to LED2 - although merged with 5V plane - is explicitely routed, indicating a relationship of LED2 to R10. That COULD have been a mistake. I just wanted to be sure and asked therefore here.

bwack, 2023-10-27:
Oh as in the way the schematic is read it can look like there is a relationship, not intentionally. R10 was put there to provide a path for LED1 to GND even if the load is disconnected.

jueank, 2023-10-28:
Thanks for all so far. Since there is no fault, I think the issue can be closed. @bwack can I ask you something to the schematic then in a private discussion? I'll write it in a minute...

Closed 2023-10-28.

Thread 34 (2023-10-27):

Through hole Zener Diode Sizing

jhiggason, 2023-10-27:
Hey fellas.  Just getting around to putting this thing together.  The BOM for through hole zenners isn't very clear so I went to SMD bom and found the part number that was provided there.  Then I bought a zener based on that.  I only hesitate because this one is much smaller in size than the markings on the board.  Both are showing .5watts 6.8v 2% so hoping I'm OK.

What do you think?

The part I bought: https://www.mouser.com/ProductDetail/Vishay-Semiconductors/BZX55B6V8-TR?qs=WLTup5mM6hj4D2ZUwZwaKA%3D%3D

The part I referenced from the SMD bom:  https://www.mouser.com/ProductDetail/Taiwan-Semiconductor/BZY55B6V8-RBG?qs=mAH9sUMRCtuk9q3vqhCMbg%3D%3D

Thank you!!

EverlastEngineering, 2023-11-05:
Mmwm.... the part you bought is 1/2 watt while the one referenced in the kessler column of the bom is a _3w_.

I got the three watt one, but dannnnng he a big boy. 🤣 I'm thinking that it might a mistake, the V2.4 of the board spec'd two smaller ones and if the SMD also specs a small, I'm sure I'll be fine.

jhiggason, 2023-11-05:
So I have looked in detail at what the heck a Kessler number is...it doesn't seem to have a meaning in the US.   What website did you use to find a part based on that?  I'm thinking it might be an overseas vendor?

Thanks for your help on this.  I'll try out the .5w

jhiggason, 2023-11-05:
I found a reference to Kessler in your new wiki post. Others can go there to found out more.  Thanks!  https://github.com/bwack/C64-Saver-bwack/wiki

jhiggason, 2023-11-06:
@EverlastEngineering So thank you for providing that the kessler number was a german company + the link.  That has helped immensely.  For some reason, even knowing that it was a german company, I could find no record of it on google and even chatgpt was stumped.  It was driving me a bit bonkers.

So I guess a few things- the kessler number for zener diode is actually a 1.3watt device.  DO41 https://www.kessler-electronic.de/de/Bauelemente/Halbleiter-diskret/ZPY-6-8V

This is showing something different than even the bom which is showing a DO35 zenner.  I couldn't find 1.3 watt zeners that ship quickly so I went with a 1watt version of the same form factor (DO41).  Hoping that lines up better with what was planned.

@bwack How important is the 1.3watt zener for the safety of the circuit?  Will my 1watt be fine?

jhiggason, 2023-11-06:
Ok a bit more information- there appears to be 2 part numbers for the SMD version zener. 300mw 6.8v SMD https://www.digikey.com/en/products/detail/nexperia-usa-inc/BZX384-B6V8-115/1162926

Here is the other it references:  500mw 6.8v 2% BZY55B6V8  https://www.digikey.com/en/products/detail/taiwan-semiconductor-corporation/BZY55B6V8/18720320

So I'm not exactly certain.  You guys have any thoughts on this?

jdecupere, 2023-11-07:
Hi Jeff,
(note: this issue is closed, so maybe better to discuss in the discussions section)
As the zener is just meant to handle spikes (pos and neg) and will never have to pass large current, I don't think the Wattage rating matters too much. You want to have 6.8V breakdown to avoid issues in normal operation and other than that just the effect of (somewhat) reducing influence of the potential spikes - as bwack mentioned this can happen during hot swapping the connector.
I have even ordered a 0.5W one myself - boards still have not arrived, so cannot comment on actual measurements yet.
(mine is this one: https://www.reichelt.com/be/en/zener-diode-0-5-w-6-8-v-zf-6-8-p23142.html?r=1)

jhiggason, 2023-11-07:
@jdecupere Thank you for responding. =)  I'm definitely not an electrical engineer...so just making sure I'm not going to damage my C64 baby =P   I wasn't even sure how to test that the zenner was high enough wattage so figured it was wise to ask.  I will put together a wiki article on everything I've learn for other newbies like me once I'm done here. Thanks again.

jdecupere, 2023-11-08:
@jhiggason no problem..ask away! :)
almost 30 years experience in semiconductor (analog) design and electronics in general on my side...which does not mean I know everything, but glad to (try to) help anytime

bwack, 2023-11-08:
Maybe there are some zeners that are more suited for high voltage transients? Like tvs? I'm not too familiar with them. But yes th 3W i think is not important

jhiggason, 2023-11-13:
Thanks- I'll open a new request if I have any questions  Going to test with the 1watt.

Closed 2023-11-13.

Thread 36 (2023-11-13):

Soldered board (2.6 throughhole) with new mosfet not working =/

jhiggason, 2023-11-13:
Hey Fellas- I got my board together and tried a test for the first time last night.  I'm not getting any indication of power on the board.
I made the two cuts, installed a IPD068P, changed the zener location, and hooked up the LED but nothing.  I had the hardest time getting the two small transistors soldered(Q1, U1)  I'm wondering if I possibly heat damaged them?

Any troubleshooting steps I can follow?

I had the input hooked my bench power supply at 5V- I had a 10Watt, 5 ohm resistor on the output for a load.  Is the a proper method to test it?  If no- how would I better test the unit?

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

jhiggason, 2023-11-13:
@EverlastEngineering Did that new pcb design workout?  I might just go that route if yes...

jdecupere, 2023-11-14:
@jhiggason : this is an easy one: you forgot to solder the by-pass on the two pin header connectors that bwack has foreseen for the add-on boards to measure current. Since you do not have that add-on board, you need rot short it yourself. So on the 2 8-pin rows (left and right in your picture), short the middle two (so pins 4 and 5 if you will) - just a small wire, soldered in those 2 will do.
Don't worry about the heat damage....looks ok on the picture

jdecupere, 2023-11-14:
I was about to point you to it 😀 and then saw your edit.
I actually just remembered from the YT video that brought me to this design from MindFlareRetro

jhiggason, 2023-11-15:
Ok I have power!   But now I'm getting weird behavior-  Is there supposed to be a power led?  If yes- only 1 led appears to be working.

Applying 5V of power- with my 5ohm resistor I'm seeing about .80amps being drawn from my psu.  Output voltage is only showing 4.8V.  If I increase my input voltage to about 5.2- I see 5V output.   Is this because of my resistor?

When I increase input voltage- I see output voltage raise along side of it until I hit 5.6V - then the red LED comes on but nothing else seems to happen.  Isn't this the point where the circuit is supposed to cut power to the output?  Or is the purpose of the circuit to reduce power to the safe 5V?  Either way it doesn't seem to be working. Getting closer!

Thanks again for the help fellas.

jdecupere, 2023-11-15:
If I remember correctly from the other discussion on the BOM, you use the IRFR5305, correct? This is what @EverlastEngineering found out already: it has a high ON resistance with the -5V Vgs...around 0.2 ohm. This correlates to what you see as delta between input and output with your 5ohm load: drawing (a little less than) 1A gives you 0.2V drop.

One LED on when in a safe input range is normal. Should be the green one. When the voltage protection is active (so your input is above the threshold) then the red LED should be on....I think this seems to be working ok per your description.

The threshold of 5.6V seems correct as well with the BOM you used.
Are you sure nothing else happens? When you measure 5v_safe, it should now drop to 0v to close to it. Did you measure across your 5 ohm resistor?

jdecupere, 2023-11-15:
Ah...wait...you made the bodge @EverlastEngineering proposed...maybe that was not done correctly?

EverlastEngineering, 2023-11-16:
HI!! Sorry, I've been nutso busy.

Yes, the V2.7 boards seem to be working well! You can find the info in the PR that's open, but be warned, I ordered mine through EasyEDA in their own editor so it's not the _exact_ kicad file you see, I recreated it for this repo.

As far as the V drop goes, where are you measuring it from exactly? My power supply, set to, say, 5.2V will show as low as 5.0 at the input section of the board. But the real critical part is measuring the voltage drop from the 5V in to the 5V out. This is where the IRFR5305 failed badly but the ones in the wiki all seem good.  I can't tell in the pic which MOSFET you have installed.

Next, I will go back and look at your LEDs issue.

EverlastEngineering, 2023-11-16:
@jdecupere was correct, I have a jumper on the outside pins of j5, pic incoming shortly!

EverlastEngineering, 2023-11-16:
One more note: I found that the 3.3k plus the 330 ohm resistor combo is too low, 3.9 is too high so I’ve settled on the 3.3 plus a 510 which makes a cutoff right at 5.4V.

EverlastEngineering, 2023-11-16:
I just reread everything to get a clear picture. When you hit around 5.5 the red led should light and output V should go to 0.

Question that might be super silly: did you have it hooked up backwards. I’ve done it and that’s what the effect is. It doesn’t hurt anything but I was mega baffled for a bit lol.

jhiggason, 2023-11-16:
LOL- ok you all gave me a ton to go off of.  When I get home tonight let me see if I can figure out what i have.   I did install the newer recommended mosfet.  The IPD068P.

It's funny- I saw all those jumpers you had in the orginal pictures for the bodge- but honestly assumed you were using a different version of the board because it wasn't mentioned.  Probably should have just asked LOL.   I'm learning so much in the process though and that is exactly what this project was meant to do!  So thanks again for all the help here - you all are seriously rockstars.

Btw- I totally could have jacked up the bodge lol.  I did order the new set of 2.7 boards but it'll be a few weeks before they get here.

@EverlastEngineering  I don't think I had it backwards because when i had issues I kind of doublechecked everything but I'll hook it up today again and try to get some clearer photos for you all so we can be sure.

EverlastEngineering, 2023-11-19:
@jhiggason Which files did you use to order the 2.7? I _HOPE_ the gerber from the easyeda folder (as that's the one I ordered.) I did a cleanup tonight and was confused by a small unattached NET in the Kicad file.. it was a wire that was over the R3 connector in the schematic _but not connected_. I really had to fight to get it to "connect" and that of course meant there was a missing trace from R2 to R3.

The Kicad DRC _passed_ because those weren't connected in the schematic. Sheesh..

If you _did_ actually use the Kicad file and end up with boards with that defect, I can show you what to easily bodge, or you can use a single resistor without any bodge at all by running it across R2 and R3, skipping the mis-connected ones.

Sorry, mate, if that miss ended up costing you boards. :(

jhiggason, 2023-11-21:
I think I might have ordered the one in root of the folder.  So maybe the bad one?  It's not the end of the world..I had a coupon so it was like 3.50 shipped.  It's really no issue.

If I wanted to skip that resistor, I can just order a 3.83k ohm?

I haven't had a chance to look at my bodge board yet...I just got my SD2IEC setup and working and was able to play pacman for the first time last night.  Big win that has been a long time coming.  Now I just need to get this working and i'll be golden.

jhiggason, 2023-11-22:
Ok fellas- I spent a bunch of time yesterday really looking at the board and trying to figure out what I've done wrong.  I checked continuity at a ton of parts to see if maybe my solder joints were bad or to see if maybe my cuts weren't deep enough. Everything tested good.  The two cuts and all of the important parts all have continuity where they should, and no continuity where they shouldn't.    I tried to take some better photos of my board but they still are not great...I really need to get my macro photography setup going.

Here is what is happening.

Apply 5V to the board with a 5OHM resistor on the load.    As I increase voltage- from 5V it increases across the load until about 5.6v where the red light comes on but the voltage doesn't drop.  (green light works now btw after that jumper to ground)  Voltage will continue to increase on the output indefinitely.

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

What parts do you suppose I should be looking at?  I'm guessing mosfet and zener?  Both are different than what is in the bom but I thought would work based on part numbers and other specs.

Here is the zener kit I ended up with: https://www.amazon.com/dp/B07BTKVRG8?psc=1&ref=ppx_yo2ov_dt_b_product_details

I used the 6.8v 1watt zener.

Here is the mosfet I purchased: https://www.ebay.com/itm/132325095444

Really enjoying this project- thanks again fellas. =)
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
jhiggason, 2023-11-22:
Yes exactly!!  Measuring the voltage across the terminal screws vs on the breadboard with the resistor shows different voltages. When literally there is only a wire between them.  I'm thinking either a breadboard or a terminal problem..but just wanted to make sure I wasn't misunderstanding how voltage works haha.

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

Oooooo- I like your new design.  If you get to the point where you want other testers- let me know- I'd be happy to order and try it out for you.  Are you in the US?  I have a pack of those resistors- I can send you one through USPS.

jdecupere, 2023-11-22:
Ok. Clear picture. It is a bit higher than I would expect, but not impossible. The green wires and the breadboard traces will add some resistance...0.4 ohm it seems. Not impossible if the breadboard is not the highest quality....or there could be some contact resistance if the green wires are not pushed in the board all the way. In any case...this is not part of the problems you see ;-)
Thanks for the offer on the resistors, but I am in Belgium, so that would not be cost effective...I need to add it to my next order from my local supplier.

jhiggason, 2023-11-23:
Ok- voltage across the zener increases until about 5.4v and then drops to 32mv.

Output continues to increase as input is increased.

jdecupere, 2023-11-23:
Aha! I think I found it...we need @EverlastEngineering to check, since I think it is his bodge ;-)
Unless I miss something, the two PCB cuts he proposed disconnect R10 from "overvoltage" and the cathode of the zener  from VCC1. The jumper short (pin 2 to pin4) then connect R10 to GND instead -> this is OK.
To reconnect the zener, you move its cathode directly to VCC1 (as you did on the bottom of the PCB) - again fine.
Then, he says to connect the bodge wire from LED2's anode to 5V_safe, so it is powered from there, resulting in the green led being on when the voltage is safe (and in the process not pushing current into the "overvoltage" node. BUT, here is where either he missed an instruction or missed that this does not work: The anode of LED2 is still also connected to VCC1 through a trace that goes to LED1 and the de-coupling cap - i tried to indicate in green below what I mean.

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

So, @EverlastEngineering : can you check if there is another cut @jhiggason needed to make, or you missed this one?

Anyway: two options to move on  (choose one, not both):
1. remove the red bodge wire: this will remove the short and will keep the green LED on VCC1 - hence always ON (and not indicating safe 5V, but just that there is power on the input) - everything else will work
2. make another cut to remove the short and have the components where @EverlastEngineering intended them: cutting the trace between LED2 and LED1 that connects their pin2 (anodes) - see below

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

@EverlastEngineering can you confirm?

jhiggason, 2023-11-23:
This did it!  Removing the red bodge wire allows the circuit to open properly. Around 5.48V it cuts out and drops to 28mv.  It also fixed the voltage problem.  I'm now reading the same voltage at the load as the input voltage. =)

jhiggason, 2023-11-24:
Hey fellas- I was able to model and quickly print a case for it last night.  =) Does version 2.7 have the same form factor?  If yes- I can share my little project box.  Not the tightest but works great.  Thanks again for all the help.

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

jhiggason, 2023-11-24:
I uploaded the STL for the case here: https://www.thingiverse.com/thing:6332407  You can either link to my thingiverse project or feel free to download the STL and place it somewhere here as well.  Glad to contribute to a great project =)

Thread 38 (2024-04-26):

330K Resistor

brendan1495, 2024-04-26:
Hi, not really an issue but I am in the UK and really strugging to get hold of a 04W 330K resistor, I can get hold of 300K 0.4W will this be Ok. Sorry for the noob question.

Brendan

jhiggason, 2024-04-26:
Can you find higher wattage?  I'd have to look at the schemetic again to see what the 330k are doing...but the easiest would be looking for higher wattage resistors.

I'm sure the other guys here can give you better information ❤️

brendan1495, 2024-04-27:
Hi jhiggason, thanks for the quick reply,  I could get higher but how high can I go?

jdecupere, 2024-04-27:
Hi Brendan,
That resistor is not critical. It just provides some hysteresis to the switching point to avoid an unstable state when just triggering the safe mode. Whether that is 330k or 300k Ohm does not matter much. Just take something close that has the same size - wattage is also not important...if you think about it - even if you had the full VCC over it, it will still just be  in the order of 0.1mW range.
Joost

brendan1495, 2024-04-27:
> Hi Brendan, That resistor is not critical. It just provides some hysteresis to the switching point to avoid an unstable state when just triggering the safe mode. Whether that is 330k or 300k Ohm does not matter much. Just take something close that has the same size physically - wattage is also not important...if you think about it - even if you had the full VCC over it, it will still just be in the order of 0.1mW range. Joost

Thanks a lot, managed to get some 300k in 0.4W. 0.4W resisters seem to be really hard to get in the UK in small numbers. Obviously I could use digikey or mouser but postage is very expensive unless buying lots. Thanks for the reply, I can get to building them now.

Brendan

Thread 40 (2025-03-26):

LED positive and Negative Symbols Reversed on Through Hole  V2 6

BeskarMiner, 2025-03-26:
Board version 2.6 (through hole) has the square (+) and circle (-)  holes reversed for both LED1 and LED2. This appears to be the case both sides of the board. Had me stumped! Great project BWACK!  I'm only a novice, apologies if I've got it wrong.

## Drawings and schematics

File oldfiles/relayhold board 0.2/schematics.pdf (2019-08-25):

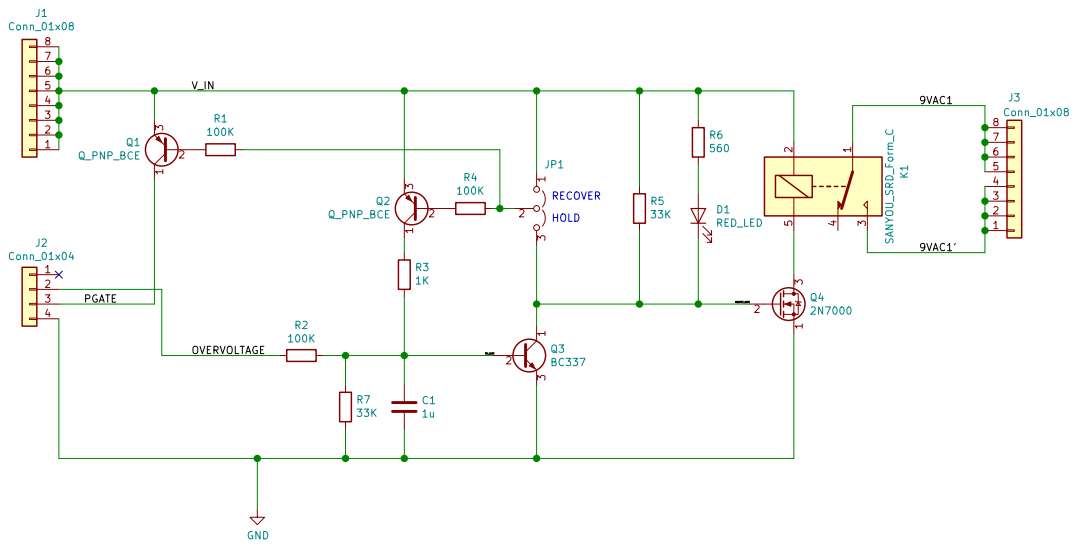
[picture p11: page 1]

adds 9VAC shutdown on powerfault and fault-hold mechanism
File: relayhold board.sch Sheet: / an addon board for the C64 Saver 2

Id: 1/1 Title: relay hold

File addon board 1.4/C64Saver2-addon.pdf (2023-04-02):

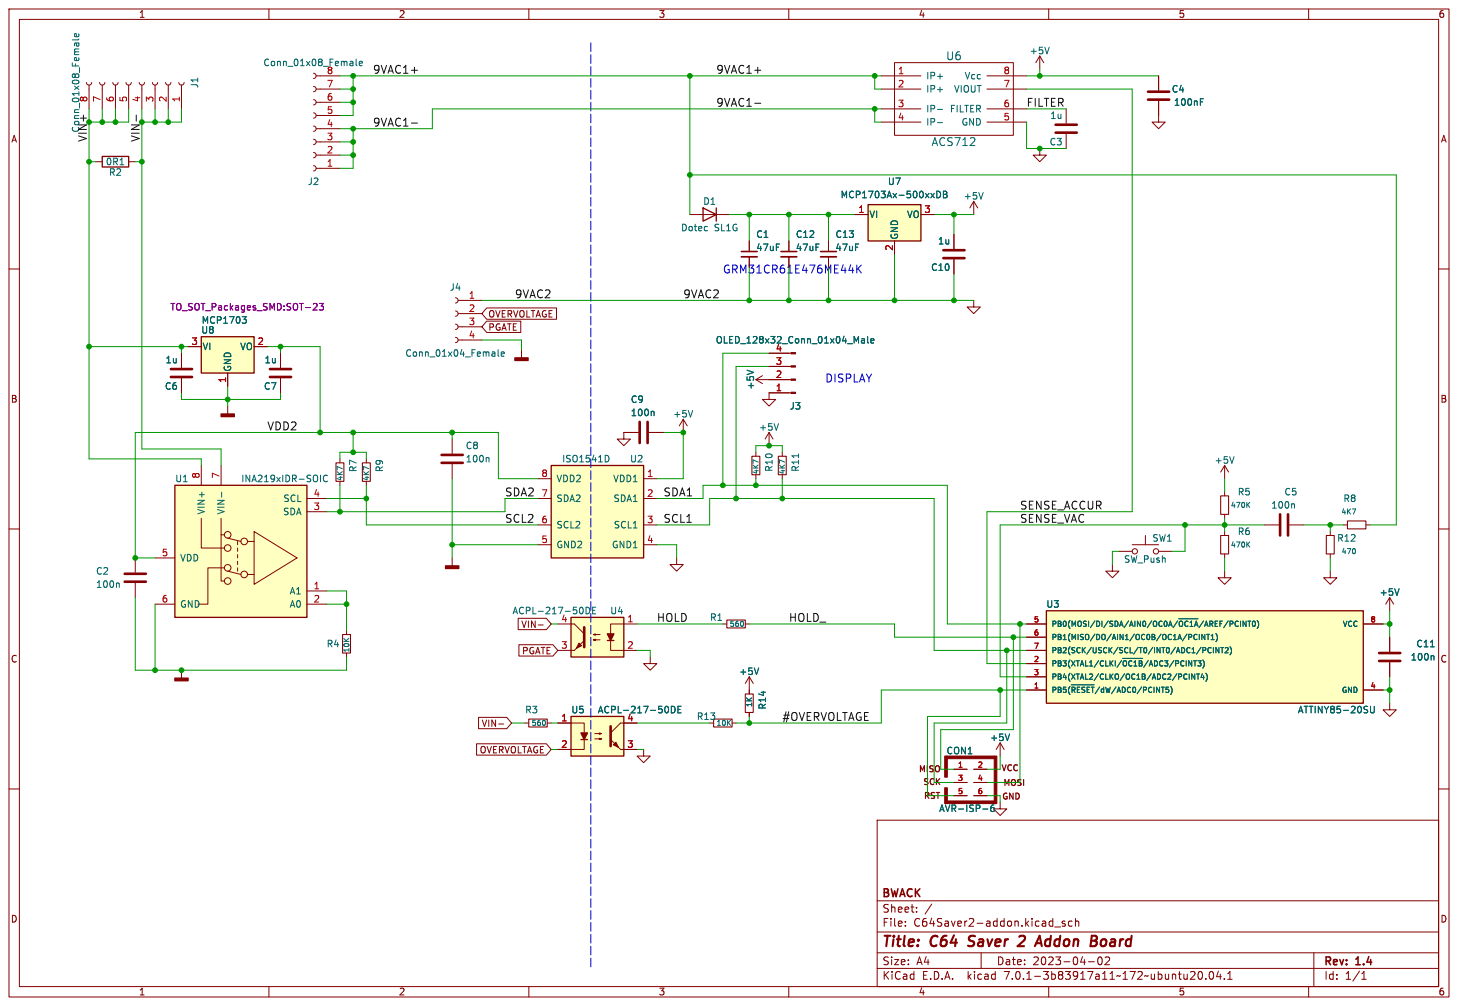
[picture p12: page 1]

File: C64Saver2-addon.kicad_sch Sheet: / BWACK

Id: 1/1 Title: C64 Saver 2 Addon Board

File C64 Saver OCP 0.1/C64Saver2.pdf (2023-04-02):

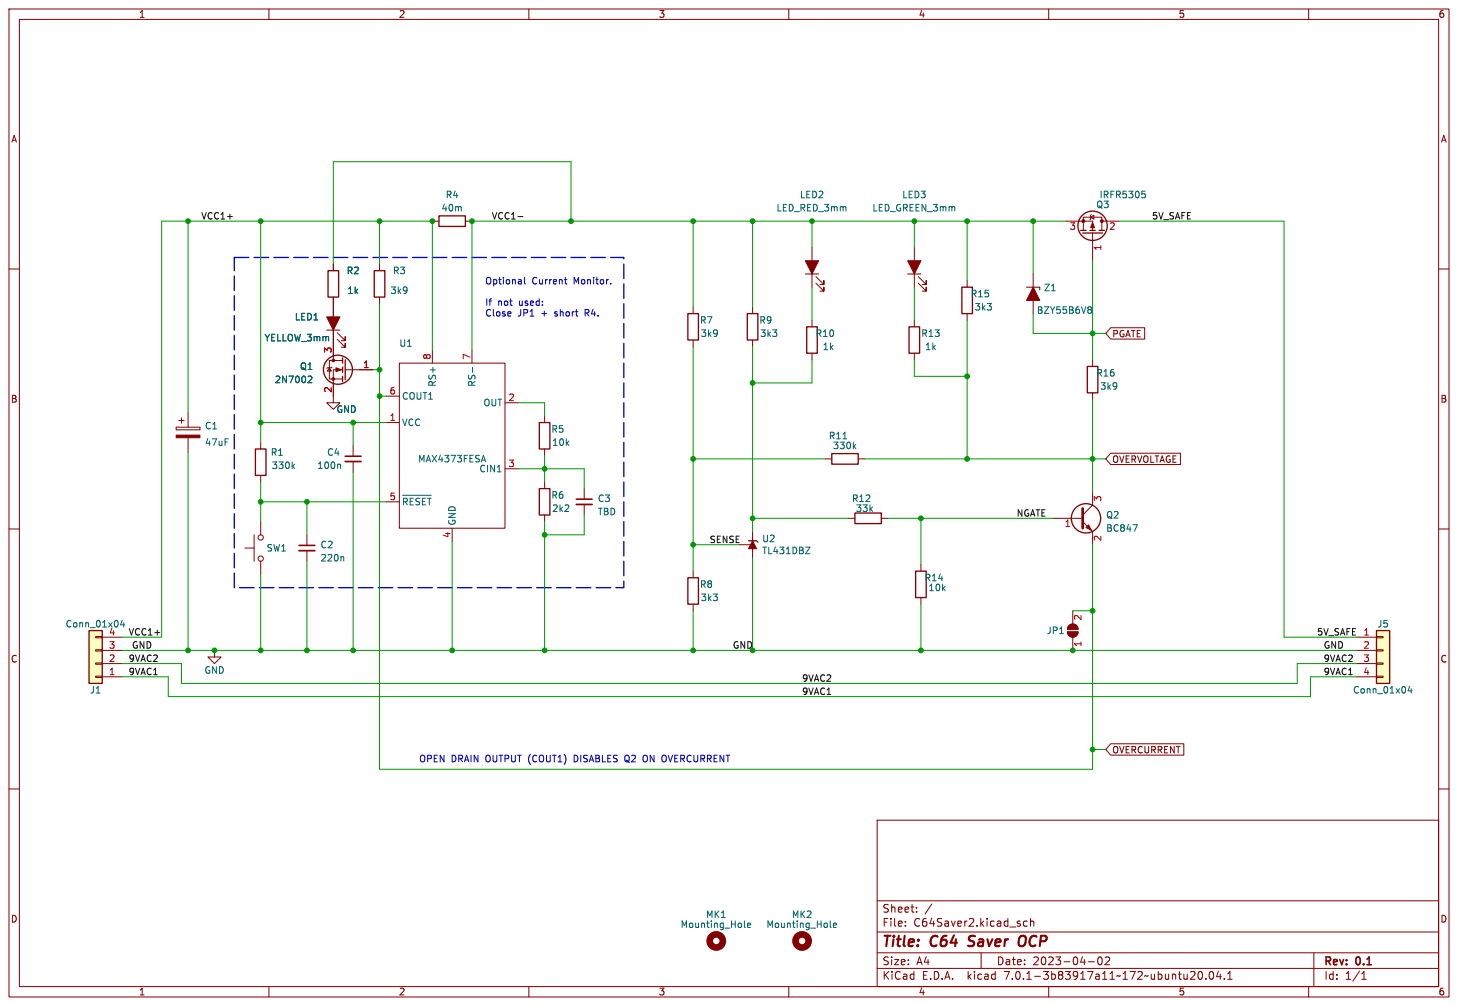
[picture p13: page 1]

VCC1- OPEN DRAIN OUTPUT (COUT1) DISABLES Q2 ON OVERCURRENT Optional Current Monitor.

If not used: Close JP1 + short R4. Q1

File: C64Saver2.kicad_sch Sheet: /
Id: 1/1 Title: C64 Saver OCP

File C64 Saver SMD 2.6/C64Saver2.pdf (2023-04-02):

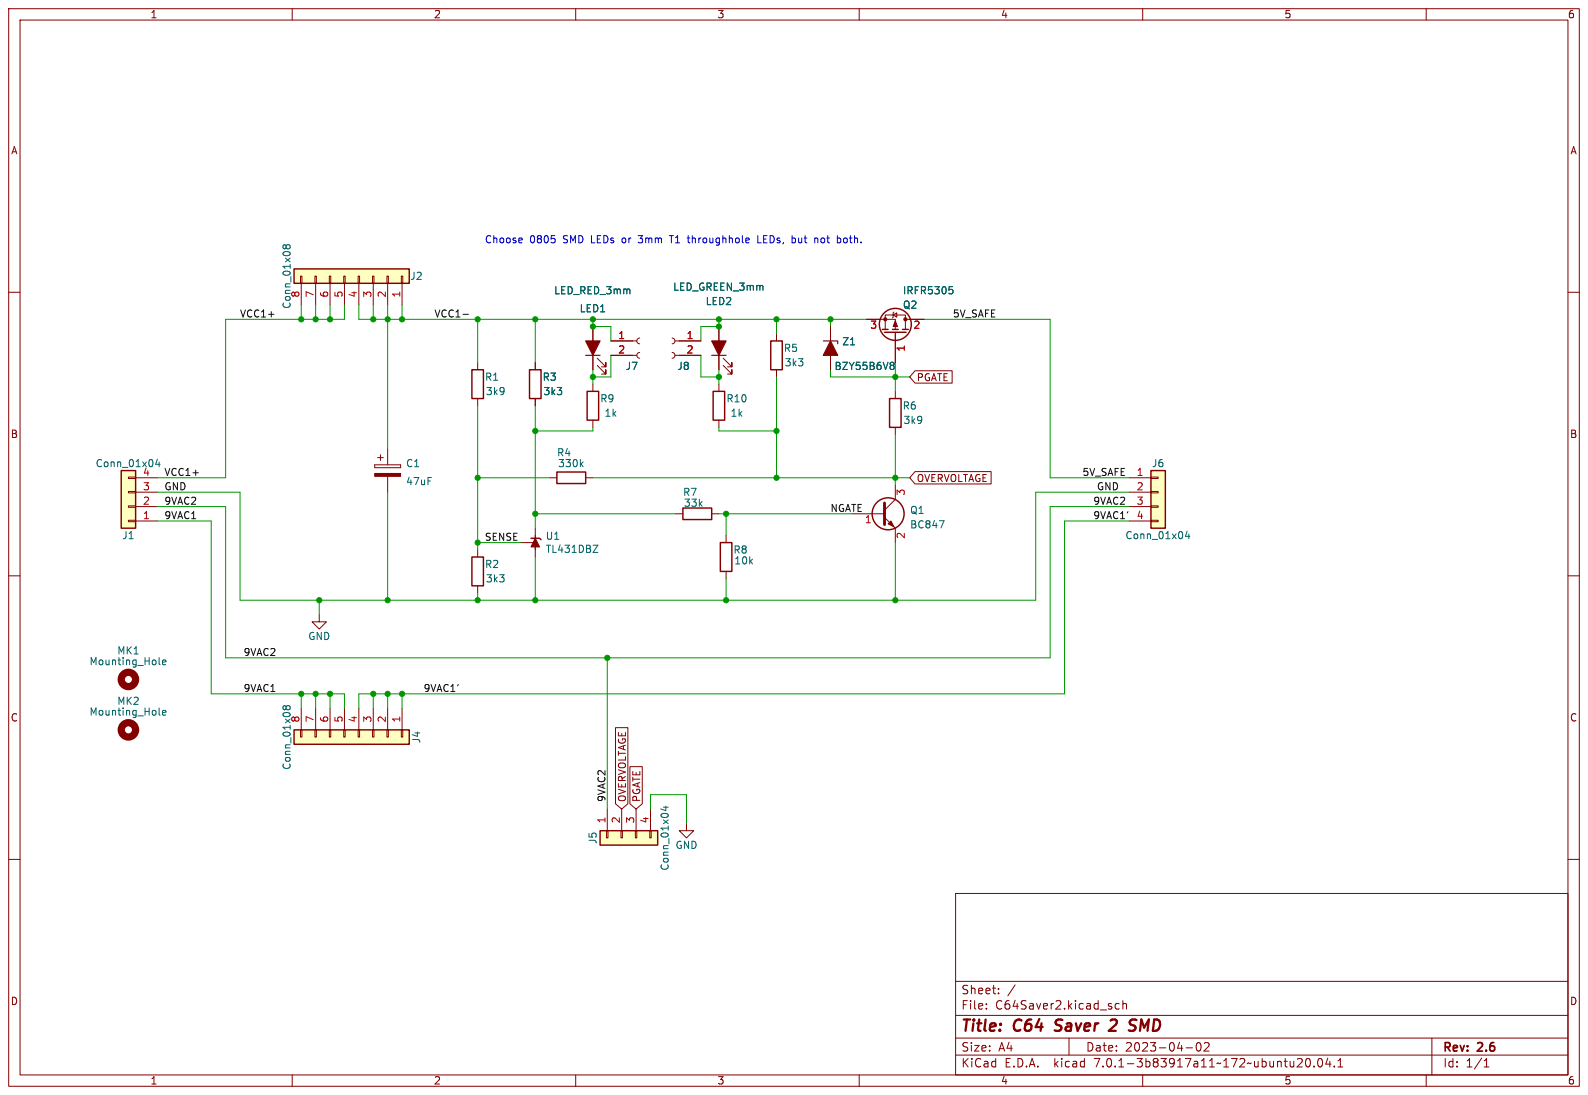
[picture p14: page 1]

File: C64Saver2.kicad_sch Sheet: /
Id: 1/1 Title: C64 Saver 2 SMD

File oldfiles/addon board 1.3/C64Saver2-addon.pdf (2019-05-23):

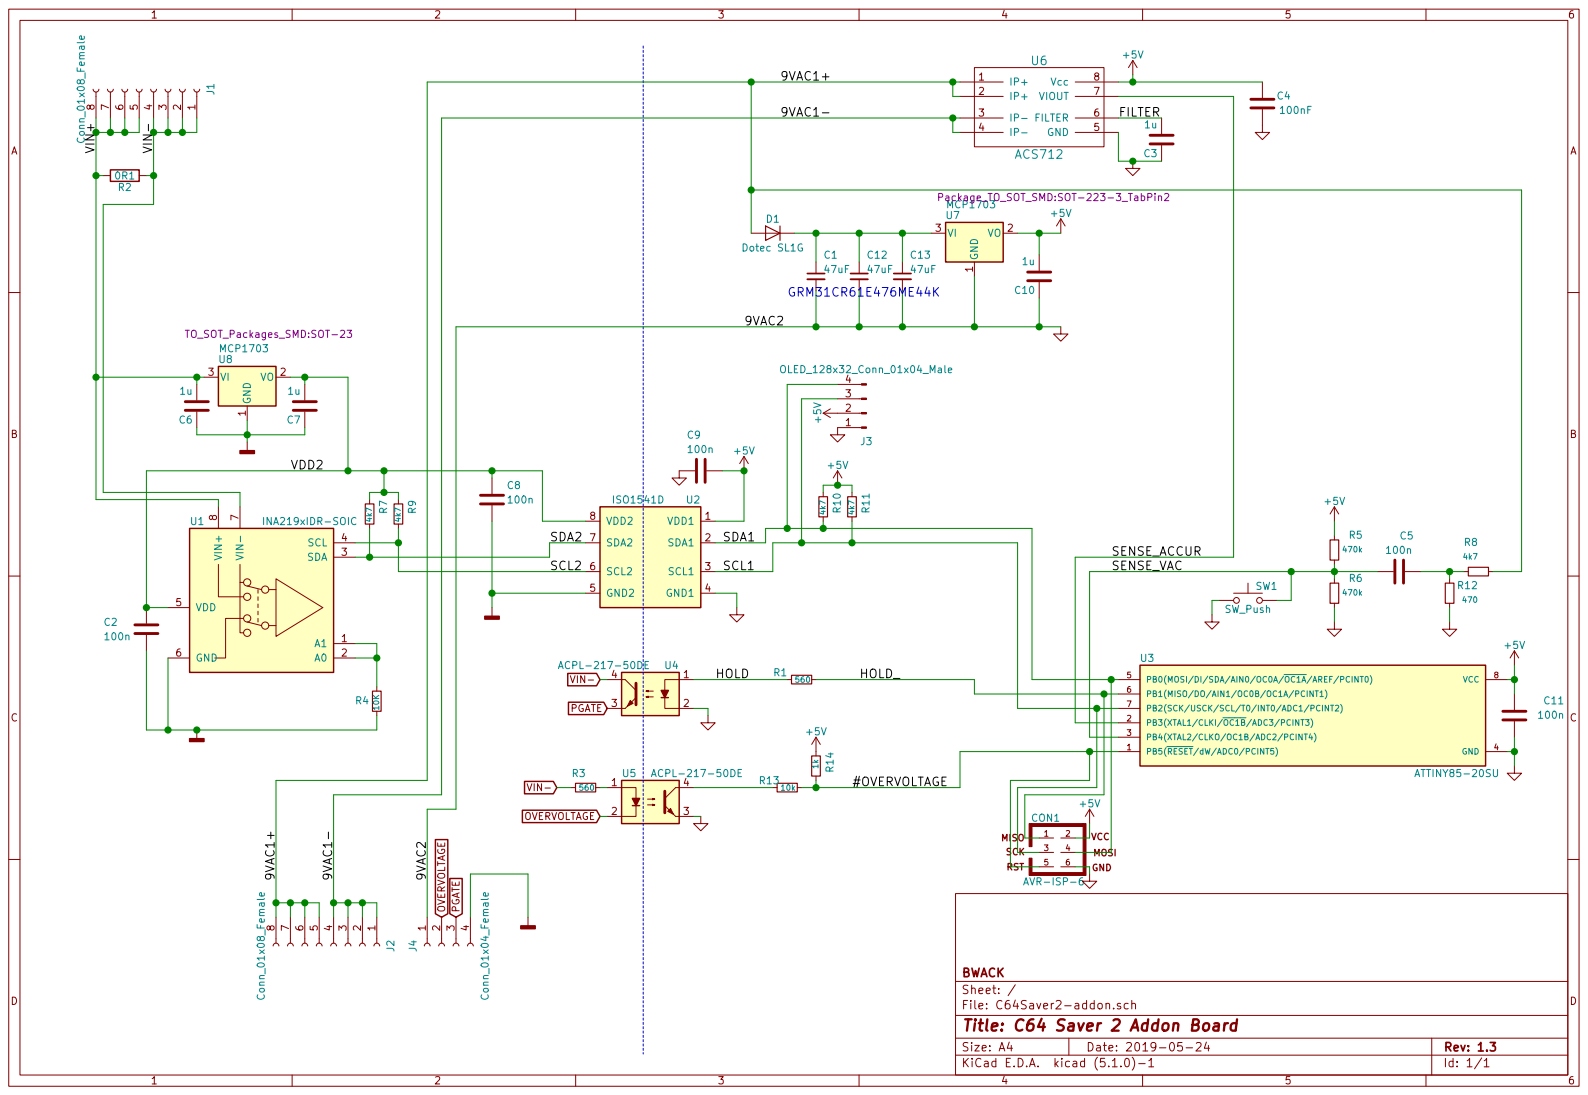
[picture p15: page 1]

Id: 1/1 Title: C64 Saver 2 Addon Board

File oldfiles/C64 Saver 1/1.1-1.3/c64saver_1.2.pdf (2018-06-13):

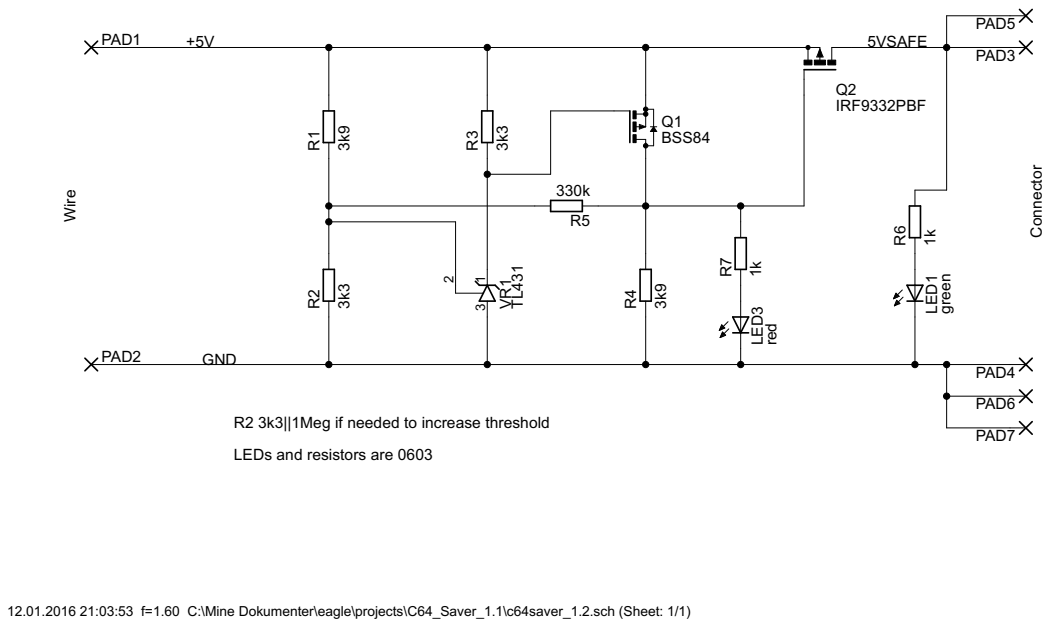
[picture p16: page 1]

R2 3k3||1Meg if needed to increase threshold

LEDs and resistors are 0603

12.01.2016 21:03:53 f=1.60 C:\Mine Dokumenter\eagle\projects\C64_Saver_1.1\c64saver_1.2.sch (Sheet: 1/1)

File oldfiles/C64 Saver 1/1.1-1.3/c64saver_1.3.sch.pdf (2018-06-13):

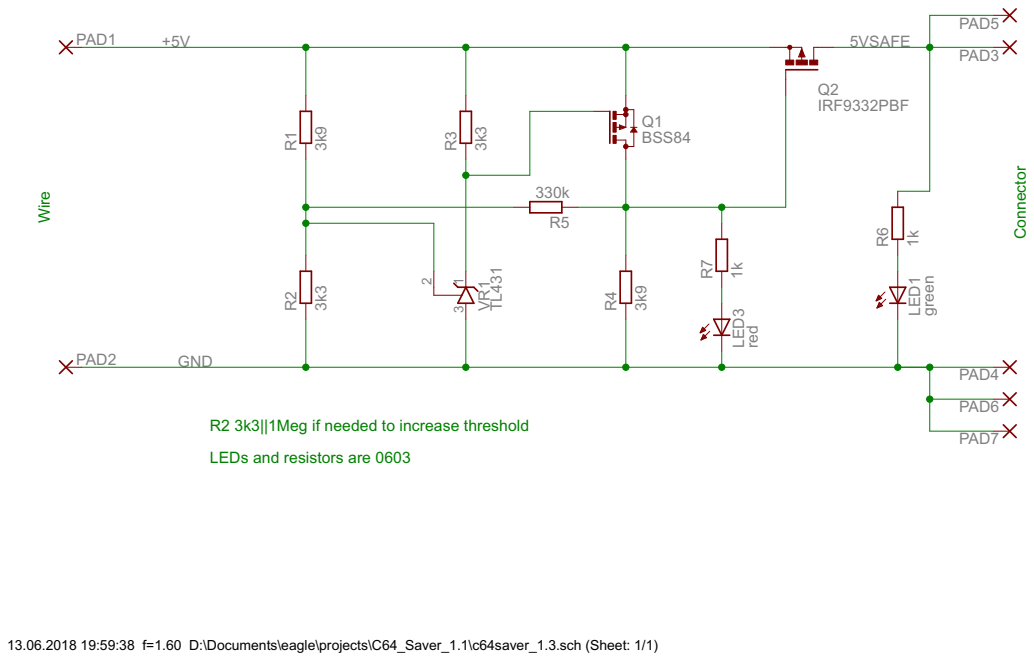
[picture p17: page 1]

R2 3k3||1Meg if needed to increase threshold

LEDs and resistors are 0603

13.06.2018 19:59:38 f=1.60 D:\Documents\eagle\projects\C64_Saver_1.1\c64saver_1.3.sch (Sheet: 1/1)

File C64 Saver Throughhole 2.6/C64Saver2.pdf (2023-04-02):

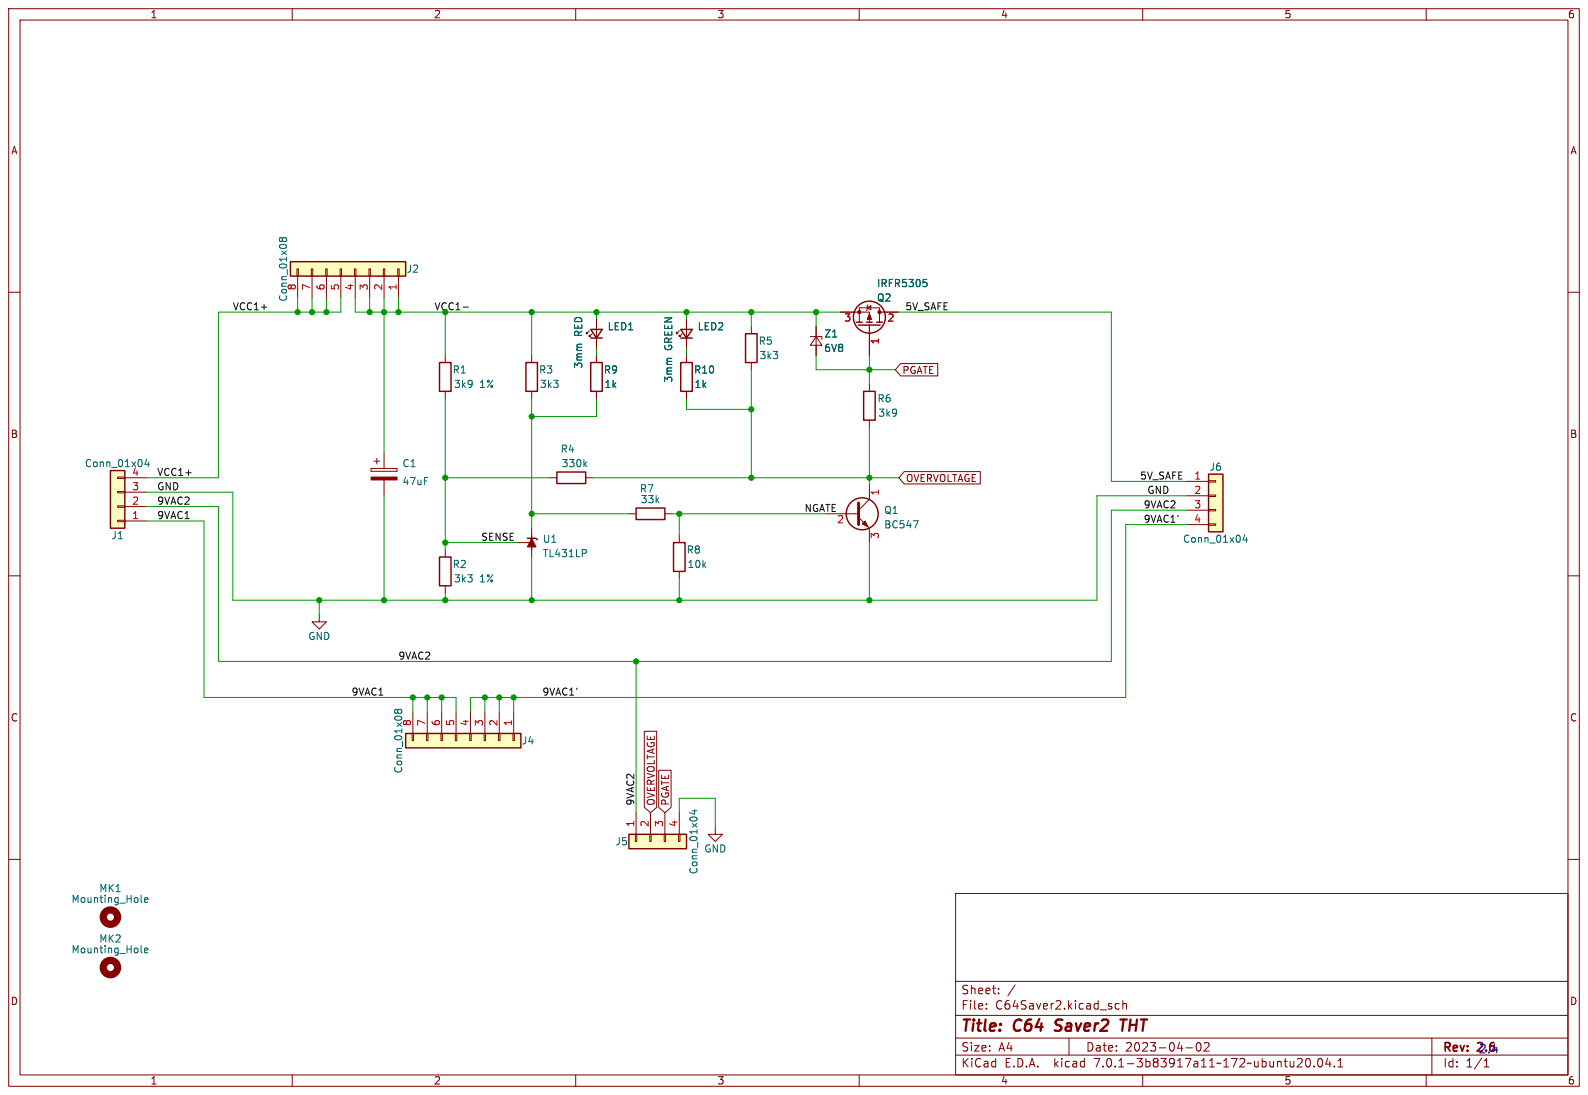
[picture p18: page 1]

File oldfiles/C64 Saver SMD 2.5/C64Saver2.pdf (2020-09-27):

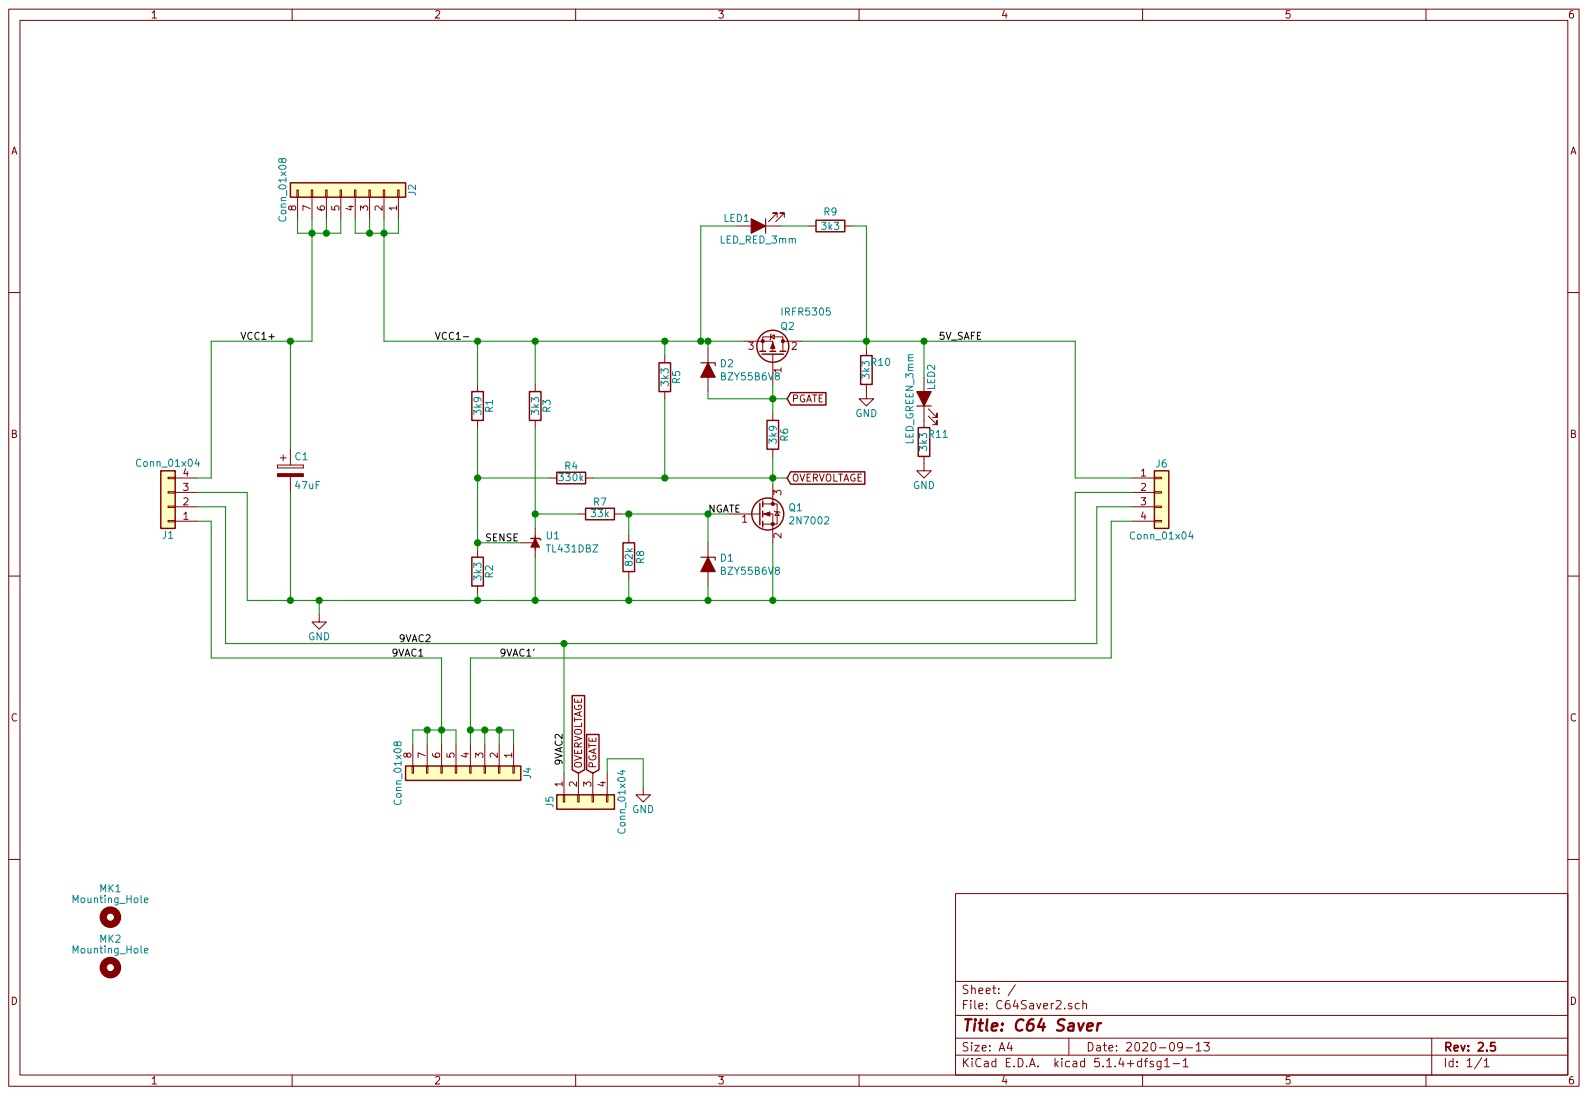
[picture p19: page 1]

Id: 1/1 Title: C64 Saver File: C64Saver2.sch Sheet: /

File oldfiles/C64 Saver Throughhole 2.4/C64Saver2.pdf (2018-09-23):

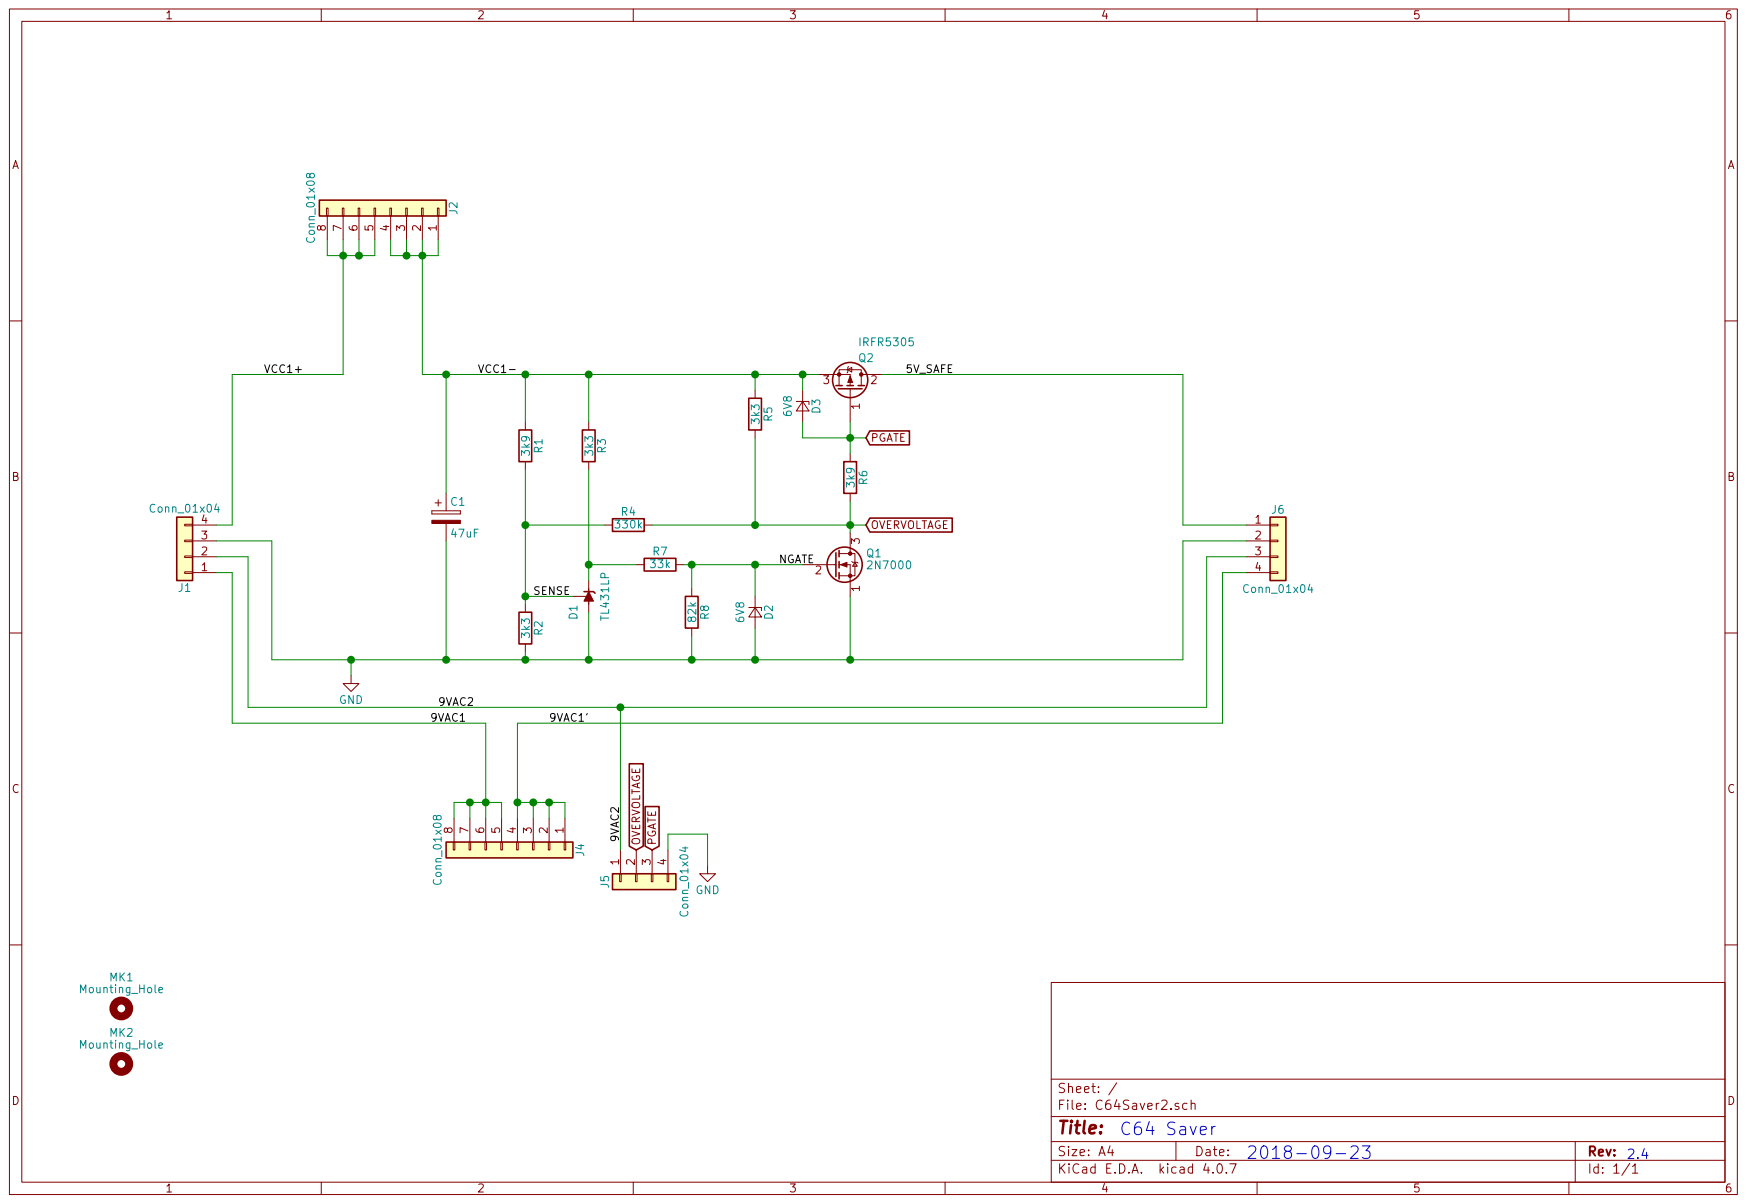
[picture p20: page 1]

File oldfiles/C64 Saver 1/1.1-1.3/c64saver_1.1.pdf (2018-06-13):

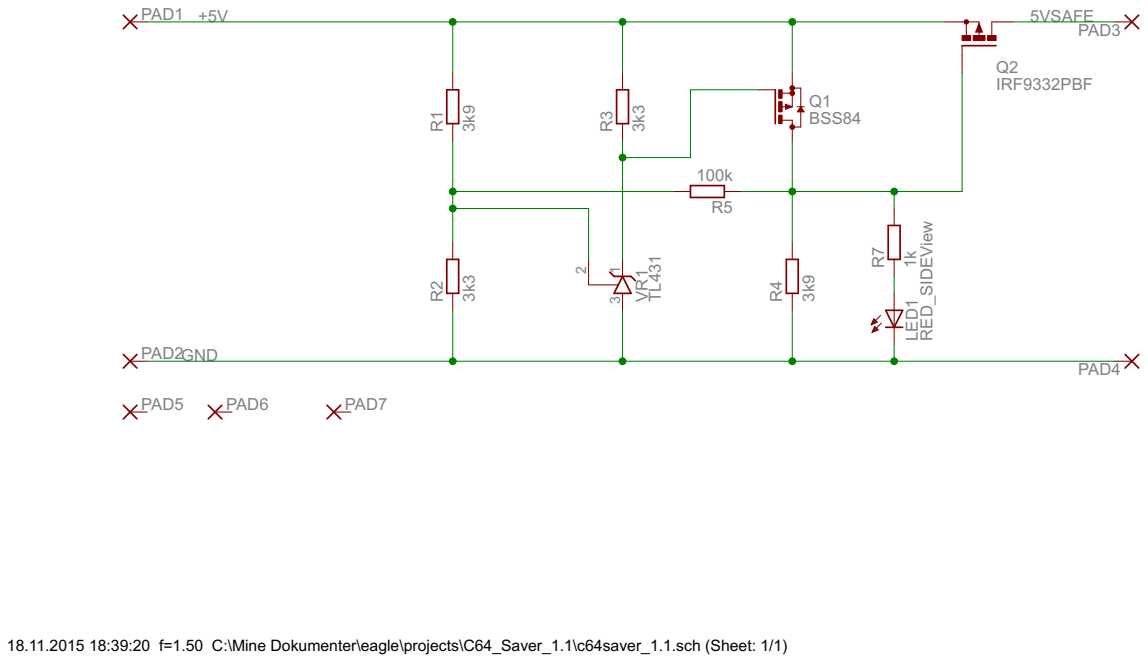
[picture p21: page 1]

18.11.2015 18:39:20 f=1.50 C:\Mine Dokumenter\eagle\projects\C64_Saver_1.1\c64saver_1.1.sch (Sheet: 1/1)

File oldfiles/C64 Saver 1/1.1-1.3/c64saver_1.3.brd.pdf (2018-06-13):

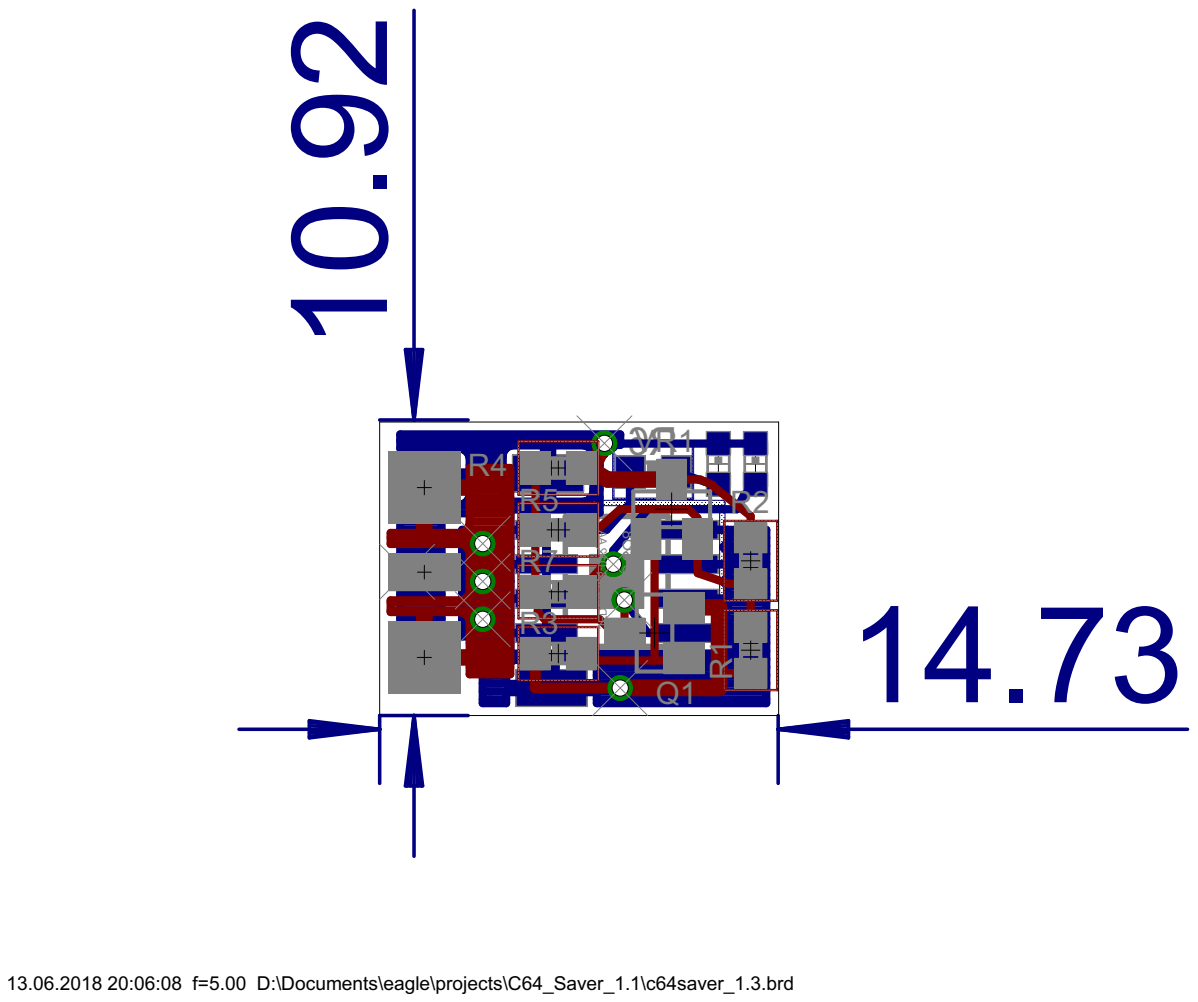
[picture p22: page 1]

13.06.2018 20:06:08 f=5.00 D:\Documents\eagle\projects\C64_Saver_1.1\c64saver_1.3.brd

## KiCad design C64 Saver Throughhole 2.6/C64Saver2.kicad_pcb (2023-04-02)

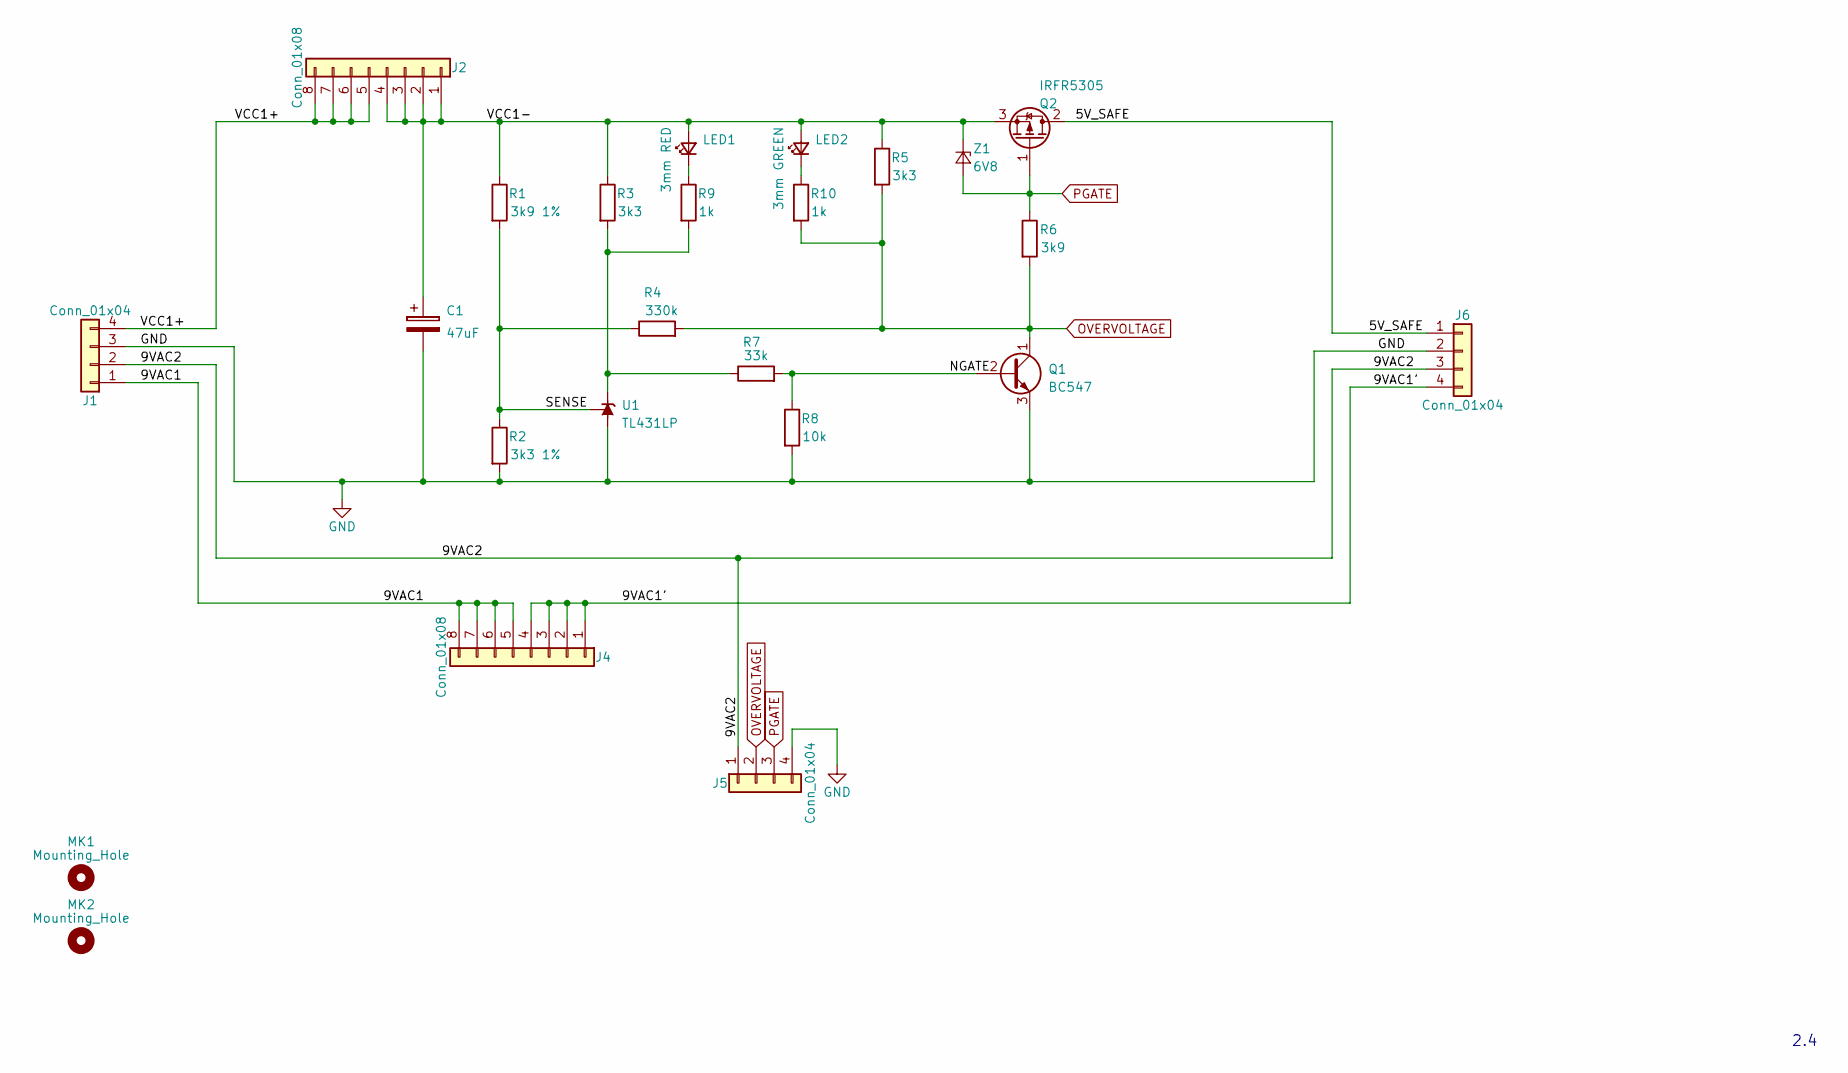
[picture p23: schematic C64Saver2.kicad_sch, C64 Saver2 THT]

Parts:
C1: 47uF; CP_Radial_D6.3mm_P2.50mm
J1, J6: Conn_01x04; TerminalBlock_bornier-4_P5.08mm; Mouser not used
J2, J4: Conn_01x08; Pin_Header_Straight_1x08_Pitch2.54mm
J5: Conn_01x04; Pin_Header_Straight_1x04_Pitch2.54mm
LED1: 3mm RED; LED_D3.0mm; Mouser WP710A10LSECK/J3
LED2: 3mm GREEN; LED_D3.0mm; Mouser WP710A10LZGCK
MK1, MK2: Mounting_Hole; MountingHole_2.5mm
Q1: BC547; TO-92_Inline
Q2: IRFR5305; ATPAK-2
R1: 3k9 1%; R_Axial_DIN0204_L3.6mm_D1.6mm_P5.08mm_Horizontal
R2: 3k3 1%; R_Axial_DIN0204_L3.6mm_D1.6mm_P5.08mm_Horizontal; Mouser RN55D3301FB14
R3, R5: 3k3; R_Axial_DIN0204_L3.6mm_D1.6mm_P5.08mm_Horizontal; Mouser RN55D3301FB14
R4: 330k; R_Axial_DIN0204_L3.6mm_D1.6mm_P5.08mm_Horizontal
R6: 3k9; R_Axial_DIN0204_L3.6mm_D1.6mm_P5.08mm_Horizontal
R7: 33k; R_Axial_DIN0207_L6.3mm_D2.5mm_P7.62mm_Horizontal
R8: 10k; R_Axial_DIN0204_L3.6mm_D1.6mm_P5.08mm_Horizontal
R9, R10: 1k; R_Axial_DIN0204_L3.6mm_D1.6mm_P5.08mm_Horizontal
U1: TL431LP; TO-92_Inline
Z1: 6V8; D_DO-35_SOD27_P7.62mm_Horizontal

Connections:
/5V_SAFE: J6.1, Q2.2 (D)
/9VAC1: J1.1, J4.5, J4.6, J4.7, J4.8
/9VAC1': J4.1, J4.2, J4.3, J4.4, J6.4
/9VAC2: J1.2, J5.1, J6.3
/NGATE: Q1.2 (B), R7.2, R8.1
/SENSE: R1.2, R2.1, R4.1, U1.1 (REF)
/VCC1+: J1.4, J2.5, J2.6, J2.7, J2.8
/VCC1-: C1.1, J2.1, J2.2, J2.3, J2.4, LED1.2 (A), LED2.2 (A), Q2.3 (S), R1.1, R3.1, R5.1, Z1.1 (K)
GND: C1.2, J1.3, J5.4, J6.2, Q1.3 (E), R2.2, R8.2, U1.2 (A)
unnamed: LED1.1 (K), R9.1
unnamed: LED2.1 (K), R10.1
unnamed: R3.2, R7.1, R9.2, U1.3 (K)
OVERVOLTAGE: J5.2, Q1.1 (C), R4.2, R5.2, R6.2, R10.2
PGATE: J5.3, Q2.1 (G), R6.1, Z1.2 (A)

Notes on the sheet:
2.4

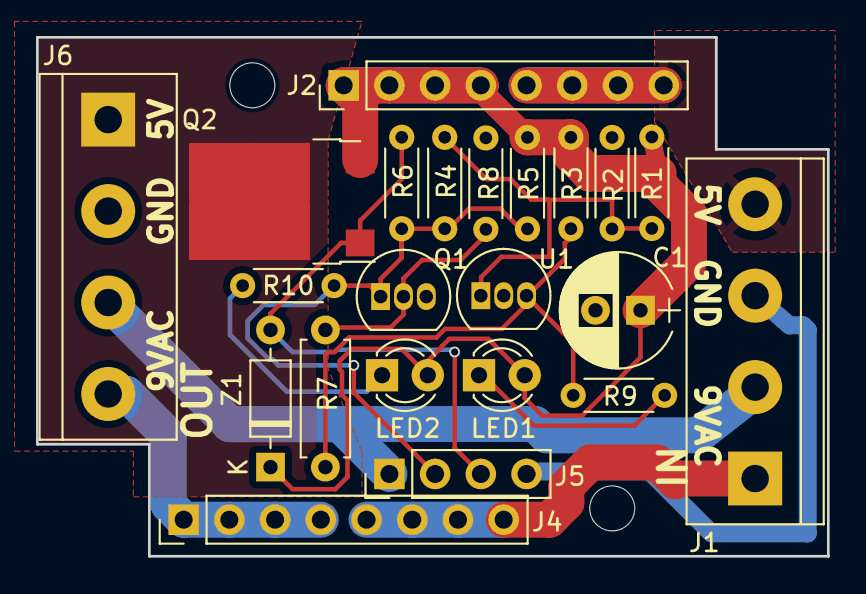
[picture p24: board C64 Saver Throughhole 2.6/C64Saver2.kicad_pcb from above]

Board: 2 copper layers, 43.9 x 28.8 mm, 24 parts (0 on the bottom side), 14 nets.

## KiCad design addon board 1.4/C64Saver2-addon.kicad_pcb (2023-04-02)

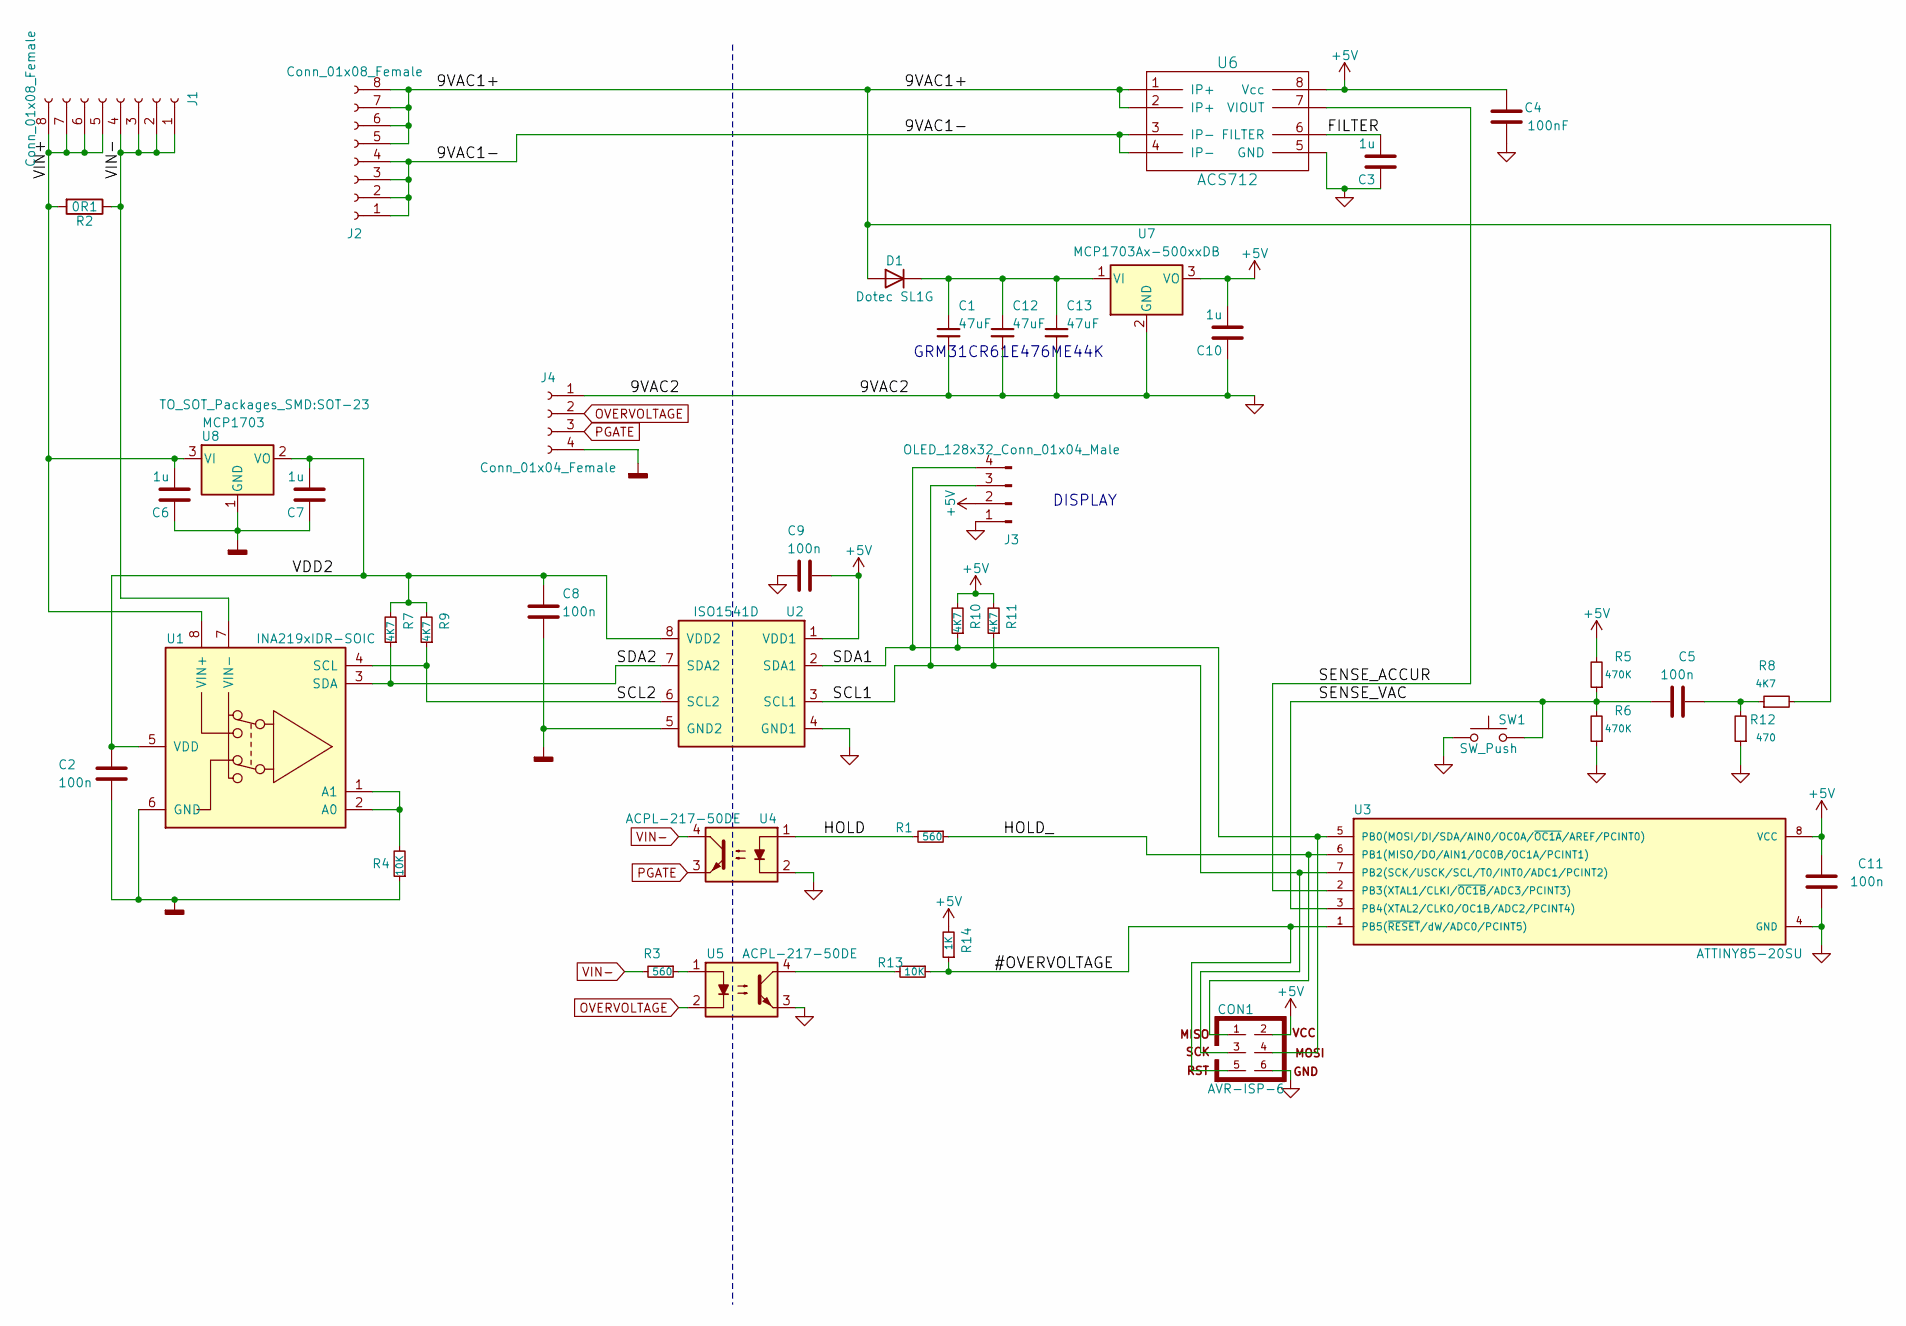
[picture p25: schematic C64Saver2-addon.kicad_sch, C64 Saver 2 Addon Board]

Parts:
C1, C12, C13: 47uF; C_1206_3216Metric
C2, C5, C8, C9, C11: 100n; C_0603_HandSoldering
C3, C6, C7, C10: 1u; C_0603_HandSoldering
C4: 100nF; C_0603_HandSoldering
CON1: AVR-ISP-6; Pin_Header_Straight_2x03_Pitch2.00mm
D1: Dotec SL1G; D_SOD-123
J1, J2: Conn_01x08_Female; Pin_Header_Straight_1x08_Pitch2.54mm
J3: OLED_128x32_Conn_01x04_Male; Pin_Header_Straight_1x04_Pitch2.54mm
J4: Conn_01x04_Female; Pin_Header_Straight_1x04_Pitch2.54mm
R1, R3: 560; R_0603_HandSoldering
R2: 0R1; R_2512_HandSoldering
R4, R13: 10K; R_0603_HandSoldering
R5: 470K; R_0603_HandSoldering
R6: 470K; R_0603_1608Metric_Pad1.05x0.95mm_HandSolder
R7, R8, R9, R10, R11: 4K7; R_0603_HandSoldering
R12: 470; R_0603_HandSoldering
R14: 1K; R_0603_HandSoldering
SW1: SW_Push; SW_PUSH_6mm_h13mm
U1: INA219xIDR-SOIC; SOIC-8_3.9x4.9mm_P1.27mm
U2: ISO1541D; SOIC-8_3.9x4.9mm_P1.27mm
U3: ATTINY85-20SU; SOIJ-8_5.3x5.3mm_P1.27mm
U4, U5: ACPL-217-50DE; SOIC-4_4.55x2.6mm_P1.27mm
U6: ACS712; SOIC-8_3.9x4.9mm_P1.27mm
U7: MCP1703Ax-500xxDB; SOT-223-3_TabPin2
U8: MCP1703; SOT-23

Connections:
+5V: C4.2, C9.1, C10.2, C11.2, CON1.2, J3.2, R5.2, R10.2, R11.2, R14.2, U2.1 (VDD1), U3.8 (VCC), U6.8 (Vcc), U7.3 (VO)
/9VAC1+: D1.2 (A), J2.5, J2.6, J2.7, J2.8, R8.2, U6.1 (IP+), U6.2 (IP+)
/9VAC1-: J2.1, J2.2, J2.3, J2.4, U6.3 (IP-), U6.4 (IP-)
/#OVERVOLTAGE: CON1.5, R13.1, R14.1, U3.1 (PB5(~RESET/dW/ADC0/PCINT5))
/FILTER: C3.2, U6.6 (FILTER)
/HOLD: R1.2, U4.1
/HOLD_: CON1.1, R1.1, U3.6 (PB1(MISO/DO/AIN1/OC0B/OC1A/PCINT1))
/SCL1: CON1.3, J3.3, R11.1, U2.3 (SCL1), U3.7 (PB2(SCK/USCK/SCL/T0/INT0/ADC1/PCINT2))
/SCL2: R9.1, U1.4 (SCL), U2.6 (SCL2)
/SDA1: CON1.4, J3.4, R10.1, U2.2 (SDA1), U3.5 (PB0(MOSI/DI/SDA/AIN0/OC0A/~OC1A/AREF/PC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)
/SDA2: R7.1, U1.3 (SDA), U2.7 (SDA2)
/SENSE_ACCUR: U3.2 (PB3(XTAL1/CLKI/~OC1B/ADC3/PCINT3)), U6.7 (VIOUT)
/SENSE_VAC: C5.2, R5.1, R6.2, SW1.2, U3.3 (PB4(XTAL2/CLKO/OC1B/ADC2/PCINT4))
/VDD2: C2.1, C7.2, C8.1, R7.2, R9.2, U1.5 (VDD), U2.8 (VDD2), U8.2 (VO)
/VIN+: C6.2, J1.5, J1.6, J1.7, J1.8, R2.2, U1.8 (VIN+), U8.3 (VI)
GND: C1.2, C3.1, C4.1, C9.2, C10.1, C11.1, C12.2, C13.2, CON1.6, J3.1, J4.1, R6.1, R12.1, SW1.1, U2.4 (GND1), U3.4 (GND), U4.2, U5.3, U6.5 (GND), U7.2 (GND)
GNDD: C2.2, C6.1, C7.1, C8.2, J4.4, R4.1, U1.6 (GND), U2.5 (GND2), U8.1 (GND)
unnamed: C5.1, R8.1, R12.2
unnamed: C1.1, C12.1, C13.1, D1.1 (K), U7.1 (VI)
unnamed: R3.1, U5.1
unnamed: R13.2, U5.4
unnamed: R4.2, U1.1 (A1), U1.2 (A0)
OVERVOLTAGE: J4.2, U5.2
PGATE: J4.3, U4.3
VIN-: J1.1, J1.2, J1.3, J1.4, R2.1, R3.2, U1.7 (VIN-), U4.4

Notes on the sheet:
DISPLAY
GRM31CR61E476ME44K

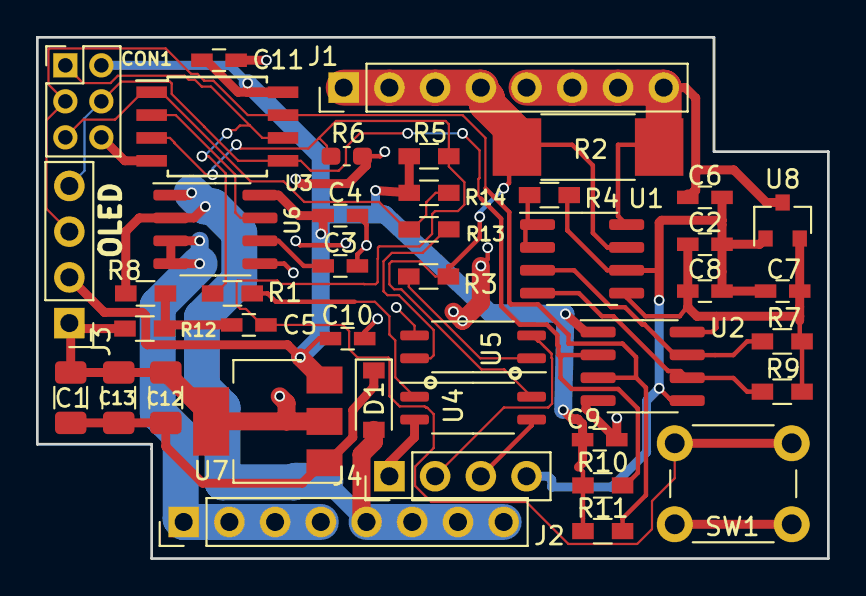
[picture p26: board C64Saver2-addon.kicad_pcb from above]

Board: 2 copper layers, 43.9 x 29.0 mm, 42 parts (0 on the bottom side), 25 nets.

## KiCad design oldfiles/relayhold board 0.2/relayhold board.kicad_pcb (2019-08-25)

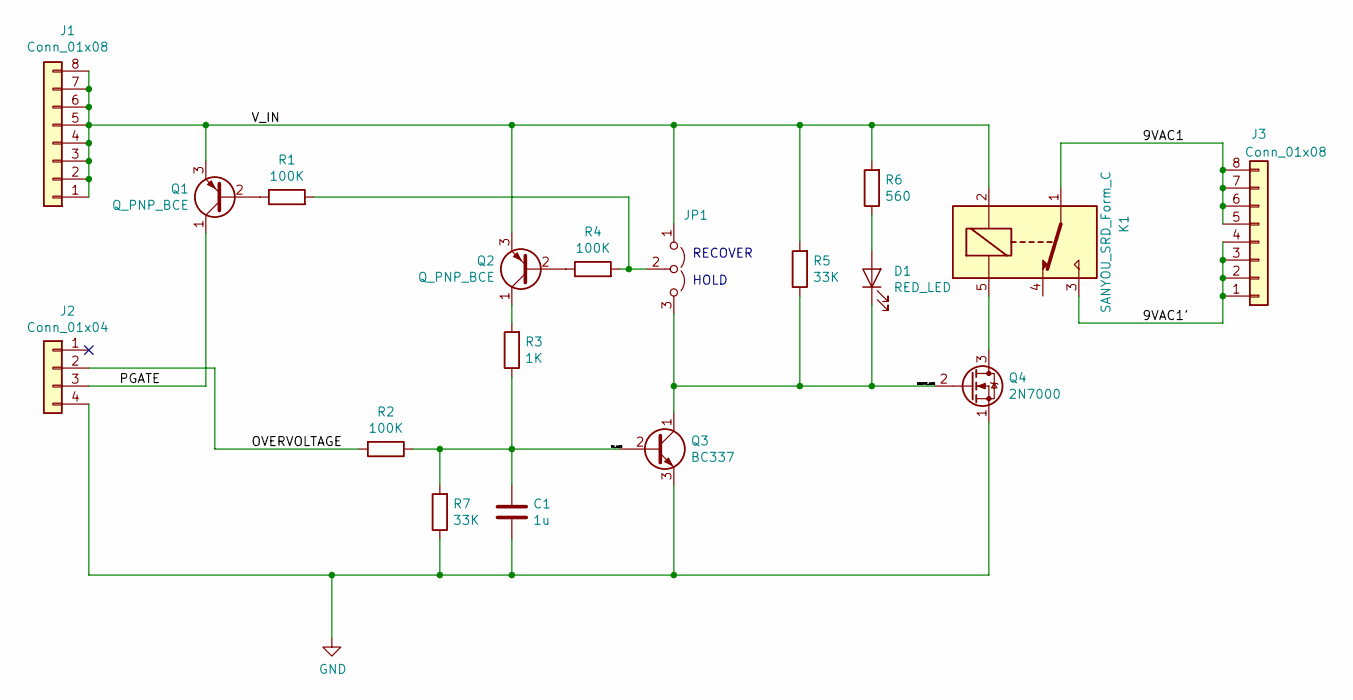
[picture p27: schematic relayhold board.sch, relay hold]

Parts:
C1: 1u; C_Rect_L7.0mm_W2.5mm_P5.00mm
D1: RED_LED; LED_D5.0mm
J1, J3: Conn_01x08; PinHeader_1x08_P2.54mm_Vertical
J2: Conn_01x04; PinHeader_1x04_P2.54mm_Vertical
JP1: Jumper_3_Open; PinHeader_1x03_P2.54mm_Vertical
K1: SANYOU_SRD_Form_C; Relay_SPDT_SANYOU_SRD_Series_Form_C
Q1, Q2: Q_PNP_BCE; TO-92_Inline_Wide
Q3: BC337; TO-92_Inline_Wide
Q4: 2N7000; TO-92_Inline_Wide
R1, R2, R4: 100K; R_Axial_DIN0207_L6.3mm_D2.5mm_P2.54mm_Vertical
R3: 1K; R_Axial_DIN0207_L6.3mm_D2.5mm_P2.54mm_Vertical
R5, R7: 33K; R_Axial_DIN0207_L6.3mm_D2.5mm_P2.54mm_Vertical
R6: 560; R_Axial_DIN0207_L6.3mm_D2.5mm_P2.54mm_Vertical

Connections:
/9VAC1: J3.5, J3.6, J3.7, J3.8, K1.1
/9VAC1': J3.1, J3.2, J3.3, J3.4, K1.3
/MOSFET_GATE: D1.1 (K), JP1.3 (B), Q3.1 (C), Q4.2 (G), R5.1
/OVERVOLTAGE: J2.2, R2.2
/OV_GATE: C1.1, Q3.2 (B), R2.1, R3.1, R7.2
/PGATE: J2.3, Q1.1 (C)
/V_IN: J1.1, J1.2, J1.3, J1.4, J1.5, J1.6, J1.7, J1.8, JP1.1 (A), K1.2, Q1.3 (E), Q2.3 (E), R5.2, R6.2
GND: C1.2, J2.4, Q3.3 (E), Q4.1 (S), R7.1
unnamed: D1.2 (A), R6.1
unnamed: JP1.2 (C), R1.2, R4.2
unnamed: K1.5, Q4.3 (D)
unnamed: Q1.2 (B), R1.1
unnamed: Q2.1 (C), R3.2
unnamed: Q2.2 (B), R4.1

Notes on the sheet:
HOLD
RECOVER

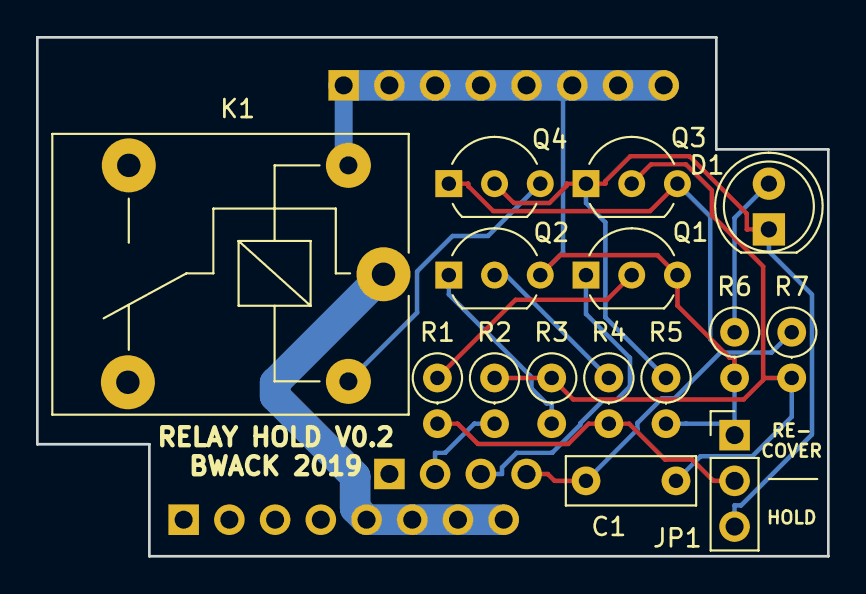
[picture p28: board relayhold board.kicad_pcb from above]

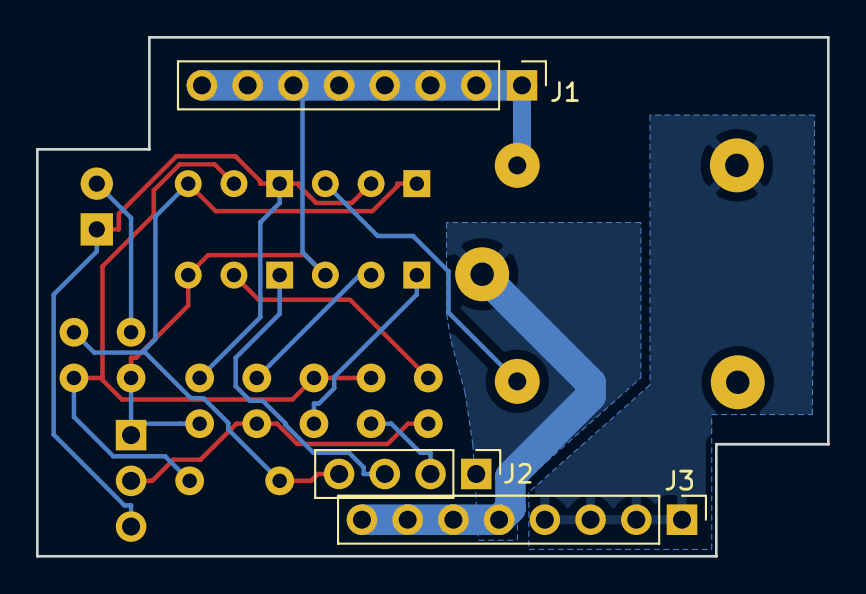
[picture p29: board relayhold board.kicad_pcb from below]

Board: 2 copper layers, 43.9 x 28.8 mm, 18 parts (3 on the bottom side), 14 nets.

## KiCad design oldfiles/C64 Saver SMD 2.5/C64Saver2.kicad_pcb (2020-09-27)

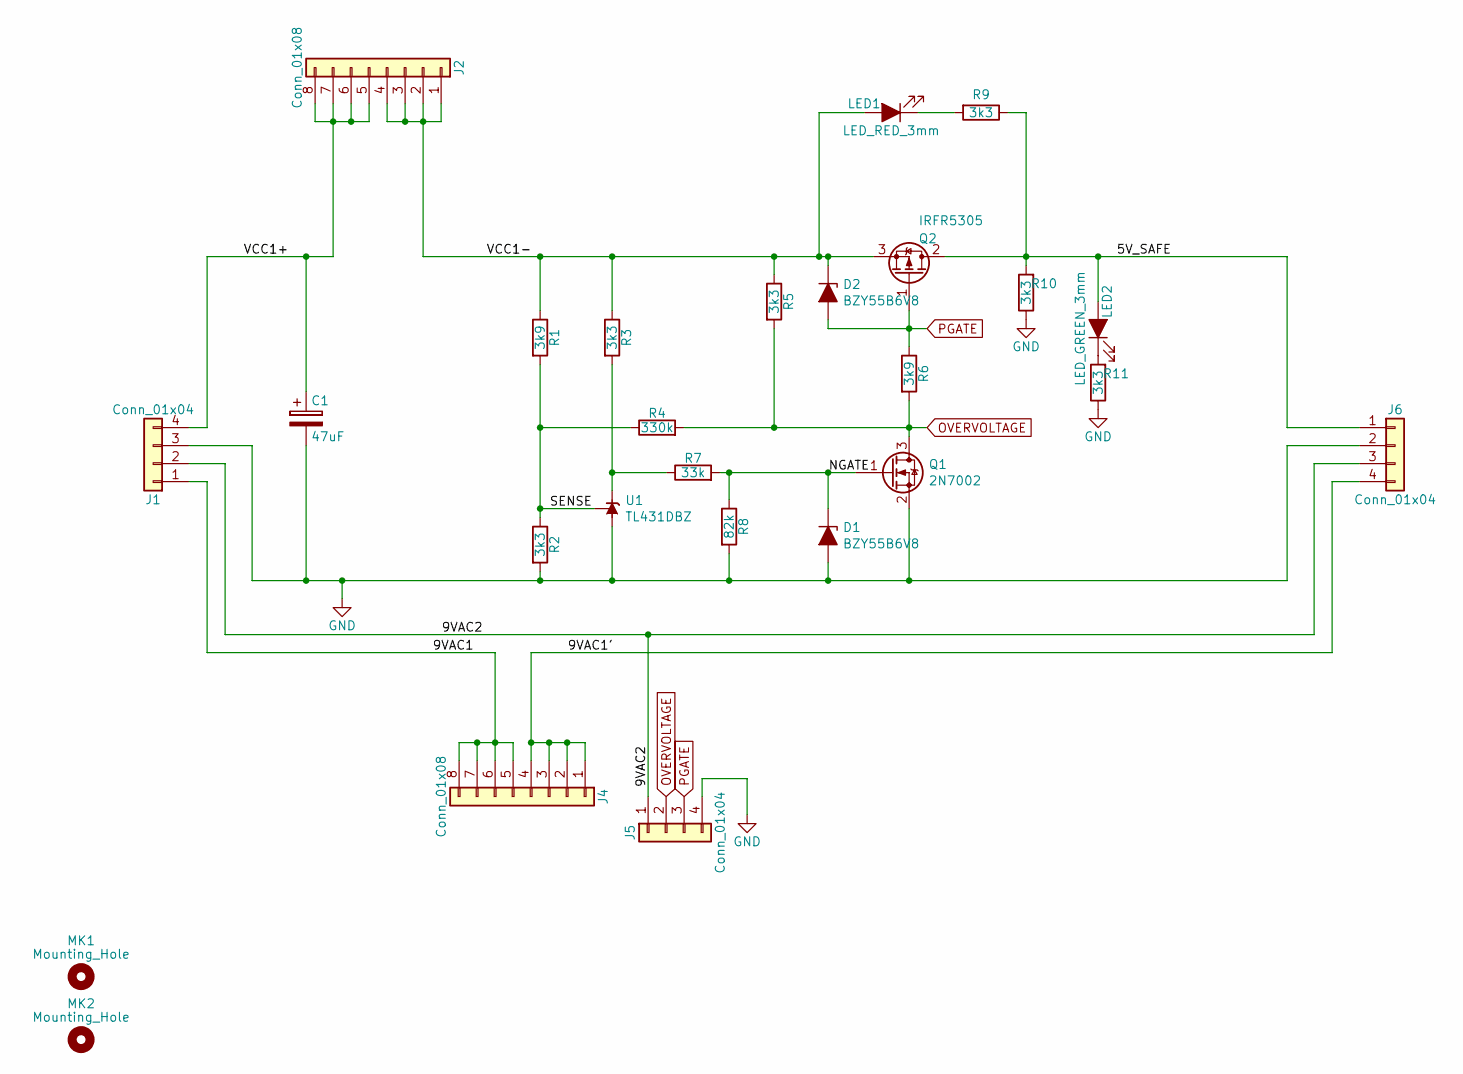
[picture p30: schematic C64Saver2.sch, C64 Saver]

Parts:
C1: 47uF; CP_Elec_6.3x5.4
D1, D2: BZY55B6V8; D_0805_2012Metric_Pad1.15x1.40mm_HandSolder
J1, J6: Conn_01x04; TerminalBlock_bornier-4_P5.08mm
J2, J4: Conn_01x08; Pin_Header_Straight_1x08_Pitch2.54mm
J5: Conn_01x04; Pin_Header_Straight_1x04_Pitch2.54mm
LED1: LED_RED_3mm; LED_D3.0mm
LED2: LED_GREEN_3mm; LED_D3.0mm
MK1, MK2: Mounting_Hole; MountingHole_2.5mm
Q1: 2N7002; SOT-23
Q2: IRFR5305; ATPAK-2
R1, R6: 3k9; R_0805_2012Metric_Pad1.15x1.40mm_HandSolder
R2, R3, R5, R9, R10, R11: 3k3; R_0805_2012Metric_Pad1.15x1.40mm_HandSolder
R4: 330k; R_0805_2012Metric_Pad1.15x1.40mm_HandSolder
R7: 33k; R_0805_2012Metric_Pad1.15x1.40mm_HandSolder
R8: 82k; R_0805_2012Metric_Pad1.15x1.40mm_HandSolder
U1: TL431DBZ; SOT-23

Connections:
/5V_SAFE: J6.1, LED2.2 (A), Q2.2 (D), R9.1, R10.2
/9VAC1: J1.1, J4.5, J4.6, J4.7, J4.8
/9VAC1': J4.1, J4.2, J4.3, J4.4, J6.4
/9VAC2: J1.2, J5.1, J6.3
/NGATE: D1.1 (K), Q1.1 (G), R7.2, R8.1
/SENSE: R1.2, R2.1, R4.1, U1.2 (REF)
/VCC1+: C1.1, J1.4, J2.5, J2.6, J2.7, J2.8
/VCC1-: D2.1 (K), J2.1, J2.2, J2.3, J2.4, LED1.2 (A), Q2.3 (S), R1.1, R3.1, R5.1
GND: C1.2, D1.2 (A), J1.3, J5.4, J6.2, Q1.2 (S), R2.2, R8.2, R10.1, R11.1, U1.3 (A)
unnamed: LED1.1 (K), R9.2
unnamed: LED2.1 (K), R11.2
unnamed: R3.2, R7.1, U1.1 (K)
OVERVOLTAGE: J5.2, Q1.3 (D), R4.2, R5.2, R6.2
PGATE: D2.2 (A), J5.3, Q2.1 (G), R6.1

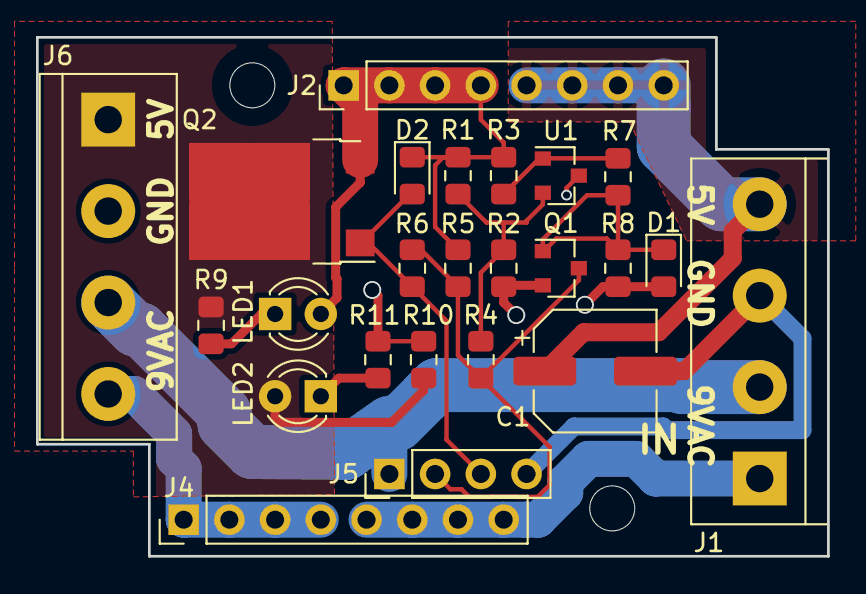
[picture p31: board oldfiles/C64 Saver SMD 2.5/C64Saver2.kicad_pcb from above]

Board: 2 copper layers, 43.9 x 28.8 mm, 26 parts (0 on the bottom side), 14 nets.

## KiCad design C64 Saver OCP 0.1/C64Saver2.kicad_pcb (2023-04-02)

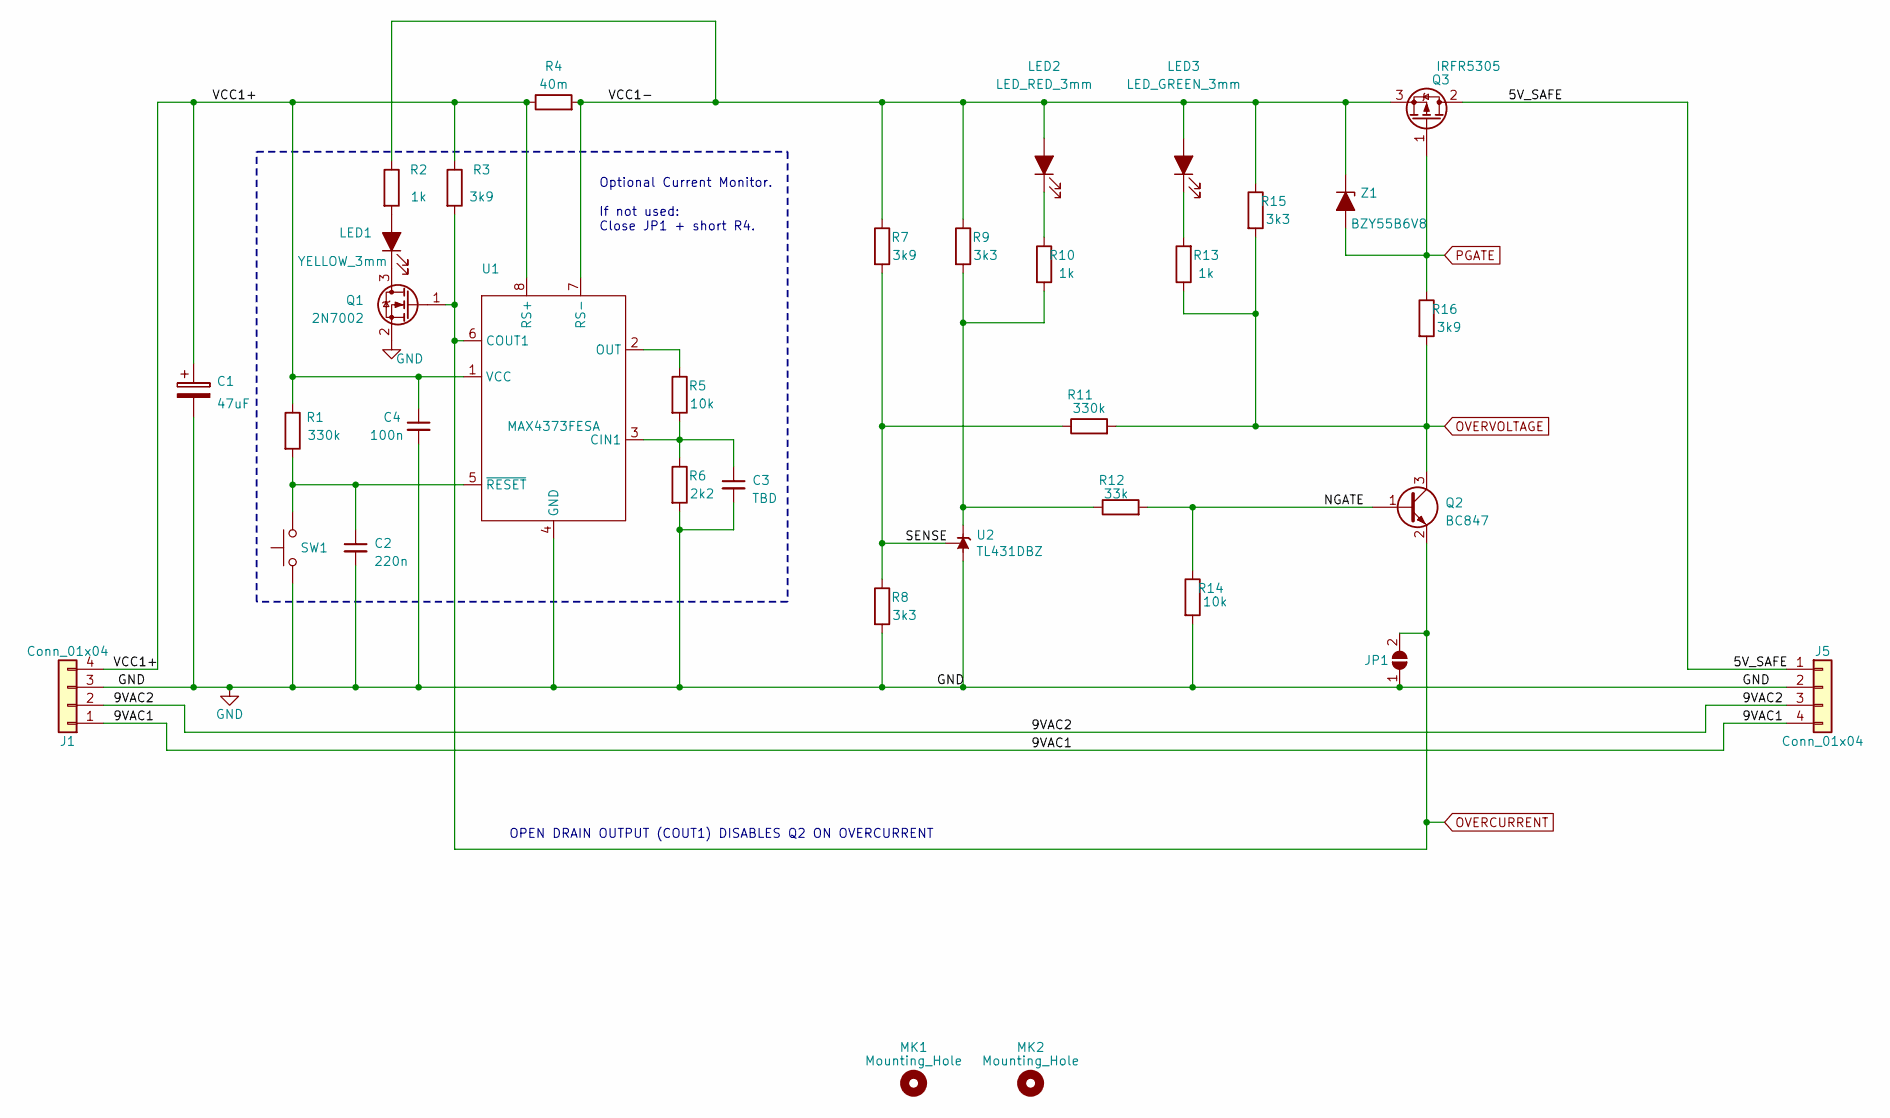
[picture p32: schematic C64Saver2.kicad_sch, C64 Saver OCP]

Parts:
C1: 47uF; CP_Elec_6.3x5.4; Digi-Key 493-3935-1-ND
C2: 220n; C_0603_1608Metric; Digi-Key 1276-1986-1-ND
C3: TBD; C_0603_1608Metric
C4: 100n; C_0603_1608Metric; Digi-Key 1276-1986-1-ND
J1, J5: Conn_01x04; TerminalBlock_bornier-4_P5.08mm; Digi-Key Not used
JP1: SolderJumper_2_Open; SolderJumper-2_P1.3mm_Open_RoundedPad1.0x1.5mm
LED1: YELLOW_3mm; LED_D3.0mm; Digi-Key 160-1968-ND
LED2: LED_RED_3mm; LED_D3.0mm; Digi-Key 160-1956-ND
LED3: LED_GREEN_3mm; LED_D3.0mm; Digi-Key 160-1142-ND
MK1, MK2: Mounting_Hole; MountingHole_2.5mm
Q1: 2N7002; SOT-23; Digi-Key 1727-8643-1-ND
Q2: BC847; SOT-23; Digi-Key 1727-2921-1-ND
Q3: IRFR5305; ATPAK-2; Digi-Key IRFR5305TRLPBFCT-ND
R1, R11: 330k; R_0603_1608Metric; Digi-Key P330KGCT-ND
R2, R10, R13: 1k; R_0603_1608Metric; Digi-Key P1.00KHCT-ND
R3, R7, R16: 3k9; R_0603_1608Metric; Digi-Key P3.9KGCT-ND
R4: 40m; R_2512_6332Metric; Digi-Key 1712-TLRP3A30WR040FTECT-ND
R5, R14: 10k; R_0603_1608Metric; Digi-Key P10.0KHCT-ND
R6: 2k2; R_0603_1608Metric; Digi-Key P2.20KHCT-ND
R8, R9, R15: 3k3; R_0603_1608Metric; Digi-Key P3.3KGCT-ND
R12: 33k; R_0603_1608Metric; Digi-Key P33KGCT-ND
SW1: SW_Push; SW_PUSH_6mm
U1: MAX4373FESA; SOIC-8_3.9x4.9mm_P1.27mm; Digi-Key MAX4373FESA+-ND
U2: TL431DBZ; SOT-23; Digi-Key 296-26721-1-ND
Z1: BZY55B6V8; D_0805_2012Metric_Pad1.15x1.40mm_HandSolder; Digi-Key 1727-3668-1-ND

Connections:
/5V_SAFE: J5.1, Q3.2 (D)
/9VAC1: J1.1, J5.4
/9VAC2: J1.2, J5.3
/NGATE: Q2.1 (B), R12.2, R14.1
/SENSE: R7.2, R8.1, R11.1, U2.2 (REF)
/VCC1+: C1.1, C4.1, J1.4, R1.1, R3.1, R4.1, U1.1 (VCC), U1.8 (RS+)
/VCC1-: LED2.2 (A), LED3.2 (A), Q3.3 (S), R2.1, R4.2, R7.1, R9.1, R15.1, U1.7 (RS-), Z1.1 (K)
GND: C1.2, C2.2, C3.2, C4.2, J1.3, J5.2, JP1.1 (A), Q1.2 (S), R6.2, R8.2, R14.2, SW1.2, U1.4 (GND), U2.3 (A)
unnamed: LED1.2 (A), R2.2
unnamed: LED1.1 (K), Q1.3 (D)
unnamed: LED2.1 (K), R10.1
unnamed: LED3.1 (K), R13.2
unnamed: C3.1, R5.2, R6.1, U1.3 (CIN1)
unnamed: R5.1, U1.2 (OUT)
unnamed: C2.1, R1.2, SW1.1, U1.5 (~RESET)
unnamed: R9.2, R10.2, R12.1, U2.1 (K)
OVERCURRENT: JP1.2 (B), Q1.1 (G), Q2.2 (E), R3.2, U1.6 (COUT1)
OVERVOLTAGE: Q2.3 (C), R11.2, R13.1, R15.2, R16.2
PGATE: Q3.1 (G), R16.1, Z1.2 (A)

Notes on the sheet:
OPEN DRAIN OUTPUT (COUT1) DISABLES Q2 ON OVERCURRENT
Optional Current Monitor. If not used: Close JP1 + short R4.

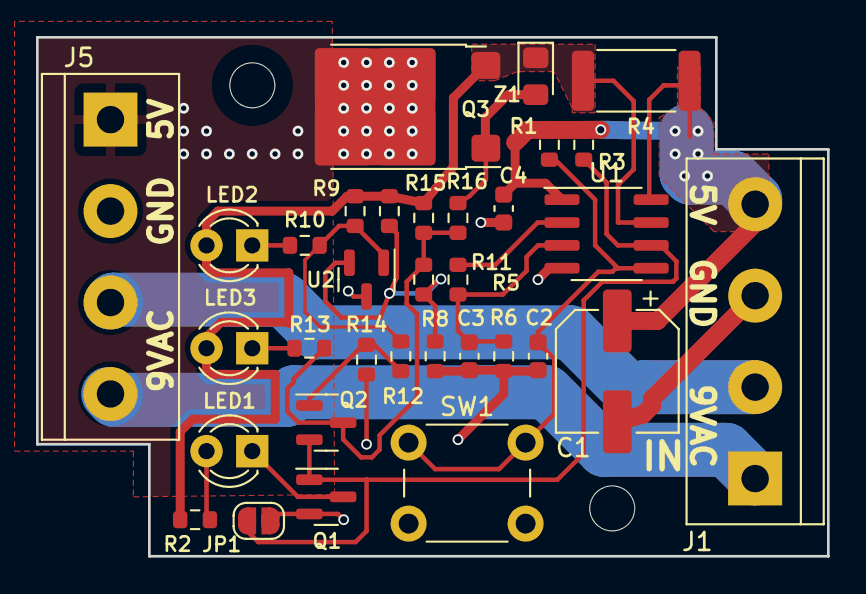
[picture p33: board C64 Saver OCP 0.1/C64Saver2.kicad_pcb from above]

Board: 2 copper layers, 43.9 x 28.8 mm, 35 parts (0 on the bottom side), 19 nets.

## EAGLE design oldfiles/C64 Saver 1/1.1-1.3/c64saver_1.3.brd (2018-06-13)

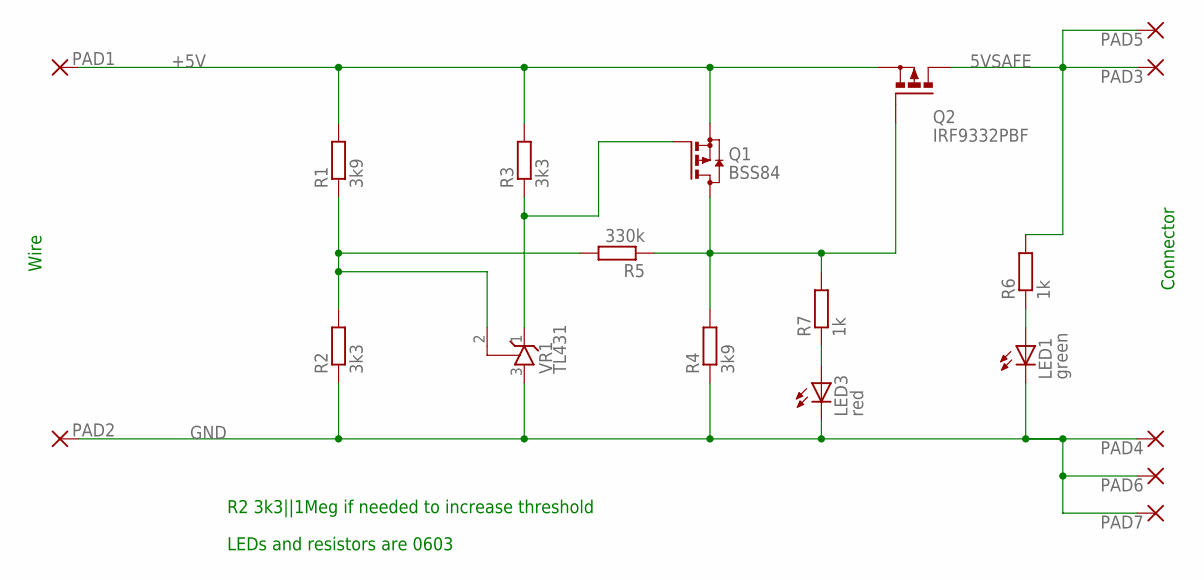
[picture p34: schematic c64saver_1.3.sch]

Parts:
LED1: green; CHIPLED_0603
LED3: red; CHIPLED_0603
PAD1, PAD2, PAD4, PAD6, PAD7: WIREPADSMD1,27-254; SMD1,27-2,54
PAD3, PAD5: WIREPADSMD2,54-2,54; SMD2,54-2,54
Q1: BSS84; SOT23
Q2: IRF9332PBF; SO-08
R1, R4: 3k9; R0603
R2, R3: 3k3; R0603
R5: 330k; R0603
R6, R7: 1k; R0603
VR1: TL431; SOT23

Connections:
5VSAFE: PAD3.1, PAD5.1, Q2.5 (D), Q2.6 (D), Q2.7 (D), Q2.8 (D), R6.2
+5V: PAD1.1, Q1.2 (S), Q2.1 (S), Q2.2 (S), Q2.3 (S), R1.2, R3.2
GND: LED1.C, LED3.C, PAD2.1, PAD4.1, PAD6.1, PAD7.1, R2.1, R4.1, VR1.3 (A)
unnamed: LED3.A, R7.1
unnamed: R1.1, R2.2, R5.2, VR1.2 (R)
unnamed: LED1.A, R6.1
unnamed: Q1.1 (G), R3.1, VR1.1 (C)
unnamed: Q1.3 (D), Q2.4 (G), R4.2, R5.1, R7.2

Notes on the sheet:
R2 3k3||1Meg if needed to increase threshold
Wire
Connector
LEDs and resistors are 0603



Board: 2 copper layers, 14.7 x 10.8 mm, 19 parts (8 on the bottom side), 8 nets.

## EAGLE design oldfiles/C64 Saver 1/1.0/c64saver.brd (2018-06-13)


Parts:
C1: NC; C0603
LED1: red; CHIPLED_1206
LED2: green; CHIPLED_1206
LSP1, LSP2, LSP3, LSP4, LSP5, LSP6, LSP7, LSP8: SE14
PAD1, PAD2, PAD3: SMD2; SMD1,27-2,54
Q1: BSS84; SOT23
Q2: FDS4435A; SO-08
R1, R6: 3k9; R0603
R2, R7: 100k; R0603
R3: NC; R0603
R4, R5: 3k3; R0603
R8, R9: 1k; R0603
VR1: TL431CLPSOT23; SOT23

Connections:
5VSAFE: LSP8.MP, Q2.5 (D), Q2.6 (D), Q2.7 (D), Q2.8 (D)
9VAC1: LSP2.MP, LSP6.MP
9VAC2: LSP1.MP, LSP5.MP
+5V: LED2.A, LSP4.MP, Q1.2 (S), Q2.1 (S), Q2.2 (S), Q2.3 (S), R1.2, R2.2, R5.2
GND: C1.2, LSP3.MP, LSP7.MP, R3.1, R4.1, R6.1, R8.1, R9.1, VR1.3 (A)
unnamed: C1.1, PAD1.1, R1.1, R2.1, R3.2, R4.2, R7.2, VR1.2 (R)
unnamed: LED1.C, R8.2
unnamed: LED2.C, R9.2
unnamed: PAD2.1, Q1.1 (G), R5.1, VR1.1 (C)
unnamed: LED1.A, PAD3.1, Q1.3 (D), Q2.4 (G), R6.2, R7.1



Board: 2 copper layers, 31.1 x 16.8 mm, 26 parts (3 on the bottom side), 10 nets.

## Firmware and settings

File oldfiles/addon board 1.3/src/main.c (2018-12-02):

/**
 * SSD1306xLED - Library/Driver for the SSD1306 based OLED/PLED 128x64 displays
 *
 * @author Neven Boyanov
 *
 * This is part of the Tinusaur/SSD1306xLED project.
 *
 * Copyright (c) 2018 Neven Boyanov, The Tinusaur Team. All Rights Reserved.
 * Distributed as open source software under MIT License, see LICENSE.txt file.
 * Retain in your source code the link http://tinusaur.org to the Tinusaur project.
 *
 * Source code available at: https://bitbucket.org/tinusaur/ssd1306xled
 *
 */

// ============================================================================
// NOTE: About F_CPU - it should be set in either (1) Makefile; or (2) in the IDE.
#include <stdio.h>
#include <string.h>
#include <stdint.h>
#include <avr/io.h>
#include <avr/interrupt.h>
#include <avr/eeprom.h>
#include <util/delay.h>

//#include "tinyavrlib/cpufreq.h"

#include "font8x16.h"
#include "ssd1306xled.h"
#include "num2str.h"
#include "ina219.h"

// ~~~~~~~~~~~~~~~~~~~~~~~~~~~~~~~~~~~~~~~~~~~~~~~~~~~~~~~~~~~~~~~~~~~~~~~~~~~~
//           ATtiny85
//         +----------+
//     (RST)---+ PB5  Vcc +---(+)--VCC--
// ---[OWOWOD]---+ PB3  PB2 +---[TWI/SCL]-
// --------------+ PB4  PB1 +-------------
// ---GND--(-)---+ GND  PB0 +---[TWI/SDA]-
//         +----------+
//        Tinusaur Board
// ~~~~~~~~~~~~~~~~~~~~~~~~~~~~~~~~~~~~~~~~~~~~~~~~~~~~~~~~~~~~~~~~~~~~~~~~~~~~

// ----------------------------------------------------------------------------

//#define F_CPU 8000000UL    // 8 MHz

#define SSD1306_SCL   PB2
#define SSD1306_SDA   PB0
#define HOLD_N        PB1

#define HOLD_ON       PORTB |= (1 << HOLD_N)
#define HOLD_OFF      PORTB &= ~(1 << HOLD_N)

#define SSD1306_SA    0x78  // Slave address

#define INA219_SA    0b1000000 // Slave address

// ----------------------------------------------------------------------------

#define STEPS_DELAY_SHORT 200
#define STEPS_DELAY 600
#define STEPS_DELAY_LONG 1000

enum { MEASURE_VAC=0, MEASURE_ACCUR=1, WRITE_VDC=2, WRITE_DCCUR=3 };
uint8_t state = 0;

struct config {
  uint8_t oc; // in amps*10
  uint8_t hold;
  uint8_t vtrip;
};
struct config conf;

uint8_t overcurrent_flag = 0;
uint8_t overvoltage_flag = 0;

uint8_t EEMEM EEOvercurrent;
uint8_t EEMEM EEHold;
uint8_t EEMEM EEVtrip;

void init(void) {
  conf.oc=12; // 1.2A
  conf.hold=1; // 1=hold, 0=autorecover
  conf.vtrip=55; // 5.5V

  uint8_t ee_oc=255, ee_hold=255, ee_vtrip=255;
  ee_oc = eeprom_read_byte(&EEOvercurrent);
  ee_hold = eeprom_read_byte(&EEHold);
  ee_vtrip = eeprom_read_byte(&EEVtrip);
  if (ee_oc<255) conf.oc = ee_oc;
  if (ee_hold<255) conf.hold = ee_hold;
  if (ee_vtrip<255) conf.vtrip = ee_vtrip;
  
  // disable interrupts
  GIMSK = PCMSK = USICR = USISR = 0;
  cli();
  // enable global pullups
  MCUCR &= ~(1 << PUD);

  // set SDA and SCL to tri-state
  DDRB &= ~((1 << PB0) | (1 << PB2));
  PORTB &= ~((1 << PB0) | (1 << PB2));

  // wait a bit until everything stabilises
  _delay_ms(40);

  ssd1306xled_font8x16 = ssd1306xled_font8x16data;
  ssd1306_init();

  initINA();

  DDRB |= (1 << HOLD_N); 
  HOLD_OFF;
}

void formatNumber(uint16_t value, char *buf, uint8_t maxlen, uint8_t decimals, uint8_t decimalpoint, char* unit) {
  memset(buf,0,maxlen);
  uint8_t offset=0;
  if (maxlen < 5+1+strlen(unit)+1) return; // 5 digits + 1 dot + string length of unit + zero terminator
  if (decimals>5) return;
  snprintf(buf,maxlen,"%5d",value);
  //printf("-%s-\n", buf);
  
  // align field by number of decimal  12.345uu
  offset = 5-decimals;
  int i;
  for(i=0; i<(decimals); i++)
    buf[i]=buf[i+offset];
  buf[decimals]=0;    
  //printf("-%s-\n", buf);

  // pad leading zeroes
  for(int i=0; i<decimals; i++) {
    if(buf[i]==' ' && i>=(decimals-decimalpoint-1)) buf[i]='0';
  }
  //printf("-%s-\n", buf);

  // add the dot
  if(decimalpoint>0) {
    for(int i=decimals; i>=decimals-decimalpoint; i--)   
      buf[i+1]=buf[i]; // move to right for dot
    buf[decimals-decimalpoint]='.';
  }
  //printf("-%s-\n", buf);
  
  // add unit
  char* ptr = buf + decimals+1; // decimals + dot
  snprintf(ptr, maxlen-5, "%s", unit);
}

void adc_setup(uint8_t channel) {
  ADMUX = (1<<ADLAR) | channel; // SENSE_VAC
  //ADMUX = (1<<ADLAR) | (1<<MUX1) | (1<<MUX0); // SENSE_ACCUR
  //ADMUX = (1<<REFS1)|(1<<ADLAR)|(1<<REFS2)|(1<<MUX1);
}

uint16_t read_adc(void) {
  ADCSRA = (1<<ADEN) | (1<<ADSC) | (1<<ADPS1) | (1<<ADPS0); // conversion start
  while(ADCSRA & (1<<ADSC)); // wait for conversion
  uint8_t adl = ADCL;
  uint8_t adh = ADCH;
  return (adh<<2) | (adl>>6);
}

uint16_t read_adc_vac(int *buttondown) {
  static uint16_t adc_present_value;
  static uint16_t i=0;
  static uint16_t adchigh=0x0000, adclow=0xffff;
  uint16_t adcval = read_adc();
  if (adcval<100) {
    *buttondown=1;
    return adc_present_value;
  }
  *buttondown=0;
  i++;
  if (i>3000) {
    adc_present_value = adchigh-adclow;
    i=0;
    adchigh=0;
    adclow=0xffff;
  } else {
    if(adcval>adchigh) adchigh=adcval;
    if(adcval<adclow) adclow=adcval;
  }
  return adc_present_value;
}

uint16_t read_adc_accur(void) {
  static uint16_t adc_present_value;
  static uint16_t i=0;
  static uint16_t adchigh=0x0000, adclow=0xffff;
  uint16_t adcval = read_adc();
  i++;
  if (i>3000) {
    adc_present_value = adchigh-adclow;
    i=0;
    adchigh=0;
    adclow=0xffff;
  } else {
    if(adcval>adchigh) adchigh=adcval;
    if(adcval<adclow) adclow=adcval;
  }
  return adc_present_value;
}

void setup_timer1(uint8_t delay) {
  TCCR1 = (0b1110<<CS10);
  OCR1A = delay;	
  TCNT1 = 0;
  TIFR |= (1<<OCF1A);
}

uint8_t has_timed_out(void) {
  return ((TIFR & (1<<OCF1A))>0)  ? 1 : 0;

}

void reset_timer1(void) {
    TIFR |= (1<<OCF1A);
    TCNT1 = 0;		
}

enum buttonpress {BUTTON_IDLE=0, BUTTON_SHORT_PRESS=1, BUTTON_LONG_PRESS=2};

uint8_t read_button(uint8_t buttondown) {
  static uint8_t cnt = 0;
  static uint8_t longpress=0;
  if (buttondown && longpress) return BUTTON_IDLE;
  longpress=0;
  if (buttondown) {
    cnt++;
    if (cnt>10) {
      cnt=0;
      longpress=1; // remember it
      return BUTTON_LONG_PRESS;
    }
  }
  else {
    if(cnt>1) {
      cnt=0;
      return BUTTON_SHORT_PRESS;
    }
    cnt=0;
  }
  return BUTTON_IDLE;
}

uint16_t recorded_overcurrent=0;

void main_screen(uint16_t adc_vac, uint16_t adc_accur, uint16_t busvoltage, uint16_t current, int _button) {
  char buf[8];

  const int decimals=5, decimalpoint=3;
  if (state==MEASURE_VAC) {
    formatNumber(adc_vac*19/100+adc_vac*2/100, buf, sizeof(buf), 3, 1, "V"); 
    //formatNumber(recorded_overcurrent, buf, sizeof(buf), 5, 3, "A"); 
    ssd1306_string_font8x16xy(0,0,buf);
  }
  else if (state==MEASURE_ACCUR) {
    formatNumber(adc_accur, buf, sizeof(buf), 4, 0, "A"); 
    ssd1306_string_font8x16xy(0,2,buf);
  }
  else if (state==WRITE_VDC) {
    formatNumber(busvoltage, buf, sizeof(buf), decimals, decimalpoint, "V"); 
    if (overvoltage_flag|| busvoltage>5500) {
      static uint8_t flash=0;
      flash++;
      if (flash>21) strcpy(buf,"       ");
      if (flash>25) flash=0;
    }
    ssd1306_string_font8x16xy(7*10,2,buf);
  }
  else if (state==WRITE_DCCUR) {
    formatNumber(current, buf, sizeof(buf), decimals, decimalpoint, "A"); 
    if (overcurrent_flag) {
      static uint8_t flash=0;
      flash++;
      formatNumber(recorded_overcurrent, buf, sizeof(buf), decimals, decimalpoint, "A"); 
      if (flash>21) strcpy(buf,"       ");
      if (flash>25) flash=0;
    }
    else 
      formatNumber(current, buf, sizeof(buf), decimals, decimalpoint, "A"); 
    ssd1306_string_font8x16xy(7*10,0,buf);
  }  
}

void overcurrent_screen(void) {
  char buf[8];
  if (state==MEASURE_VAC) {
    ssd1306_string_font8x16xy(0,0,"Overcurrent");
    formatNumber(conf.oc, buf, sizeof(buf), 2, 1, "A"); 
    ssd1306_string_font8x16xy(8*3,2,buf);
    ssd1306_string_font8x16xy(8*6,2,"A");
  }
}

uint8_t oc_temp=0;

void set_overcurrent_screen(uint8_t button) {
  if (button==BUTTON_LONG_PRESS) oc_temp = conf.oc;
  if (button==BUTTON_SHORT_PRESS) {
    oc_temp += 1; // +0.1A
    if (oc_temp>20) oc_temp=5;
  }
  if (state==WRITE_DCCUR)
    ssd1306_string_font8x16xy(8*3,2,"    ");
  else if (state==MEASURE_VAC) {
    char buf[8];
    formatNumber(oc_temp, buf, sizeof(buf), 2, 1, "A"); 
    ssd1306_string_font8x16xy(8*3,2,buf);
  }
    
}

void overvoltage_hold_screen(void) {
  ssd1306_string_font8x16xy(0,0,"Overvoltage Hold");
  if (conf.hold)
    ssd1306_string_font8x16xy(8*3,2,"HOLD       ");
  else
    ssd1306_string_font8x16xy(8*3,2,"AUTORECOVER");
}

uint8_t hold_temp = 0;

void set_overvoltage_hold_screen(uint8_t button) {
  if (button==BUTTON_LONG_PRESS) hold_temp = conf.hold;
  if (button==BUTTON_SHORT_PRESS) {
    hold_temp += 1;
    if (hold_temp>1) hold_temp=0;
  }
  if (state!=WRITE_DCCUR) {
    if (hold_temp)
      ssd1306_string_font8x16xy(8*3,2,"HOLD       ");
    else
      ssd1306_string_font8x16xy(8*3,2,"AUTORECOVER");
  }
  else
    ssd1306_string_font8x16xy(8*3,2,"           ");
}

void dc_volt_trippoint_screen(void) {
  char buf[8];
  ssd1306_string_font8x16xy(0,0,"Voltage Trippnt.");
  if (conf.vtrip==55)
    ssd1306_string_font8x16xy(8*2,2,"5.5V Hardware");
  else {
    formatNumber(conf.vtrip, buf, sizeof(buf), 2, 1, "V"); 
    ssd1306_string_font8x16xy(8*2,2,buf);
    ssd1306_string_font8x16xy(8*7,2,"Software");
  }
}

uint8_t ov_temp=0;

void set_dc_volt_trippoint_screen(uint8_t button) {
  char buf[8];
  if (button==BUTTON_LONG_PRESS) ov_temp = conf.vtrip;
  if (button==BUTTON_SHORT_PRESS) {
    ov_temp += 1; // +0.1V
    if (ov_temp>55) ov_temp=51;
  }
  if (state==MEASURE_VAC) {
    if (ov_temp==55)
      ssd1306_string_font8x16xy(8*2,2,"5.5V Hardware");
    else {
      formatNumber(ov_temp, buf, sizeof(buf), 2, 1, "V"); 
      ssd1306_string_font8x16xy(8*2,2,buf);
      ssd1306_string_font8x16xy(8*7,2,"Software");
    }
  }
  else if (state==WRITE_DCCUR)
    ssd1306_string_font8x16xy(8*2,2,"    ");
}


enum { MENUSCREEN=0, RECOVER,
DC_OVERCCURRENT,   SET_DC_OVERCURRENT,   STORE_DC_OVERCURRENT,
OVERVOLTAGE_HOLD,  SET_OVERVOLTAGE_HOLD, STORE_OVERVOLTAGE_HOLD,
DC_VOLT_TRIPPOINT, SET_DC_VOLT_TRIPPOINT, STORE_DC_VOLT_TRIPPOINT };

uint8_t next_screen_state(uint8_t presentstate, uint8_t button) {
  uint8_t nextstate=presentstate;
  switch(presentstate) {
    case MENUSCREEN:
      if (button==BUTTON_SHORT_PRESS) nextstate = DC_OVERCCURRENT;
      else if (button==BUTTON_LONG_PRESS) nextstate = RECOVER;
      break;
    case DC_OVERCCURRENT:
      if (button==BUTTON_SHORT_PRESS) nextstate = OVERVOLTAGE_HOLD;
      else if (button==BUTTON_LONG_PRESS) nextstate = SET_DC_OVERCURRENT;
      break;
    case OVERVOLTAGE_HOLD:
      if (button==BUTTON_SHORT_PRESS) nextstate = DC_VOLT_TRIPPOINT;
      else if (button==BUTTON_LONG_PRESS) nextstate = SET_OVERVOLTAGE_HOLD;
      break;
    case DC_VOLT_TRIPPOINT:
      if (button==BUTTON_SHORT_PRESS) nextstate = MENUSCREEN;
      else if (button==BUTTON_LONG_PRESS) nextstate = SET_DC_VOLT_TRIPPOINT;
      break;
      
    case SET_DC_OVERCURRENT:
      if (button==BUTTON_LONG_PRESS) nextstate = STORE_DC_OVERCURRENT;
      break;
    case SET_OVERVOLTAGE_HOLD:
      if (button==BUTTON_LONG_PRESS) nextstate = STORE_OVERVOLTAGE_HOLD;
      break;
    case SET_DC_VOLT_TRIPPOINT:
      if (button==BUTTON_LONG_PRESS) nextstate = STORE_DC_VOLT_TRIPPOINT;
      break;
      
    case STORE_DC_OVERCURRENT:
      nextstate = DC_OVERCCURRENT;
      break;
    case STORE_OVERVOLTAGE_HOLD:
      nextstate = OVERVOLTAGE_HOLD;
      break;
    case STORE_DC_VOLT_TRIPPOINT:
      nextstate = DC_VOLT_TRIPPOINT;
      break;

    case RECOVER:
      nextstate = MENUSCREEN;
      break;

    default:
      break;
  }
  return nextstate;
}

int main(void) {
//  int count = 0;
  init();
  ssd1306_clear();

  I2C_reset();
  _delay_ms(50); // ms loop
  setup_timer1(10);
  adc_setup(2);
  static int buttondown=0;
  uint16_t adc_vac=0,adc_accur=0;
  uint8_t button = BUTTON_IDLE;
  uint8_t present_screen_state=MENUSCREEN;
  uint16_t dcvoltage = 0;
  uint16_t dccurrent = 0;
  _delay_ms(100);

  while (1) {
    //uint16_t configval, shuntvoltage;
    //const int reg_addr_config = 0;
    //const int shunt_voltage_reg = 1;
    //const int bus_voltage_reg = 2;
    //const int power_reg = 3;
    //const int current_reg = 4;
    //const int calibration_reg = 5;

    if (state==MEASURE_VAC || state==WRITE_VDC) {
      buttondown=0;
      adc_vac = read_adc_vac(&buttondown);
  
    } else if (state==MEASURE_ACCUR || state==WRITE_DCCUR) {
      adc_accur = read_adc_accur();
    }
    if ( has_timed_out() ) {
      reset_timer1();
     //HOLD_ON;
      //read_register(reg_addr_config, &configval);
      //read_register(shunt_voltage_reg, &shuntvoltage);
      //adc_setup(2);
      //adc_vac = read_adc_vac(&buttondown);

      if (state==MEASURE_VAC) {
        button = read_button(buttondown);
        uint8_t old_state = present_screen_state;
        present_screen_state = next_screen_state(present_screen_state, button);
        if(old_state != present_screen_state) ssd1306_clear();
      }

      if (overcurrent_flag && !overvoltage_flag) {
        static uint16_t cnt=0;
        cnt++;
        if (cnt>500) {
          cnt=0;
          overcurrent_flag=0;
          HOLD_OFF;
          _delay_ms(20);
        }
      }
      dcvoltage = ina219_get_bus_voltage_mv();
      dccurrent = ina219_get_current_ma();
      if (overvoltage_flag && dcvoltage < (conf.vtrip*100)-100 && !conf.hold) {
        present_screen_state = RECOVER;
      }

      // handle limits

      if (dccurrent > conf.oc*100 && !overcurrent_flag) {
        recorded_overcurrent = dccurrent;
        overcurrent_flag = 1;
      }
      
//      if (conf.vtrip < 55 && dcvoltage >= conf.vtrip*100 && !overvoltage_flag) {
      if (dcvoltage >= conf.vtrip*100 && !overvoltage_flag) {
        overvoltage_flag = 1;
      }
      
      switch(present_screen_state) {
        case MENUSCREEN:            main_screen(adc_vac,adc_accur,dcvoltage,dccurrent,button); break;
        case DC_OVERCCURRENT:       overcurrent_screen(); break;
        case OVERVOLTAGE_HOLD:      overvoltage_hold_screen(); break;
        case DC_VOLT_TRIPPOINT:     dc_volt_trippoint_screen(); break;
        
        case SET_DC_OVERCURRENT:    set_overcurrent_screen(button); break;
        case SET_OVERVOLTAGE_HOLD:  set_overvoltage_hold_screen(button); break;
        case SET_DC_VOLT_TRIPPOINT: set_dc_volt_trippoint_screen(button); break;
        
        case STORE_DC_OVERCURRENT:
          conf.oc = oc_temp; eeprom_write_byte(&EEOvercurrent, conf.oc); break;
        case STORE_OVERVOLTAGE_HOLD:
          conf.hold = hold_temp; eeprom_write_byte(&EEHold, conf.hold); break;
        case STORE_DC_VOLT_TRIPPOINT:
          conf.vtrip = ov_temp; eeprom_write_byte(&EEVtrip, conf.vtrip); break;
        case RECOVER:
          HOLD_OFF; overcurrent_flag=0; overvoltage_flag=0; break;
      }

      if (overcurrent_flag || overvoltage_flag) HOLD_ON;
      else HOLD_OFF;
      
      // next state
      state++;
      state = state & 0x03;
      if (state==MEASURE_VAC || state == WRITE_VDC) {
        adc_setup(2);
      } else if (state==MEASURE_ACCUR || state == WRITE_DCCUR){
        adc_setup(3);
      }
      button = BUTTON_IDLE;
      //HOLD_OFF;
    }
  }
  return 0;
}

// ============================================================================

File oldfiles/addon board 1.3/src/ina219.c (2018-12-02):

#include <stdint.h>
#include <avr/io.h>
#include <util/delay.h>
#include "ina219.h"

//#define SLAVE_ADDRESS    0b1000000

#define SCL          PB2
#define SDA          PB0

#define TICK    5
#define HALF_TICK  (TICK / 2.0)

enum {
  REG_ADDR_CONFIG,
  REG_ADDR_SHUNT_VOLTAGE,
  REG_ADDR_BUS_VOLTAGE,
  REG_ADDR_POWER,
  REG_ADDR_CURRENT,
  REG_ADDR_CALIBRATION
};


#define DIGITAL_WRITE_HIGH(PORT, PAUSE)    { PORTB |= (1 << PORT); if (PAUSE) { _delay_us(TICK); } }
#define DIGITAL_WRITE_LOW(PORT, PAUSE)    { PORTB &= ~(1 << PORT); if (PAUSE) { _delay_us(TICK); } }
//#define DIGITAL_WRITE_BOTH_HIGH(PORT1, PORT2)  { PORTB |= ((1 << PORT1) | (1 << PORT2)); _delay_us(TICK); }
//#define DIGITAL_WRITE_BOTH_LOW(PORT1, PORT2)  { PORTB &= ~((1 << PORT1) | (1 << PORT2)); _delay_us(TICK); }

// When switching between tri-state ({DDxn, PORTxn} = 0b00) and output high ({DDxn, PORTxn} = 0b11),
// an intermediate state with either pull-up enabled {DDxn, PORTxn} = 0b01) or output
// low ({DDxn, PORTxn} = 0b10) must occur.
#define SET_SDA_INPUT()     { DDRB &= ~(1 << SDA); PORTB |= (1 << SDA); }
#define SET_SCL_INPUT()     { DDRB &= ~(1 << SCL); PORTB |= (1 << SCL); }
// Switching between input with pull-up and output low generates the same problem.
// The user must use either the tristate ({DDxn, PORTxn} = 0b00) or the output high
// state ({DDxn, PORTxn} = 0b10) as an intermediate step.
//#define SET_SDA_OUTPUT()    { DDRB &= ~(1 << SDA); PORTB &= ~(1 << SDA); DDRB |= (1 << SDA); }
//#define SET_SCL_OUTPUT()    { DDRB &= ~(1 << SCL); PORTB &= ~(1 << SCL); DDRB |= (1 << SCL); }
#define SET_SDA_OUTPUT()    { DDRB |= (1 << SDA); }
#define SET_SCL_OUTPUT()    { DDRB |= (1 << SCL); }
#define IS_INPUT(PORT)      (0 == (DDRB & (1 << PORT)))
#define IS_OUTPUT(PORT)      (0 != (DDRB & (1 << PORT)))

#define INA_CONFIG_REG  0b0001100110011111

uint8_t slave_address;

void xfer_start(void) {
  SET_SCL_OUTPUT();
  DIGITAL_WRITE_LOW(SCL, 1);
  SET_SDA_OUTPUT();
  DIGITAL_WRITE_HIGH(SDA, 1);
  DIGITAL_WRITE_HIGH(SCL, 1);
  DIGITAL_WRITE_LOW(SDA, 1);
  DIGITAL_WRITE_LOW(SCL, 1);
}

void xfer_stop(void) {
  SET_SDA_OUTPUT();
  DIGITAL_WRITE_LOW(SDA, 1);
  SET_SCL_OUTPUT();
  DIGITAL_WRITE_HIGH(SCL, 1);
  DIGITAL_WRITE_HIGH(SDA, 1);
  //DIGITAL_WRITE_LOW(SCL, 1);
  // INA has 28ms timeout after STOP
  //_delay_ms(30);
}

int send_byte(uint8_t byte) {
  uint8_t i;

  if (IS_INPUT(SDA)) {
    SET_SDA_OUTPUT();
  }
  if (IS_INPUT(SCL)) {
    SET_SCL_OUTPUT();
  }
  for (i = 0; i < 8; i++) {
    if ((byte << i) & 0x80) {
      DIGITAL_WRITE_HIGH(SDA, 0);
    } else {
      DIGITAL_WRITE_LOW(SDA, 0);
    }
    _delay_us(1);
    DIGITAL_WRITE_HIGH(SCL, 1);
    DIGITAL_WRITE_LOW(SCL, 0);
    _delay_us(4);
  }
  // wait for ACK after each byte
  _delay_us(TICK);
  SET_SDA_INPUT();
  _delay_us(1);
  DIGITAL_WRITE_HIGH(SCL, 0);
  _delay_us(HALF_TICK);
  int result = PORTB & (1 << SDA);
  _delay_us(HALF_TICK);
  DIGITAL_WRITE_LOW(SCL, 0);
  SET_SDA_OUTPUT();
  DIGITAL_WRITE_LOW(SDA, 1);

  return result;
}

uint8_t receive_byte(uint8_t last) {
  uint8_t i, val = 0;

  SET_SDA_INPUT();
  for (i = 0; i < 8; i++) {
    DIGITAL_WRITE_HIGH(SCL, 1);
    val <<= 1;
    val |= (PINB & (1 << SDA)) ? 0x01 : 0x00;
    DIGITAL_WRITE_LOW(SCL, 1);
  }
  SET_SDA_OUTPUT();
  if (last) {
    // send NACK
    DIGITAL_WRITE_HIGH(SDA, 1);
  } else {
    // send ACK
    DIGITAL_WRITE_LOW(SDA, 1);
  }
  DIGITAL_WRITE_HIGH(SCL, 1);
  DIGITAL_WRITE_LOW(SCL, 1);
  return val;
}

void write_register(uint8_t reg, uint16_t val) {
  xfer_start();
  send_byte((uint8_t)((slave_address << 1) & 0xfe));
  send_byte(reg);
  send_byte((uint8_t)((val >> 8) & 0xff));
  send_byte((uint8_t)(val & 0xff));
  xfer_stop();
}

void read_register(uint8_t reg, uint16_t *buf) {
  xfer_start();
  send_byte((slave_address << 1));
  send_byte(reg);
  xfer_stop();
  xfer_start();
  send_byte((uint8_t)((slave_address << 1) | 0x01));
  *buf = (receive_byte(0) << 8 ) | receive_byte(1);
  xfer_stop();
}

void I2C_reset(void) {
  // hold SDA or SCL low for at least 28ms
  SET_SDA_INPUT();
  SET_SCL_OUTPUT();
  DIGITAL_WRITE_LOW(SCL, 0);
  _delay_ms(30);
  SET_SCL_INPUT();
  // INA has 28ms timeout after STOP
  // this is not a STOP but let's wait anyway
  _delay_ms(30);
}

uint8_t I2C_autodetect_slave_address(void) {
  uint8_t current_address, found_address = 0;
  for (current_address = 0b1000000; current_address <= 0b1001111; current_address++) {
    // repeated start
    xfer_start();
    if (0 == send_byte((uint8_t) (current_address << 1))) {
      // found it
      found_address = current_address;
      break;
    }
    _delay_us(25);
  }
  xfer_stop();
  return found_address;
}

void initINA(void) {
  slave_address = 0b1000000;

  uint16_t calValue = 400;
  write_register(REG_ADDR_CALIBRATION, calValue);
  uint16_t config = 0b0011000111111111;
  write_register(REG_ADDR_CONFIG, config);
}

uint16_t ina219_get_bus_voltage_mv() {
  uint16_t busvoltage;
  initINA();
  read_register(REG_ADDR_BUS_VOLTAGE, &busvoltage);
  return (busvoltage>>1) + (busvoltage & 0x0001);
}

uint16_t ina219_get_current_ma(void) {
  uint16_t current;
  read_register(REG_ADDR_CURRENT, &current);
  return current;
}

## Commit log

2018-06-13 inital commit 1.0 saver
    [c64saver.sch, resistorcalc.ods]
2018-06-13 1.1 to 1.3
    [c64saver.brd, c64saver_1.1.brd, c64saver_1.1.sch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]
2018-06-17 C64 Saver 2 first commit
    [C64Saver2-addon.kicad_pcb, C64Saver2-addon.sch, C64Saver2.kicad_pcb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]
2018-06-17 Tidy up project libraries. Relative paths
    [C64Saver2-addon.kicad_pcb, C64Saver2-addon.sch]
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2018-06-25 Name, revision, author on silk.s
    [C64Saver2.kicad_pcb]
2018-06-25 revision on addon board
    [C64Saver2-addon.kicad_pcb]
2018-07-02 saver 2.0beta - addon 1.0beta
    [C64Saver2-addon.kicad_pcb, C64Saver2-addon.sch, C64Saver2.kicad_pcb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]
2018-07-02 added gnd, 5x 9vac pins, moved c1 closer to input circuit
    [C64Saver2.kicad_pcb, C64Saver2.sch]
2018-07-03 eddited schematic of addon board
    [C64Saver2-addon.kicad_pcb, C64Saver2-addon.sch]
2018-07-04 SOP4 model
    [C64Saver2-addon.kicad_pcb, C64Saver2.sch, _saved_C64Saver2-addon.sch]
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2018-07-05 another regulator on 5v to protect the ina219 and iso1541
    [C64Saver2-addon.sch]
2018-07-08 fit to hammond1591, larger board.
    [C64Saver2-addon.kicad_pcb, C64Saver2-addon.sch, C64Saver2.kicad_pcb]
2018-07-08 hammond1551G. It will be a tight fit !
    [C64Saver2-addon.kicad_pcb, C64Saver2-addon.sch]
2018-07-10 addon board component placement done. layout begun.
    [C64Saver2-addon.kicad_pcb, C64Saver2-addon.sch]
2018-07-11 more routing. mostly power nets remaining
    [C64Saver2-addon.kicad_pcb]
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2018-07-12 included 2.0beta (throughhole) and 2.1 smd is the upcomming version
    [C64Saver2-addon.kicad_pcb, C64Saver2-addon.sch, C64Saver2.kicad_pcb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]
2018-07-22 Release 2.1 and addon 1.0
    [C64Saver2-B.Cu.gbl, C64Saver2-B.Mask.gbs, C64Saver2-B.SilkS.gbo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]
2018-08-08 Editting V2.2. R1 was rotated. why.
    [C64Saver2-B.Cu.gbl, C64Saver2-B.Mask.gbs, C64Saver2-B.SilkS.gbo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]
2018-08-08 Remove gerbers from sources. See Releases for gerbers.
    [C64Saver2-B.Cu.gbl, C64Saver2-B.Mask.gbs, C64Saver2-B.SilkS.gbo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]
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2018-08-16 release saver v2.2
    got fix for rotated resistor
    [C64Saver2.kicad_pcb, C64Saver2.sch]
2018-09-02 working makefile and helloworld example
    [C64Saver2-addon-B.Cu.gbl, C64Saver2-addon-B.Mask.gbs, C64Saver2-addon-B.SilkS.gbo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]
2018-09-08 Change: ATtiny footprint, ADC used with reset input
    [C64Saver2-addon.kicad_pcb, C64Saver2-addon.sch]
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2018-09-16 c64 saver 2 bom with elfa order numbers
    [c64Saver2-bom.ods]
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2018-09-23 New layout new routing. Resistor divider to support low Vth. #13
    [C64Saver2.kicad_pcb, C64Saver2.sch, c64Saver2-bom.ods]
2018-09-23 I suppose saving the design helps #13
    [C64Saver2.kicad_pcb]
2018-09-23 Addon board ready for new release #9
    [C64Saver2-addon.kicad_pcb, C64Saver2-addon.sch]
2018-09-24 WTF, text on titleblock on copper layer???
    [C64Saver2-addon-B.Cu.gbl, C64Saver2-addon-B.Mask.gbs, C64Saver2-addon-B.SilkS.gbo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]
2018-10-09 Rotated 3D drawing of D1 on addon board
    Rotated only the 3D drawing of D1. The layout is the same.
    [C64Saver2-addon.kicad_pcb]
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2018-10-21 fixed CPU clock improved I2C timings
    [ina219.c, main.c]
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2018-11-01 added stop condition on startup to prevent i2c garbage interference
    [ina219.c]
2018-11-04 addonboard: 5V moved to VIN+, and fixed SDA2 and SCL2. #16 #17
    [C64Saver2-addon.kicad_pcb, C64Saver2-addon.sch]
2018-11-04 troubleshooting SDA always high bug
    [ina219.c, main.c]
2018-11-08 4k7 pullups + readme
    [C64Saver2-addon.sch]
2018-11-11 Swapped HOLD_ with SENSE_VAC #18
    [C64Saver2-addon.kicad_pcb, C64Saver2-addon.sch]
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2019-05-20 MLCC 1210 cap and optoisolators changed to Package_SO:SOIC-4_4.55x2.6mm_P1.27mm
    Not finished routing. Needs more of the 1210 caps.
    [C64Saver2-addon-2019-05-19-18-52-40.sch, C64Saver2-addon.kicad_pcb]
2019-05-23 Addon Board 1.3 (2019-05-24)
    - Changed optocoupler footprint to more common SOIC-4_4.55x2.6mm_P1.27mm
    - Larger 5V regulator on 9vac side for less heat
    - replaced 100uF tantalum with 3x 47uF 1206 MLCC
    - kicad 5.1.0 project
    [C64Saver2-addon-BOM.csv, C64Saver2-addon.kicad_pcb, C64Saver2-addon.sch]
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2019-05-24 year and version on silkscreen
    switched to kicad 5.1.0 -> 5.1.2
    [C64Saver2-addon.kicad_pcb]
2019-06-23 kicad 5.1.0 -> 5.1.2
    [C64Saver2-addon.kicad_pcb, C64Saver2-addon.sch]
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2019-07-16 Revert "Delete C64Saver2-addon-BOM.txt"
    This reverts commit ba7545e9be7d77e44fc48137fce718ff76d0ae6d.
2019-08-25 Relay Hold Addon Board 0.2
    [relayhold board.kicad_pcb, relayhold board.sch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]
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2020-08-29 Updated bom is in the readme. This bom file was outdated. Deleteing it.
    [c64Saver2-bom.ods]
2020-08-29 Added IN/OUT to bottom silkscreen. upped project to Kicad 5.1.2
    [C64Saver2-2020-08-30-00-46-34.sch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]
2020-09-12 C64 Saver 2.5 ready for prototype
    [C64Saver2-B_Cu.gbl, C64Saver2-B_Mask.gbs, C64Saver2-B_SilkS.gbo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]
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2020-09-13 Added old v2.4 files in C64 Saver 2.4 folder
    [C64Saver2-2020-08-30-00-46-34.sch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]
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2023-03-20 THT 2.6 update. renamed some folders to separate SMD and THT versions.
    [C64 Saver Tester.kicad_pcb, C64 Saver Tester.sch, C64Saver2-2020-08-30-00-46-34.sch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]
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2023-03-20 removed the c64 saver tester project.
    [C64 Saver Tester.kicad_pcb, C64 Saver Tester.sch, C64Saver2.kicad_sch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]
2023-03-21 SMD version 2.6 layout and schematics. Both THT and SMD are now on same version. should have same references.
    [C64Saver2.kicad_pcb, C64Saver2.kicad_sch]
2023-03-22 layout for tht 2.6. added connector for leds as alternative to smd leds
    [C64Saver2.kicad_pcb, C64Saver2.kicad_sch]
2023-03-25 Updated Throughole version (2.6). Gerbers, BOM, PDF etc. Moved old versions to folders. Might remove later
    [C64Saver2-B_Cu.gbl, C64Saver2-B_Mask.gbs, C64Saver2-B_SilkS.gbo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]
2023-04-01 Preparing for Saver 2.6, moving 2.5 and 2.4 to oldfiles folder
    [C64Saver2-2020-08-30-00-46-34.sch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]
2023-04-02 finished OCP version ready for testing
    [C64Saver2-2020-08-30-00-46-34.sch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]
2023-04-02 added digi-key order numbers to ibom
    [C64Saver2-B_Cu.gbl, C64Saver2-B_Mask.gbs, C64Saver2-B_Paste.gbp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]
2023-04-02 Added ibom for addon board, and put the elfa+RS components into the parts/ibom
    [C64Saver2-addon-B_Cu.gbl, C64Saver2-addon-B_Mask.gbs, C64Saver2-addon-B_Paste.gbp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]
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
